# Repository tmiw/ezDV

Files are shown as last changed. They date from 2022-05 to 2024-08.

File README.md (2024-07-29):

# ezDV

This repository contains both the hardware and firmware for a portable battery-powered device that can
(de)modulate [FreeDV](https://freedv.org/) from an attached radio. The board is centered around the 
following components:

* [Espressif ESP32-S3](https://www.espressif.com/sites/default/files/documentation/esp32-s3_datasheet_en.pdf)
* [TLV320 digital audio codec chip](https://www.ti.com/cn/lit/ds/symlink/tlv320aic3254.pdf?ts=1651153824042) produced by Texas Instruments ([application notes](https://www.ti.com/lit/an/slaa408a/slaa408a.pdf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)).

## User's guide

See [here](https://tmiw.github.io/ezDV/) for the latest copy of the user manual for ezDV, which describes its
general use and operation.

## Building the firmware

Install [ESP-IDF v5.3](https://docs.espressif.com/projects/esp-idf/en/v5.3/esp32s3/get-started/index.html) and then run the following:

```
. /path/to/esp-idf/export.sh
git submodule update --init --checkout --recursive
cd firmware
idf.py build
```
## Flashing the firmware

### Using ESP-IDF

Turn on ezDV (see below) and plug it into your computer's USB port, then run the following:

```
idf.py -p /dev/ttyxxx0 flash monitor
```

Where `/dev/ttyxxx0` (or `COMx:` on Windows) is the serial port created by your operating system after plugging ezDV in.

### Using ESP Flash Tool

On Windows, you can use the ESP Flash Tool to flash ezDV. This does not require installation of ESP-IDF.

1. Download the ESP Flash Tool from https://www.espressif.com/en/support/download/other-tools.
2. Decompress all of the files in the ZIP file and execute flash\_download\_tool\_3.9.3.exe.
3. Select "ESP32-S3" for "ChipType", "Develop" for "WorkMode" and "USB" for "LoadMode" as shown below:

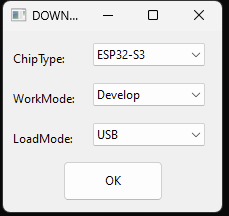
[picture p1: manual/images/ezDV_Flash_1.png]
ESP Flash Tool step 3


4. Add rows for each of the .bin files in the resulting screen:

| File Name | Offset |
|---|---|
| bootloader.bin | 0x0 |
| partition-table.bin | 0x8000 |
| ota\_data\_initial.bin | 0xF000 |
| ezdv.bin | 0x20000 |
| http_0.bin | 0x7F8000 |

Additionally, check each of the checkboxes to the left of the file name. It should look something like this, with each of the rows having a green background:

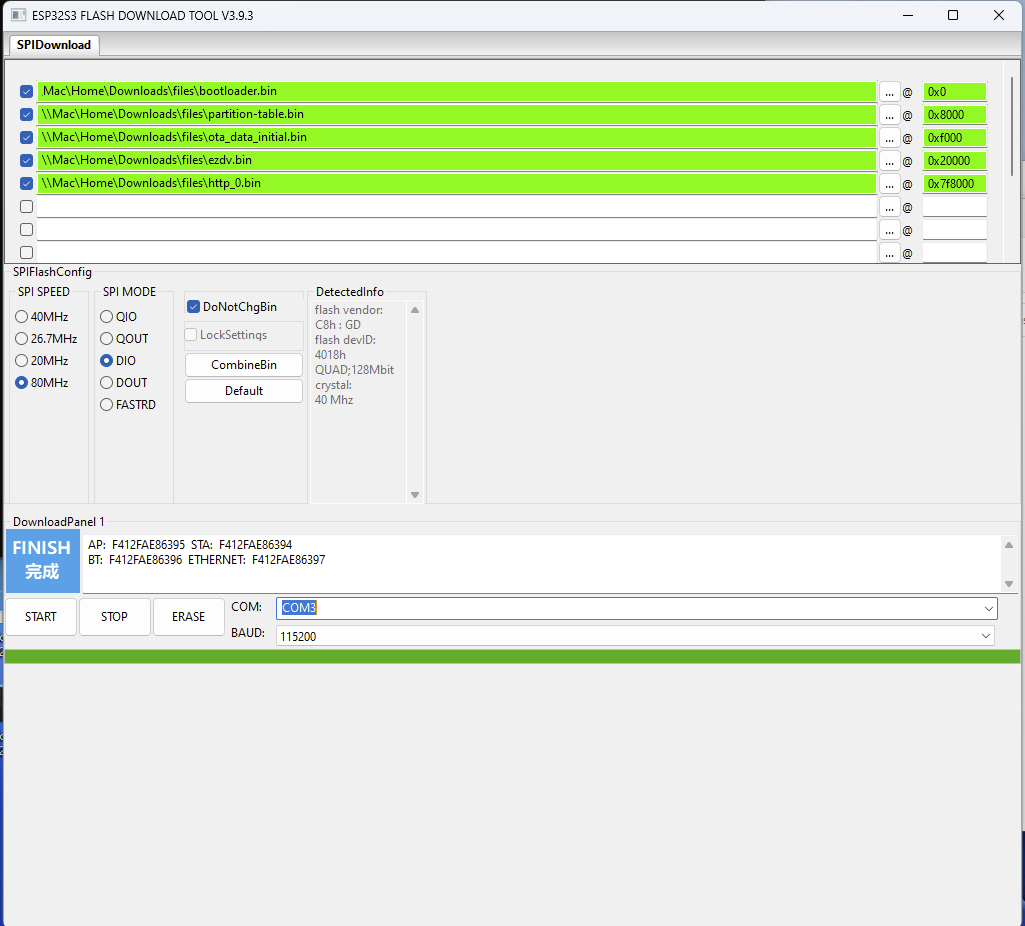
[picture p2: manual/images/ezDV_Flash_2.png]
ESP Flash Tool step 4


5. Set "SPI SPEED" to "80 MHz" and "SPI MODE" to "DIO".

6. Plug ezDV into your computer using a USB-C cable and turn it on by holding down the Mode button for a few seconds. Device Manager should show a new COM port named "USB/JTAG serial debug unit" or similar. Enter this COM port into the "COM" field in the application.

7. (Optional) Push the ERASE button. This will show a green "SYNC" indicator for a bit followed by "Download" and then "FINISH" as per the above screenshot. *Note: There will be no firmware installed on the board once this step finishes. You will need to reconfigure ezDV after new firmware has been flashed.*

8. Push the START button. This will go through the same indicators as step 1 but this time will also have a progress bar indicating how far it's gotten in flashing the new software. 

9. Push the STOP button and then close the application. Open the ezDV enclosure and briefly push/release the "Reset" button on the right hand side of the board. If everything went well, you'll see the four LEDs light up for a few seconds indicating that ezDV is booting normally.

### Using esptool

You can also use [esptool](https://github.com/espressif/esptool). For example:

```
esptool esp32s3 -p /dev/cu.usbmodem14101 -b 460800 --before=default_reset --after=hard_reset write_flash --flash_mode dio --flash_freq 80m --flash_size detect 0x0 bootloader.bin 0x20000 ezdv.bin 0x8000 partition_table/partition-table.bin 0xf000 ota_data_initial.bin 0x7f8000 http_0.bin
```

### Recovering from a bad flash

If the flash process fails (or you are flashing for the first time), you can manually place ezDV into flash mode by holding down the "GPIO0/Flash" button while pushing the "Reset" button on the board. Hold "GPIO0/Flash" for a second or so after releasing Reset, then release. You can then use ESP-IDF, the ESP Flash Tool or esptool to flash ezDV with working firmware.

## Contributing to ezDV

Pleae read the [Theory of Operation](https://github.com/tmiw/ezDV/blob/main/THEORY_OF_OPERATIONS.md) document for more information about the general hardware and software architecture, along with information about how to contribute changes to ezDV.

## License

This project is subject to the terms of the [TAPR Open Hardware License v1.0](https://tapr.org/the-tapr-open-hardware-license/) (schematics, 
other hardware documentation) and [GNU General Public License v3.0](https://www.gnu.org/licenses/gpl-3.0.en.html) (firmware).

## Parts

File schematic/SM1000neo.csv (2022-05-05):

Comment | Designator | Footprint | LCSC
10uF | C1,C2,C3,C4 | Capacitor_SMD:C_0402_1005Metric | C315248
1uF | C5 | Capacitor_SMD:C_0402_1005Metric | C14445
0.1uF | C6,C7,C10,C11,C12 | Capacitor_SMD:C_0402_1005Metric | C1525
47uF | C8,C9 | Capacitor_SMD:C_0603_1608Metric | C140782
PTT_LED | D1 | Diode_SMD:D_0603_1608Metric | C2286
SYNC_LED | D2 | Diode_SMD:D_0603_1608Metric | C165982
OVL_LED | D3 | Diode_SMD:D_0603_1608Metric | C2286
NET_LED | D4 | Diode_SMD:D_0603_1608Metric | C193191
Radio_Jack | J1 | Connector_Audio:Jack_3.5mm_PJ320D_Horizontal | C95562
User_Jack | J2 | Connector_Audio:Jack_3.5mm_PJ320D_Horizontal | C95562
nanoESP32-S3-Left | J3 | Connector_PinHeader_2.54mm:PinHeader_1x21_P2.54mm_Vertical
nanoESP32-S3-Right | J4 | Connector_PinHeader_2.54mm:PinHeader_1x21_P2.54mm_Vertical
MBT3904DW1T1 | Q1,Q2,Q3 | Package_TO_SOT_SMD:SOT-363_SC-70-6 | C110150
2.7K | R1,R11,R16,R18,R19,R21 | Resistor_SMD:R_0603_1608Metric | C269437
100 | R10,R17 | Resistor_SMD:R_0603_1608Metric | C105588
50 | R14,R20 | Resistor_SMD:R_0603_1608Metric | C2759402
4.7K | R2,R8,R22,R24 | Resistor_SMD:R_0603_1608Metric | C99782
1M | R23,R25 | Resistor_SMD:R_0603_1608Metric | C22935
10 | R3 | Resistor_SMD:R_0603_1608Metric | C25202
27 | R4,R5,R6,R7 | Resistor_SMD:R_0603_1608Metric | C25190
3.3K | R9,R12,R13,R15 | Resistor_SMD:R_0603_1608Metric | C22978
PTT_Button | SW1 | Button_Switch_SMD:SW_SPST_TL3342 | C2886898
Mode_Button | SW2 | Button_Switch_SMD:SW_SPST_TL3342 | C2886898
Vol_Up_Button | SW3 | Button_Switch_SMD:SW_SPST_TL3342 | C2886898
Vol_Down_Button | SW4 | Button_Switch_SMD:SW_SPST_TL3342 | C2886898
TLV320AIC3254IRHBR | U1 | SM1000neo:IC_ADS125H01IRHBT | C9925

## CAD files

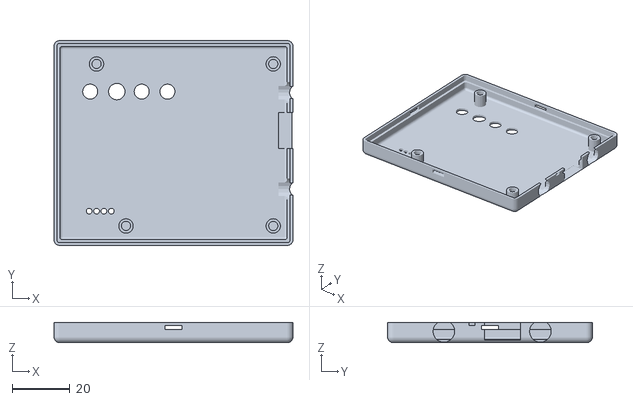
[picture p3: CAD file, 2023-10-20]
enclosure/user/enclosure-top.stl
82.5 x 70.7 x 6.98

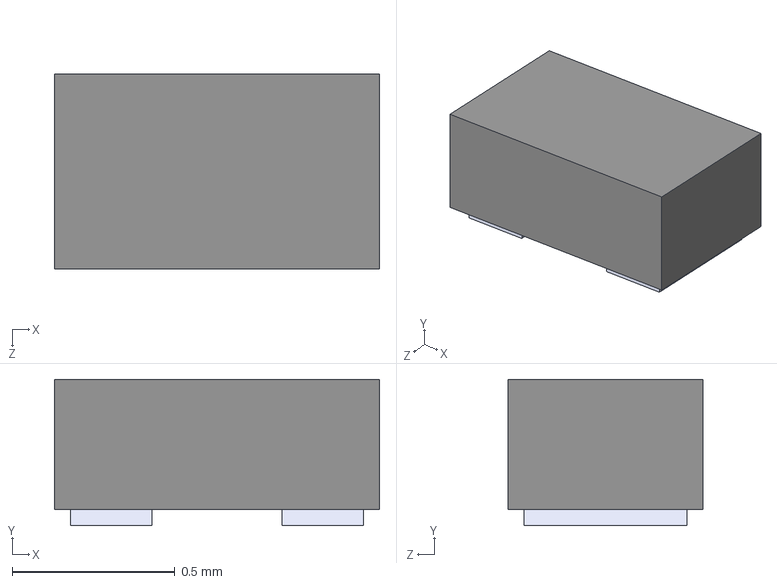
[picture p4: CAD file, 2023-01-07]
schematic/v0.7/TPD1E10B06DPYR.step
1.00 x 0.45 x 0.6 mm

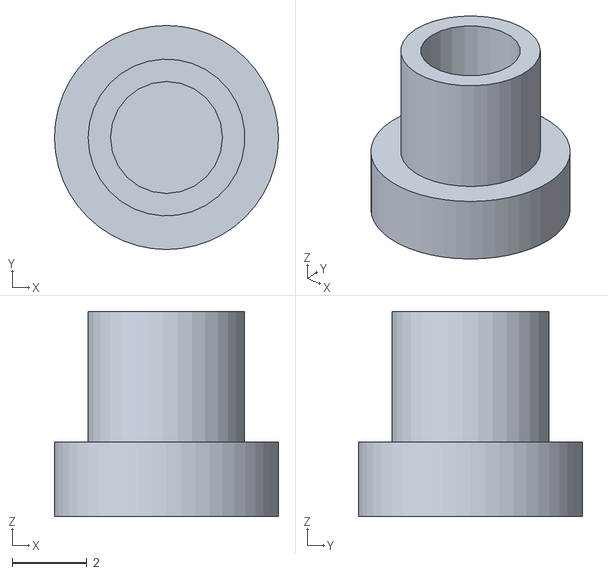
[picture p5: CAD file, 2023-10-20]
enclosure/user/enclosure-button.stl
6.00 x 6.00 x 5.50

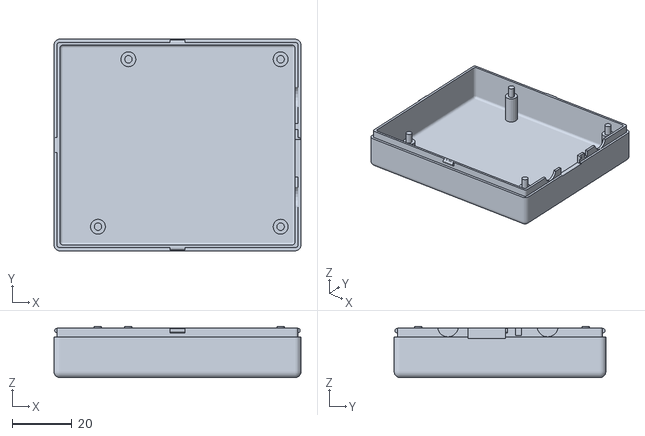
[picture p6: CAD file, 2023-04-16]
enclosure/user/enclosure-bottom.stl
82.5 x 70.7 x 17.1

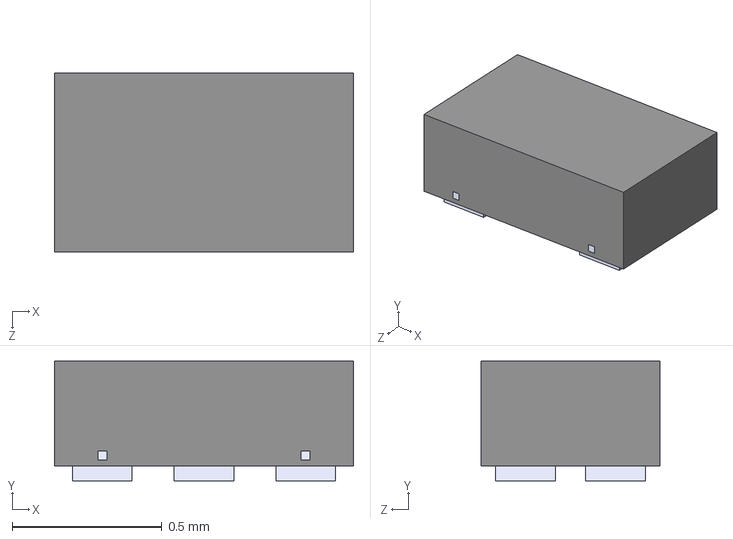
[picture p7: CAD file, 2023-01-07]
schematic/v0.7/ESD122DMXR.step
1.00 x 0.4 x 0.6 mm

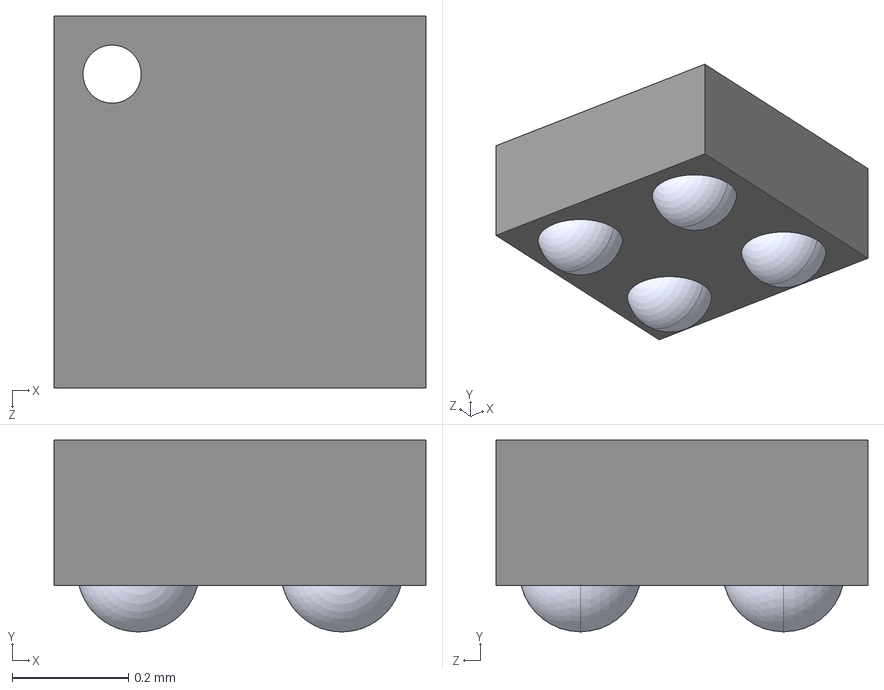
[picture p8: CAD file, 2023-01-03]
schematic/v0.7/BGA4N35P2X2_64X64X33N.step
0.64 x 0.33 x 0.64 mm

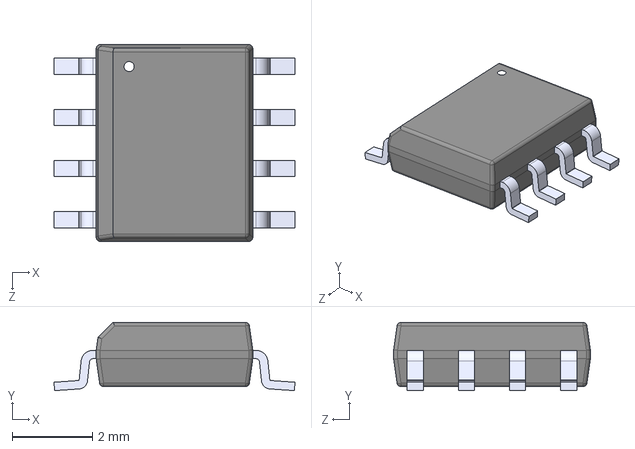
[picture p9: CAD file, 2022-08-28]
schematic/v0.7/TP4056.step
6.00 x 1.70 x 4.90 mm

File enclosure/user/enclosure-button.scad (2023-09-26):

// Makes the preview renders look better.
$fa = 1;
$fs = 0.4;

// Whether to print a taller buttons (typically used when printing the taller enclosure).
printTallerButtons = false;

rotate([0, 180, 0]) {
    translate([0, 0, -3]) {
        if (printTallerButtons) {
            difference() {
                cylinder(h = 15, r = 2.1, center = true);
                translate([0, 0, -12]) cylinder(h = 10, r = 1.5, center = true);
            }
        } else {
            difference() {
                cylinder(h = 5, r = 2.1, center = true);
                translate([0, 0, -4]) cylinder(h = 10, r = 1.5, center = true);
            }
        }
    }

    translate([0, 0, printTallerButtons ? 3.5 : -1]) {
        cylinder(h = 2, r = 3, center = true);
    }
}

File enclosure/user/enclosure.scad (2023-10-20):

// Makes the preview renders look better.
$fa = 1;
$fs = 0.4;

// BEGIN configuration

// Whether to print a taller enclosure to fit e.g. pin headers.
// Note: this weirdly has to be above the include line for some reason.
printTallerEnclosure = false;

include <../library/YAPP_Box/library/YAPPgenerator_v14.scad>

// Which sides to print. Base = bottom, lid = top.
// One or the other can be disabled to print on smaller print beds.
printBaseShell      = false;
printLidShell       = true;

// END configuration

wallThickness       = 2.0;
basePlaneThickness  = 2.0;
lidPlaneThickness   = 1.0;

// Total height of box = basePlaneThickness + lidPlaneThickness 
//                     + baseWallHeight + lidWallHeight

baseWallHeight      = 14.5;
lidWallHeight = (printTallerEnclosure) ? 14.5 : 3.5;
echo(lidWallHeight);
echo(printTallerEnclosure);

pcbLength           = 69.85;
pcbWidth            = 64.70;
pcbThickness        = 1.6;
                            
// padding between pcb and inside wall
paddingFront        = 1;
paddingBack         = 7.62;
paddingRight        = 1;
paddingLeft         = 1;

// ridge where Base- and Lid- off the box can overlap
// Make sure this isn't less than lidWallHeight
ridgeHeight         = 3;
ridgeSlack          = 0.2;
roundRadius         = 2.0;  // don't make this to big..

//-- How much the PCB needs to be raised from the base
//-- to leave room for solderings and whatnot
standoffHeight      = 11.0;
pinDiameter         = 2.5;
pinHoleSlack        = 0.5;
standoffDiameter    = 5;

pcbStands = [
    [ 5.08, 5.08, yappBoth, yappPin ],
    [ 15.24, 60.96, yappBoth, yappPin ],
    [ 66.04, 5.08, yappBoth, yappPin ],
    [ 66.04, 60.96, yappBoth, yappPin ]
];

cutoutsFront = [
    [14.97, 2.5, 7.5, 7, 0, yappCircle, yappCenter ],
    [48.26, 2.5, 7.5, 7, 0, yappCircle, yappCenter ],
    [21.75, -1.5, 12.5, 7, 0, yappRectangle ],
    [37.56, -0.5, 2, 1, 0, yappRectangle ]
];

snapJoins = [
    [(shellLength/2)-2.5, 5, yappLeft, yappRight],
    [(shellWidth/2)-2.5, 5, yappFront, yappBack]
];

cutoutsLid = [
    // Buttons
    /*[3, 14.63, 4, 4, 0, yappRectangle, yappCenter],
    [11.89, 14.63, 4, 4, 0, yappRectangle, yappCenter],
    [20.78, 14.63, 4, 4, 0, yappRectangle, yappCenter],
    [29.67, 14.63, 4, 4, 0, yappRectangle, yappCenter],*/
    
    [2.87, 14.62, 5.2, 5.2, 0, yappCircle, yappCenter],
    [12.06, 14.62, 5.7, 5.2, 0, yappCircle, yappCenter],
    [20.65, 14.62, 5.2, 5.2, 0, yappCircle, yappCenter],
    [29.54, 14.62, 5.2, 5.2, 0, yappCircle, yappCenter],
    
    // Status LEDs
    [2.54, 55.88, 2, 2, 0, yappCircle],
    [5.08, 55.88, 2, 2, 0, yappCircle],
    [7.62, 55.88, 2, 2, 0, yappCircle],
    [10.16, 55.88, 2, 2, 0, yappCircle],
];

YAPPgenerate();

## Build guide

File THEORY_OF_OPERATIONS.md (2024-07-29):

# Theory of Operation

## Introduction

This document describes the general architecture of ezDV and provides details that may be useful for those developers
that want to contribute to the project.

## Hardware Architecture

ezDV uses a ESP32-S3 microcontroller to execute the firmware in this repository. This firmware interfaces with several 
peripherals to perform its basic functionality:

* Texas Instruments TLV320AIC3254 audio codec chip over I2C (to provide configuration information) and I2S (for audio
I/O) to send and receive audio data to a wired headset and/or a radio.
* MAX17048 over I2C to handle battery status measurement (i.e. remaining battery capacity).
* Buttons and LEDs using the ESP32-S3's built-in GPIOs.

## Software Architecture

### System Components

The ezDV firmware is split into several tasks to perform various actions. These tasks are divided into several categories:

* Audio (`firmware/audio`) -- handles higher level audio-related tasks
    * AudioMixer - Mixes two audio streams together
    * BeeperTask - Generates CW beeps based on provided input
    * FreeDVTask - Passes audio to/from the [Codec2](https://github.com/drowe67/codec2) library for encoding and decoding
    * VoiceKeyerTask - Handles voice keyer functionality
* Drivers (`firmware/drivers`) -- handles communication with peripherals
    * ButtonArray - handles processing of interrupts due to button presses
    * LedArray - handles display of built-in LEDs
    * MAX17048 - handles communication with the MAX17048 fuel gauge chip over I2C
    * TLV320 - handles communication with the TLV320 audio codec chip
* Network (`firmware/network`) -- handles logic involving Wi-Fi communication
    * FlexRadio support (`firmware/network/flex`)
        * FlexTcpTask - handles CAT control of a configured Flex radio
        * FlexVitaTask - handles audio I/O (analog and digital) to/from a configured Flex radio
    * Icom support (`firmware/network/icom`)
        * IcomSocketTask - handles UDP connection to one of the Icom remote ports (control, audio, CAT control)
    * Network interfaces (`firmware/network/interfaces`)
        * WirelessInterface - handles bringup/teardown of the built-in Wi-Fi on the ESP32.
        * EthernetInterface - handles bringup/teardown of the W5500 Ethernet module (if attached).
    * FreeDVReporterTask - handles reporting to [FreeDV Reporter](https://qso.freedv.org/)
    * HttpServerTask - handles serving of ezDV's built-in web interface
    * NetworkTask - handles bringup and teardown of the configured network interfaces (Wi-Fi, Ethernet)
* Storage (`firmware/storage`) -- handles configuration and firmware storage
    * SettingsTask - handles storage of configuration settings
    * SoftwareUpdateTask - handles updating of the ezDV firmware from the web interface
* User Interface (`firmware/ui`) -- handles the physical interface with the user
    * FuelGaugeTask - executes when ezDV is turned off (but plugged into USB power) and provides live charging updates via the built-in LEDs
    * RFComplianceTesTask - executes when ezDV is in Hardware Test Mode and provides ways to perform basic validation of the physical hardware
    * UserInterfaceTask - executes when ezDV is turned on normally and directs the rest of the system to perform tasks based on input from buttons

These tasks inherit a thin wrapper around FreeRTOS/ESP-IDF called `DVTask` (located in `firmware/task`) and optionally contain one or more `DVTimer` 
instances if periodic execution of code is required. 

### Inter-Component Messaging

`DVTask` enables the usage of a publish/subscribe model for each task's public interface. This prevents interaction with a task's private data,
reducing the likelihood of certain classes of bugs (such as race conditions). Subscribing to messages is typically done by calling the 
`registerMessageHandler()` method of `DVTask` with the name of the method to call upon receiving a certain type of message. Message handler
methods have a signature similar to the following:

```c++
void ClassName::onHandleMessage_(DVTask* originTask, MessageType* message)
{
    // actions here
}
```

`MessageType` is a class that typically inherits from `DVTaskMessageBase`. `DVTaskMessageBase` is a template class
that takes an integer message ID and a string corresponding to the name of the message category (defined by the `DV_EVENT_DECLARE_BASE`
macro inside the message's .h file and `DV_EVENT_DEFINE_BASE` inside the corresponding .cpp file. For example, in an .h file, you may
have something similar to the following:

```c++
extern "C"
{
    DV_EVENT_DECLARE_BASE(FREEDV_MESSAGE);
}

enum FreeDVMessageTypes
{
    SYNC_STATE = 1,
    // additional message types here
};

class FreeDVSyncStateMessage : public DVTaskMessageBase<SYNC_STATE, FreeDVSyncStateMessage>
{
    // definition here
};
```

and in the .cpp file, you'd have only the following:

```c++
extern "C"
{
    DV_EVENT_DEFINE_BASE(FREEDV_MESSAGE);
}
```

In each message type, the contents of the message are typically defined as public properties as `DVTask` internally
treats them similarly to C structs. Additionally, the size of the message should be known in advance and constant
(for example, the size shouldn't vary based on the length of a string inside the message).

To send a message to a component, tasks typically call the `publish()` method, i.e.

```c++
MessageType message(1, 2, 3);
publish(&message);
```

`publish()` sends the provided message to all tasks that are subscribed to it. Depending on the message type,
this can cause multiple tasks to process the message at the same time. Alternatively, if a task has a pointer
to another, it can use `post()` on the task instead to send only to that task. For example:

```c++
DVTask* destinationTask = getDestinationTask();
MessageType message(1, 2, 3);
destinationTask->post(&message);
```

### Audio Routing

#### Receive

Receive audio is routed through ezDV as follows:

```mermaid
flowchart TD
    A[Radio] -->|RX signal| B(TLV320 input)
    B --> |codec2 FIFO| C(FreeDVTask)
    C --> |Decoded signal| E(AudioMixer)
    D[UserInterface] -->|CW beeps| E
    E --> F(TLV320 output)
    F --> G(Headset)
```

#### Transmit

Transmit audio is routed similarly to receive audio. The main difference is that `AudioMixer` is not used:

```mermaid
flowchart TD
    A[Headset] --> B(TLV320 input)
    B --> |codec2 FIFO| C(FreeDVTask)
    C --> |Encoded signal| D(TLV320 output)
    D -->|TX signal| E(Radio)
```

## Contributing to ezDV

To contribute to ezDV, simply fork this repo and make the required changes, then open a pull request. Note that
for a PR to be merged, the following must currently occur:

* All GitHub actions must pass successfully (i.e. no compiler errors).
* For new/modified functionality, the user manual (in the `manual` folder) must be updated accordingly.

If you have any questions, feel free to reach out in the pull request or by emailing the digitalvoice mailing list.
Thank you for your help in making ezDV even better!

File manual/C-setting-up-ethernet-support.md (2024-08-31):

# Appendix: Setting Up Ethernet Support

Experimental support exists for Ethernet on ezDV. In order to enable Ethernet support, some hardware modifications are required 
to be able to attach it to a [W5500 Ethernet module](https://www.amazon.com/dp/B08KXM8TKJ?psc=1&ref=ppx_yo2ov_dt_b_product_details):

1. Remove the main ezDV board from its enclosure and disconnect the battery from the bottom.
2. Solder wires from the positions indicated below on the ESP32 module (near top of board) to their corresponding locations on the W5500 module:

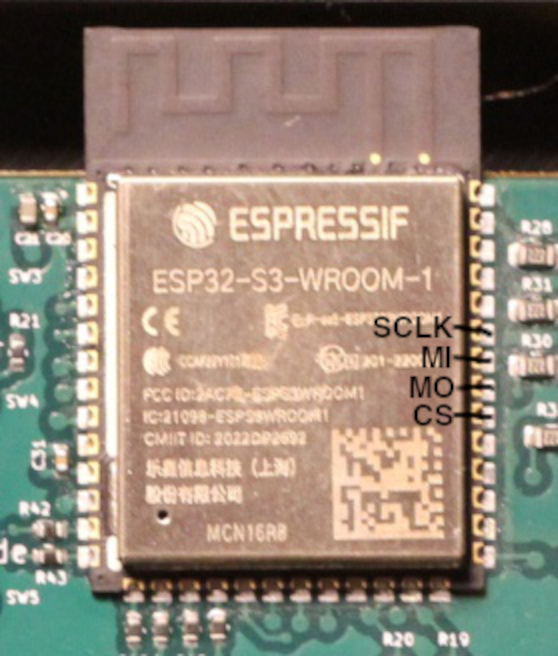
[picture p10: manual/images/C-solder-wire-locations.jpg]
Soldering locations for wires going to W5500 module


3. Solder power and ground wires from ezDV to the W5500. These can be taken from J7 (square pin is 3.3V, bottom pin is GND). Note that J7 is always powered.

4. Reattach the battery and place ezDV back in its enclosure. You may need to cut out a hole in the enclosure using side cutters or similar to allow the previously-soldered wires to be routed out of the enclosure.

5. Attach an Ethernet cable to the W5500 module and to your router or switch. 

6. Turn on ezDV. If Wi-Fi is already configured, it is recommended to disbale it to prevent network connections from inadvertently going over the wrong interface. Once this is done, restart ezDV.

7. After a few minutes, look for it on the router's list of attached devices after a few minutes. Note its IP for future use. It should now be communicating over Ethernet instead of Wi-Fi.

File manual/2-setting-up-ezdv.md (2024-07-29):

# Setting up ezDV

There are several steps required to get ezDV up and running with your radio.

## Initial assembly

If ezDV did not already come with a battery, you will need to obtain a 3.7V lithium polymer (LiPo) battery.
One recommended battery can be purchased [from Amazon](https://www.amazon.com/gp/product/B08214DJLJ/ref=ppx_yo_dt_b_search_asin_title?ie=UTF8&psc=1).

*WARNING: Do not puncture or otherwise damage lithium batteries as injury and/or property damage could result!
Neither the project nor its creator take responsibility for any damage or injury due to misuse of batteries. A 
battery with a protection module (such as the one linked above) is highly recommended.*

The battery should be plugged into the BT1 connector on the bottom of the ezDV circuit board, which is
the circled connector below:

The back of the ezDV circuit board with BT1 circled

Once a battery is attached, you should flip the switch to the right of the BT1 connector upwards (towards the back of the ezDV board)
to connect the battery to the rest of the board. This switch is designed to allow for long-term storage or shipping of ezDV without 
discharging the battery. Note that ezDV may power on immediately after flipping this switch; you can power it down by pushing
and holding the Mode button (second button from the top when looking downward) until red lights turn on on the right-hand side.

*Note: it is not recommended to use this switch for normal operation of ezDV. Some features require an orderly shutdown of ezDV
(which is accomplished by using the Mode button) and may not function properly if power is suddenly lost.*

Next, plug ezDV into a USB-C charger (similar to what would be done to charge a cell phone or portable power bank). A red LED
may light on the bottom of ezDV indicating that the battery is charging as well as some or all of the LEDs on the right hand side
(indicating its current state of charge in 25% increments). When ezDV is done charging, a green LED will turn on
and the red LED will turn off. This may take several hours or more depending on the state of the battery.

Finally, plug in a wired headset on the TRRS jack located on the right side of the ezDV board (when looking
from above). This headset should be wired for compatibility with Android phones, which is as follows:

* Tip: RX audio from ezDV
* Ring 1: RX audio from ezDV
* Ring 2: GND
* Shield: TX microphone audio to ezDV

Once attached, ezDV will appear as follows:

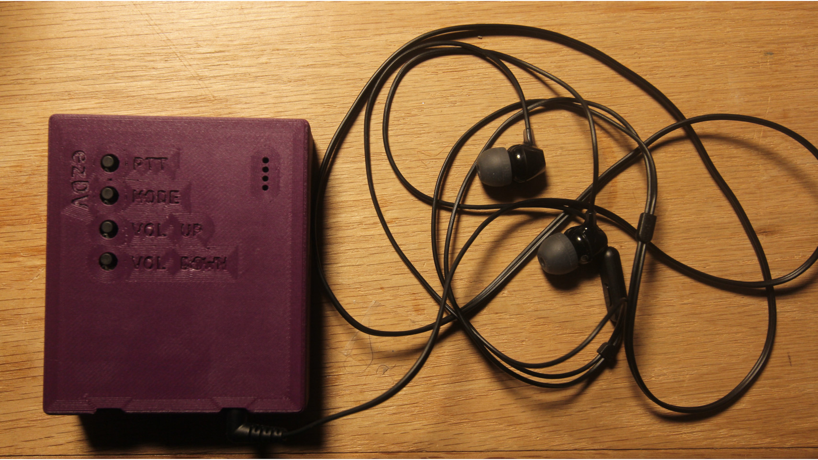
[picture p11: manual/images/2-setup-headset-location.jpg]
ezDV with headset attached


## Radio wiring

### Radios without network support

Radios without network support will need an interface cable. One end of this cable should 
be a male 3.5mm four conductor (TRRS) with the following pinout:

* Tip: TX audio from ezDV to your radio
* Ring 1: PTT to radio (this is connected to GND when you push the PTT button)
* Ring 2: GND
* Shield: RX audio from your radio to ezDV

There is also silkscreen labeling on the back of the board corresponding to the location of 
the radio jack that indicates the pinout. This jack is on the left hand side of ezDV when looking
downward at the front of the device.

More information on example wiring configurations for various radios can be found in the [Example Wiring Configurations](#appendix-example-wiring-configurations)
section.

### Radios with network support

If you have a radio that is capable of remote network access, you can configure ezDV to connect to the radio
over Wi-Fi or Ethernet. Currently this is supported only for the [FlexRadio](https://www.flexradio.com/) 
000/8000 series radios and the Icom IC-705.

#### Flex 6000/8000 series radios

Ensure that you can access your radio using the SmartSDR software from a PC on the same network (i.e. *not* using SmartLink).
Once this is confirmed, skip to [Initial Configuration](#initial-configuration).

#### Icom IC-705

Several settings will need to be adjusted in the IC-705 before it can be used with ezDV. See "Configuring Wi-Fi on the Icom IC-705"
or your radio's user manual for more information on configuring Wi-Fi.

## Initial configuration

To perform initial configuration of ezDV, push and hold both the Mode and Volume Down buttons at the same
time until all four of the LEDs on the right hand side of ezDV turn on.

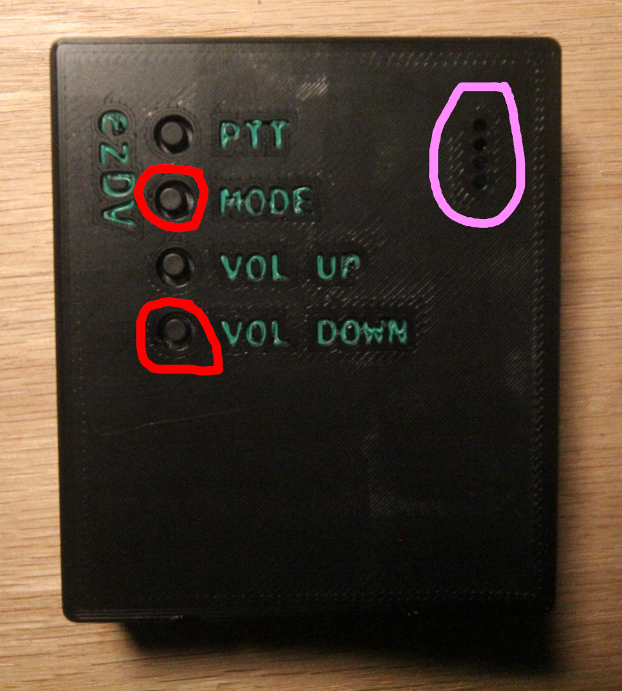
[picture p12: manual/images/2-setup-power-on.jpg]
ezDV showing the buttons to push and hold (red circles) and the location of the LEDs (pink circle)


Once the LEDs turn off, go to your PC or cell phone's Wi-Fi configuration and join a network named "ezDV xxxx",
where "xxxx" is the last few alphanumeric digits of its MAC address (a unique identifier for each network device). 
Once joined, open your Web browser and navigate to http://192.168.4.1/. You should see a page similar to the following:

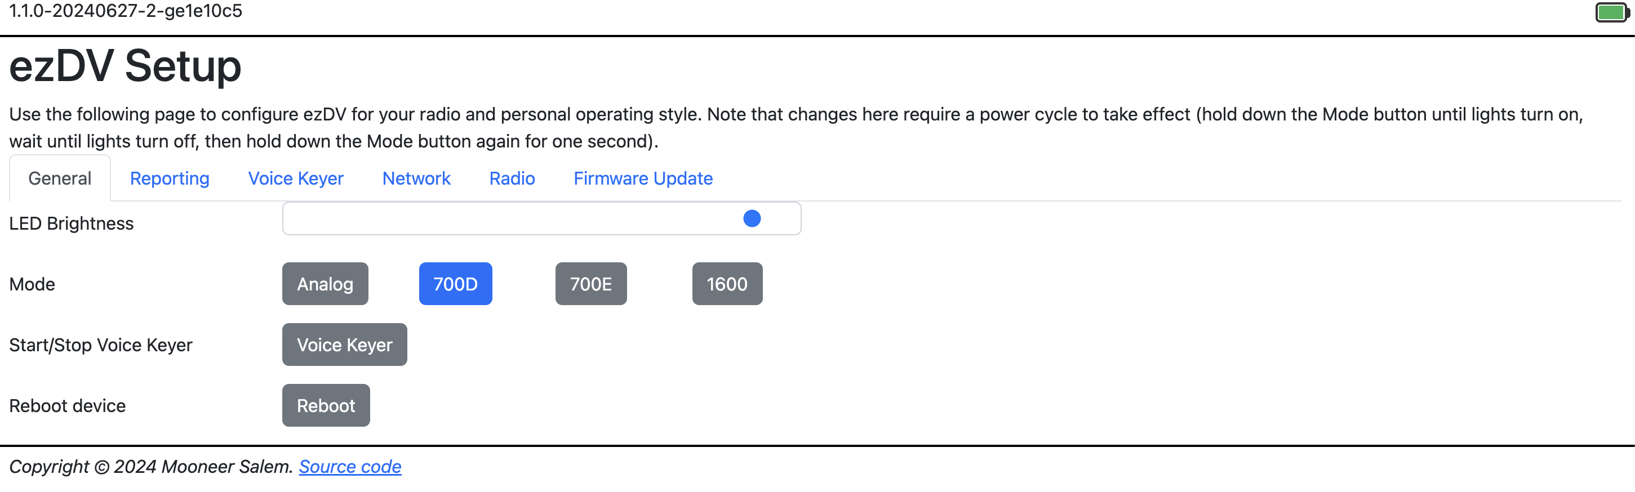
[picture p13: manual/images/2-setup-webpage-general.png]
Screenshot showing ezDV's main Web page


### Transmit audio levels

#### Flex 6000/8000 series

ezDV uses a hardcoded transmit level when connected to the Flex 6000/8000 series of radios, so adjusting the transmit level on 
ezDV has no effect.

#### Other radios

*Note: for the Icom IC-705, this can only be done after configuring Wi-Fi and the radio connection.*

ezDV's transmit audio levels will need to be adjusted to ensure that your radio does not indicate too much ALC, similar
to other HF digital modes. You can adjust the transmit audio by pushing the Volume Up or Volume Down buttons
while holding the PTT button as indicated below:

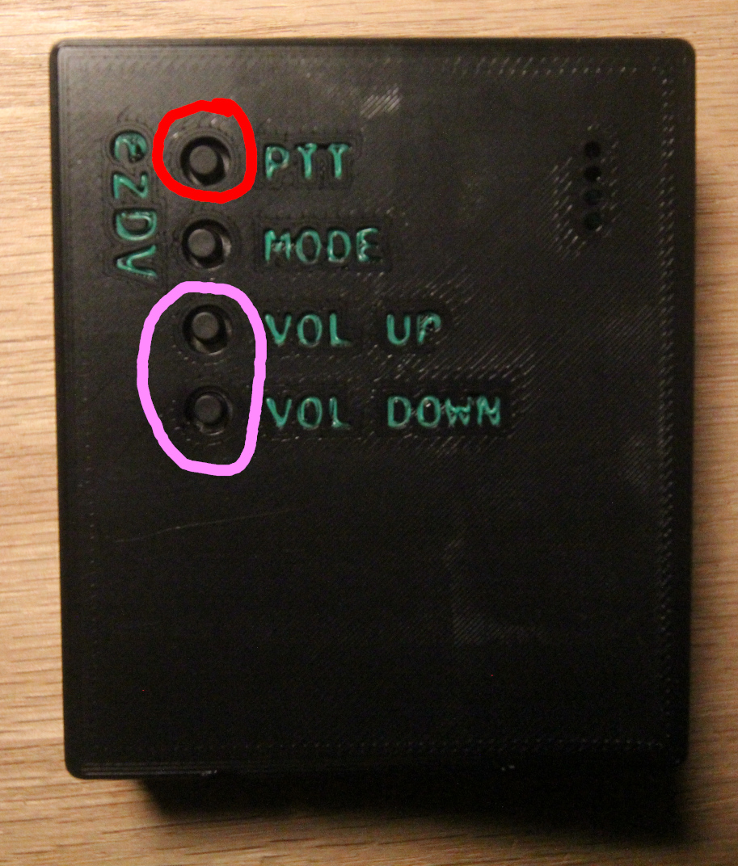
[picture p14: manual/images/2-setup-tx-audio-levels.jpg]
ezDV showing the PTT button (red circle) and the Volume Up/Down buttons (pink circle)


For most radios, ezDV's transmit level should be such that little to no ALC is indicated on the radio display. The specific 
ALC level required depends on the radio, so your radio's user manual is the best source for determining this. Alternatively,
you can increase the TX audio level until your power output stops increasing, then decrease it again until your power output
begins to decrease.

*Note: it's recommended to have your radio attached to a dummy load while adjusting your transmit audio levels to prevent
interference to other operators.*

### Network configuration

*Note: this is optional unless you are using a radio with network support or wish to use other Internet connected features
(such as reporting to [FreeDV Reporter](https://qso.freedv.org/) and [PSK Reporter](https://pskreporter.info)).*

Click or tap on the "Network" tab and check the "Enable Wi-Fi" checkbox. You'll see something similar to the following:

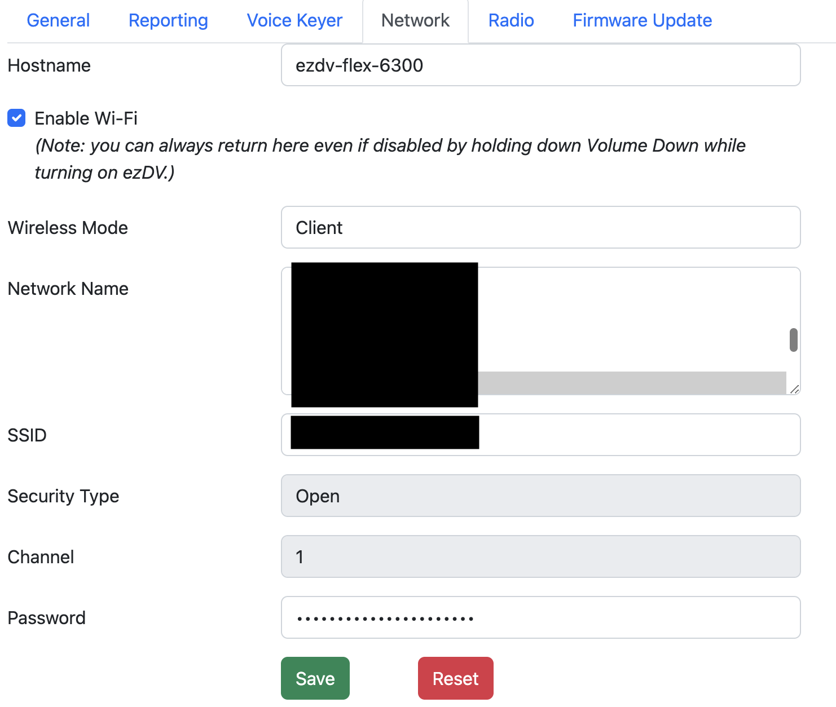
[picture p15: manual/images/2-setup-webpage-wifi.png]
ezDV showing the Network tab


*Note: experimental support exists for Ethernet on ezDV. See "Setting Up Ethernet Support" for more information.*

To connect ezDV to the network that your radio is on, select "Client" for "Wireless Mode". Select your Wi-Fi network from
the list that appears (which may take a few seconds while ezDV scans for your network) and enter its password (if required).
If desired, you can also change ezDV's name by modifying the "Hostname" field; this may allow you to access ezDV later by entering
this name instead of trying to find its IP address. Click or tap Save to save your Wi-Fi settings.

### Radio connection

*Note: this is optional unless you are using a radio with Wi-Fi support.*

Click on the "Radio" tab and check the "Use Network for Radio RX/TX" checkbox. Select your radio model in the "Radio Type"
drop-down list, which will bring up different fields depending on the radio being configured.

#### Flex 6000/8000 series

Select the name of your radio from the "Radio" drop-down list as shown below. Your radio's IP address should automatically
be filled in the "IP Address" field:

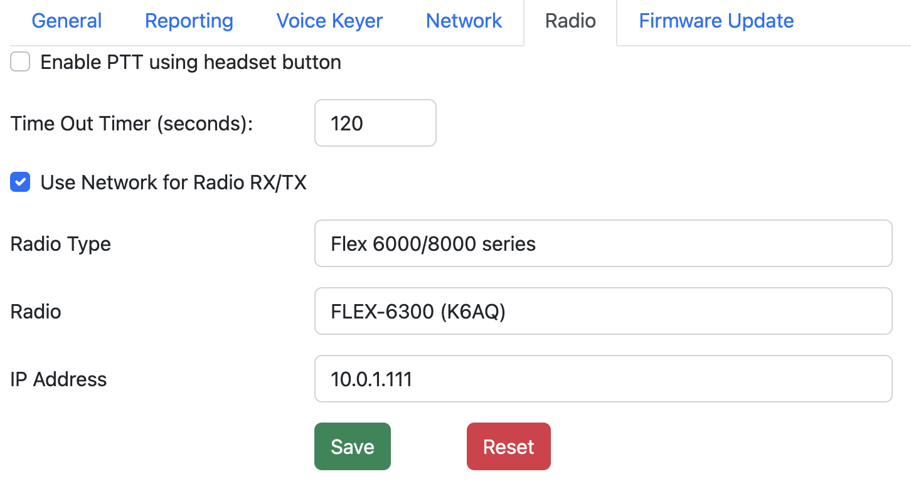
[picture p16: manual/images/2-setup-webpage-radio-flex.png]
ezDV showing a FlexRadio configuration


Click or tap Save to save the radio configuration.

#### Icom IC-705

Enter your radio's IP address, username and password that you saved when you configured Wi-Fi on the IC-705:

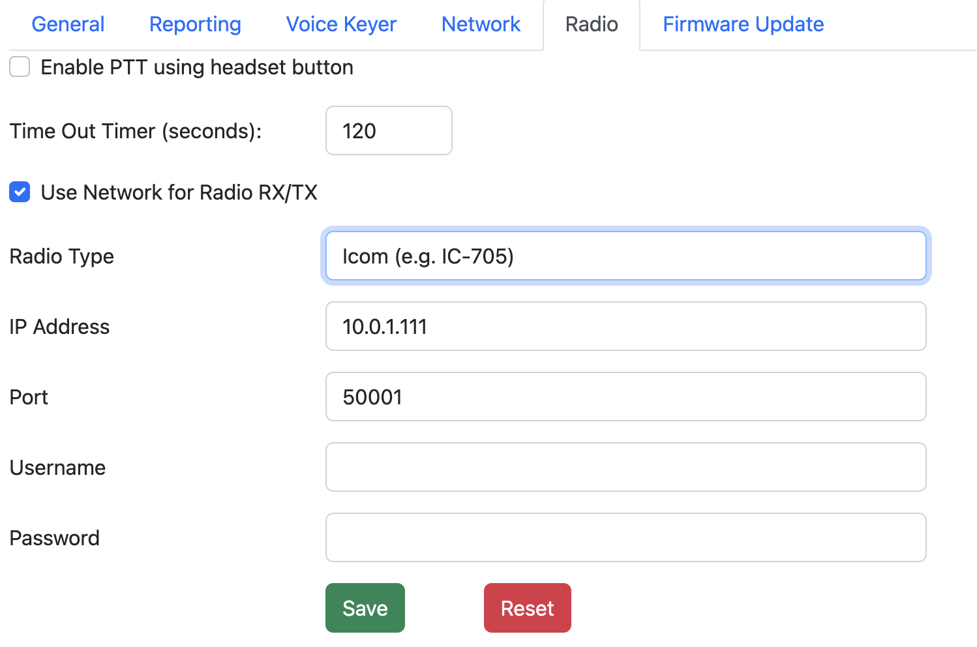
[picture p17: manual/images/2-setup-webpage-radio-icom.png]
ezDV showing a Icom IC-705 configuration


Click or tap Save to save the radio configuration.

### Reporting configuration

It is highly recommended to configure your callsign and grid square. This has several benefits:

1. If ezDV is lost or stolen, someone can access its Web page and use callsign databases like [QRZ](https://www.qrz.com) to find a way to get it back to you.
2. Other users will be able to decode your callsign and report spots on [FreeDV Reporter](https://qso.freedv.org) and [PSK Reporter](https://pskreporter.info).
3. If ezDV has Internet access, it will also be able to decode callsigns from received signals and report them itself to FreeDV Reporter and PSK Reporter.

To do this, click or tap on the "Reporting" tab and enter your callsign and grid square where prompted:

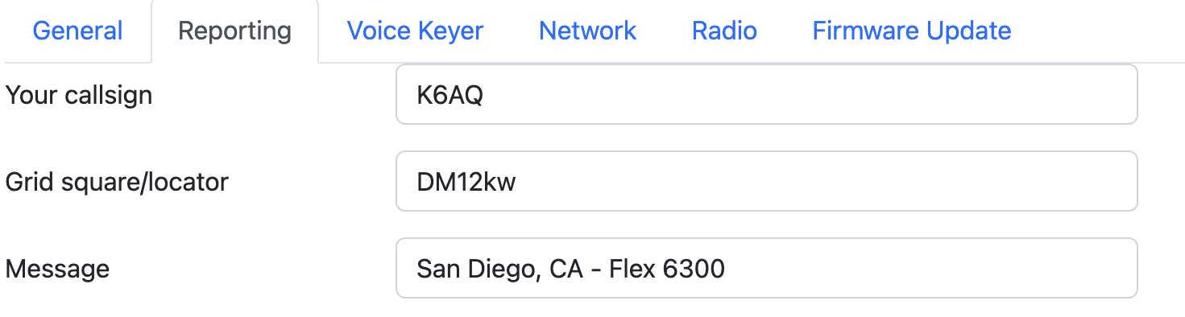
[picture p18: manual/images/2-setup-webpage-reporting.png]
ezDV showing a sample reporting configuration


If desired, you can also enter a short message that will appear on FreeDV Reporter. This message is transmitted solely over the Internet, not over RF.

Once done, click or tap Save to save the reporting configuration.

### Final setup

After your radio, Wi-Fi and reporting configuration are complete, simply click or tap on the General tab and then click or tap on the Reboot button.
ezDV will first show two red LEDs on the right hand side for a few seconds, then show all four LEDs for a few seconds, then turn them all off. If you're
using a wired connection to ezDV, it is now ready for use.

If you configured a Wi-Fi network and radio for ezDV to connect to, ezDV should then begin blinking a blue LED (indicating that it is connected to the Wi-Fi
network) followed by showing a solid blue LED if it's able to connect to the radio. On the IC-705, a WLAN indicator will appear if ezDV is connected to the radio
as shown below:

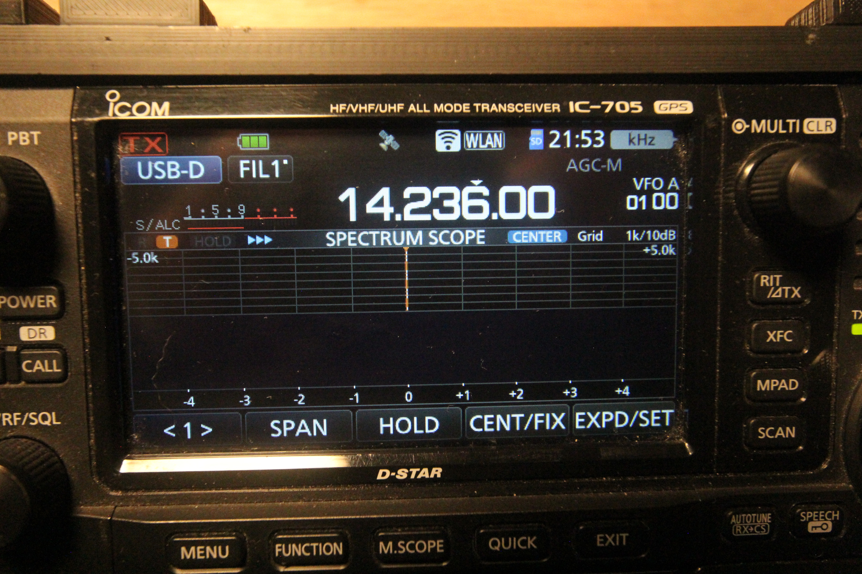
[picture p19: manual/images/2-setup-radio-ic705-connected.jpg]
Icom IC-705 properly connected to ezDV (WLAN indicator at the top of the screen)


For Flex 6000/8000 series radios, opening the SmartSDR software will show a "FDVU" (for upper sideband) and "FDVL" (for lower sideband) mode if ezDV is properly connected
to the radio:

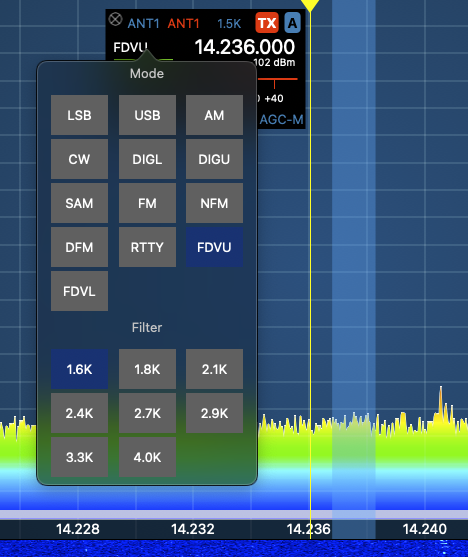
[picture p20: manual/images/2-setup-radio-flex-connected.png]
Flex 6300 properly connected to ezDV (existence of FDVU/FDVL modes)


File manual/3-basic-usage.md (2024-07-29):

# Basic usage

## External controls

ezDV has four buttons on the left, in order from top to bottom:

* Push To Talk (PTT)
* Mode
* Volume Up
* Volume Down

as well as four status LEDs on the right hand side (again from top to bottom):

* PTT (red; on if transmitting)
* Sync (green; on if ezDV can decode an incoming FreeDV signal)
* Overload (red; on if the incoming RX/TX audio is clipping)
* Network (blue; will blink if it has a network connection and will be solid if connected to the radio)

These controls and LEDs are shown below:

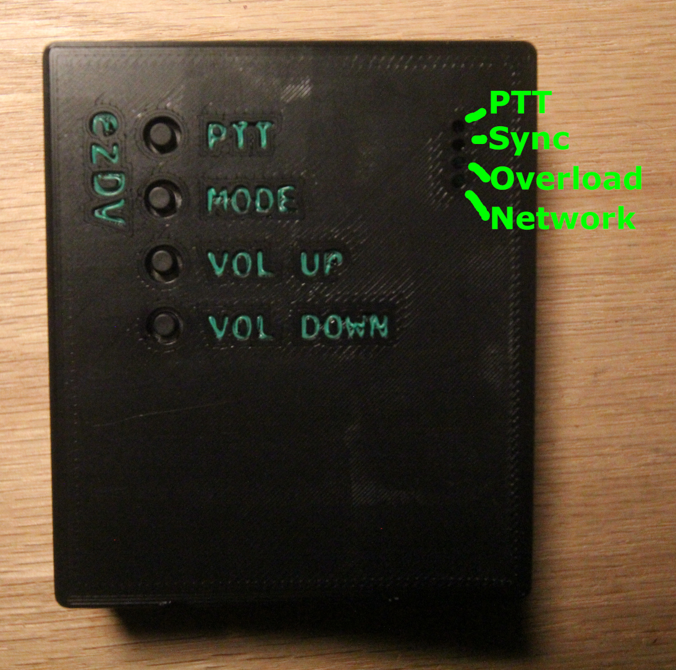
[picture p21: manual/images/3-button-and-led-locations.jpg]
ezDV button and LED locations


## Powering ezDV on and off

To turn on ezDV, press and hold the Mode button for more than 1 second. All four LEDs on the right hand side
of the board should light briefly and then extinguish. You will also hear the last used
mode in Morse Code on your wired headset or through SmartSDR if using a Flex radio. (On first start, this
will be "700D", which corresponds to FreeDV 700D mode.) Holding this button again for more than 1 second will result
in ezDV turning off (with "73" also being piped through the headset in Morse Code, corresponding to the 
well-known ham radio term for "goodbye").

If networking is enabled on ezDV, you will additionally hear the letter "N" emitted in Morse Code
once the network interface comes up. If ezDV is configured to connect to an existing wireless
network or via Ethernet, you will hear the last octet of the IP address immediately afterward. For example,
if your router assigns the IP address "192.168.1.100" to ezDV, you will hear "N100" in the headset.

*Note: if your network is configured with a "netmask" other than "255.255.255.0", you may need to
load your router's configuration to obtain the rest of ezDV's IP address. Otherwise, you can typically replace
the last octet of your computer's IP address with the number after the "N" when accessing ezDV with
a web browser.*

## FreeDV operation

Pushing the Mode button briefly while in receive will cycle through the following modes:

* FreeDV 700D ("700D" will beep in Morse code)
* FreeDV 700E ("700E" will beep in Morse code)
* FreeDV 1600 ("1600" will beep in Morse code)
* Analog passthrough ("ANA" will beep in Morse code)

The current FreeDV mode can also be adjusted using ezDV's web interface if preferred. See 
"Using the web interface" for more information.

Pressing and holding the PTT button will place the radio into transmit mode and transmit
a FreeDV signal out over the air (or your voice verbatim if you are in analog passthrough mode). 
If configured, you can also use the call button on your wired headset to place the radio into transmit;
pushing and releasing the call button will toggle between transmit and receive.

## Radio setup and usage

### Flex 6000/8000 series

To use ezDV, simply start the SmartSDR software on your PC or iPad and select either FDVU mode (for upper sideband) 
or FDVL (for lower sideband). Decoded audio as well as Morse code beeps will be output to your speaker. Use the MOX
button in SmartSDR (or the PTT button on a microphone attached to the radio) to transmit, similar to when operarting 
the other voice modes.

### Others

If your radio has a "data" mode, it's recommended to enable this while using ezDV (or any FreeDV application
or device). This typically disables any processing the radio would normally do for SSB voice, preventing the 
signal from being garbled. Please see your radio's user manual for information about how to enable this mode.

## Volume controls

The Volume Up and Down buttons adjust the receive audio by default. If the PTT button is also held while
pushing Volume Up or Volume Down, the transmit audio level is adjusted instead. For best results, transmit 
audio should be adjusted while in 700D/700E/1600 mode such that the ALC indicator on your radio is just barely
showing (similar to how to configure data modes).

## Voice keyer

If configured, you can activate ezDV's voice keyer functionality by holding down PTT and then pressing the Mode
button. ezDV will then load the voice keyer file in its internal storage and play it back up to the number of
times configured (with it pausing a configured number of seconds). By default, ezDV is configured to transmit
the voice keyer file up to ten times, pausing for five seconds in between each transmission.

While the voice keyer is active, pressing any button on ezDV will stop the voice keyer and place it back into
regular operation. If using a Flex 6000/8000 series radio, you can also stop the voice keyer by pushing the MOX button
in SmartSDR

Configuration of the voice keyer functionality (as well as stopping and starting of the voice keyer) can also be 
done via ezDV's web interface. See [Using the web interface](#using-the-web-interface) for more information.

## Summary of controls

| Button | Action | Also pressed | ezDV behavior |
|---|---|---|---|
| PTT | Hold | (none) | Places radio into transmit and outputs FreeDV signal/analog audio. |
| | Hold | Mode | If voice keyer is configured, activates voice keyer. Otherwise, cycles betweens FreeDV modes. |
| | Hold | Volume Up | Increases transmit audio level. |
| | Hold | Volume Down  | Decreases transmit audio level. |
| Mode | Press | (none) | Cycles between available FreeDV modes and analog passthrough. |
| | Hold* | (none) | Powers up or shuts down ezDV. |
| | Hold* | PTT | When off, powers up ezDV in Hardware Test Mode (see [Troubleshooting](#troubleshooting)). |
| | Hold* | Volume Down  | When off, powers up ezDV with default Wi-Fi settings (see [Using the web interface](#using-the-web-interface)). |
| Volume Up | Press/Hold | (none) | Increases ezDV volume through headset. |
| Volume Down | Press/Hold | (none) | Decreases ezDV volume through headset. |

\* Must be held for at least one second.

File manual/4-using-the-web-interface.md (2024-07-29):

# Using the web interface

ezDV provides a web interface to allow users to adjust its configuration and operate some of its features.
When networking is enabled on ezDV, this interface is accessible through a regular web browser (such as Google Chrome
or Microsoft Edge).

## Accessing the web interface

By default, Wi-Fi on ezDV is disabled for security reasons. To enable it (or recover from a bad configuration), 
hold down the Mode and Volume Down buttons until ezDV turns on. This will cause ezDV to create an access point
named "ezDV" followed by the last two octets of its MAC address. From there, you can connect your PC or mobile
device to that network and open http://192.168.4.1/ in your web browser.

If ezDV is configured to connect to an existing Wi-Fi network (or Ethernet), you can open a web browser on a PC
or mobile device connected to the same network as ezDV and enter ezDV's IP address into the browser's location box. 
This IP address can typically be found in your router's listing of connected devices; ezDV will also beep the letter 
"N" followed by the last octet of the IP address when it connects to the network (for example, "N100" for "192.168.1.100").  

Alternatively, depending on your router, you can also use the configured hostname in your browser instead.
By default, ezDV's hostname is "ezdv", which means that you can enter http://ezdv/ instead of its IP address.

Regardless of how you access ezDV's web interface, you should see a page similar to the below:

Screenshot showing ezDV's main Web page

From here, you can choose one of several tabs:

* General: Contains miscallenous ezDV configuration options.
* Reporting: Configures and operates the reporting feature, which controls reporting to [FreeDV Reporter](https://qso.freedv.org/) and [PSK Reporter](https://pskreporter.info).
* Voice Keyer: Configures ezDV's voice keyer feature.
* Network: Configures how ezDV connects to Wi-Fi.
* Radio: Configures how ezDV connects to your network-enabled radio.
* Firmware Update: Allows the user to perform a firmware update on ezDV.

## Changing FreeDV mode

The web interface provides the ability to change the current FreeDV mode, similar to when pushing the Mode
button on the top of ezDV. To change the current FreeDV mode, simply push one of the mode buttons in the General 
tab:

ezDV mode buttons on web interface

Once pushed, ezDV will behave identically as if the mode was switched using the Mode button, including beeping
the current mode in Morse Code through the wired headset.

## Changing LED brightness

ezDV allows you to change the brightness of the LEDs on the front of the device. This can make ezDV more comfortable
to use at night (for example). This can be done by going to the General tab and moving the LED Brightness slider:

ezDV LED Brightness slider

Changes to the LED Brightness slider take effect immediately and are preserved, so it's not necessary to readjust
every time ezDV is powered off and then on again.

## Using and configuring the voice keyer

To activate and deactivate the voice keyer, you can push the Voice Keyer button in the General tab. When active,
the Voice Keyer button will turn red as shown below:

Voice Keyer button when active

Pushing the button again will turn off the voice keyer:

Voice Keyer button when not active

If the voice keyer feature is disabled, the Voice Keyer button will be grayed out. In order to configure the voice
keyer, you will need to go into the Voice Keyer tab:

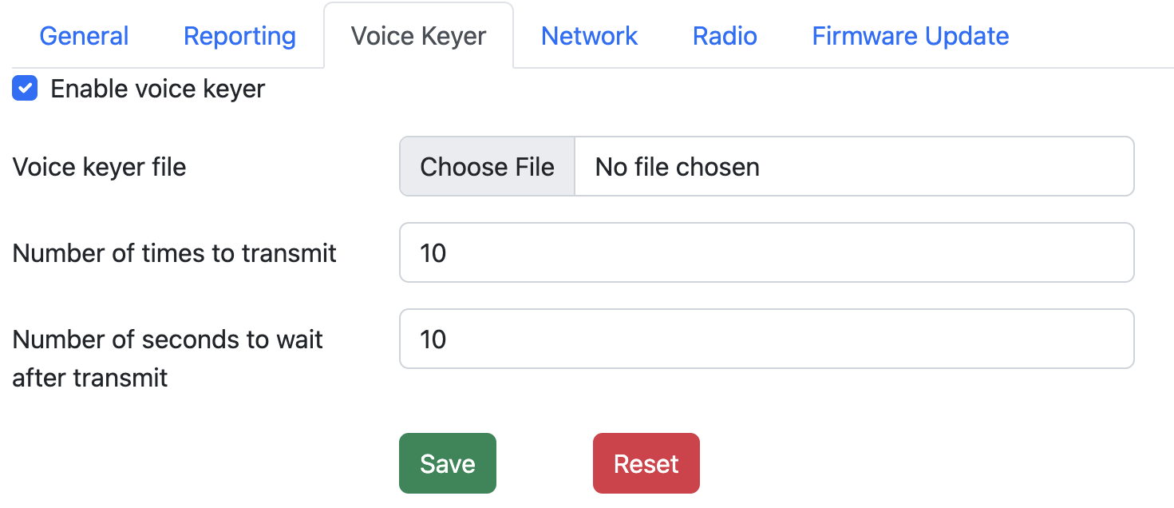
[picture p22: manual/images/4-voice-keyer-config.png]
Voice Keyer tab for configuration


The following can be set here to enable the voice keyer feature:

| Setting | Description |
|---|---|
| Enable voice keyer | When checked, this enables use of the voice keyer. The Voice Keyer button in the General tab will be allowed to be pushed, as well as be able to be activated by pushing on the Mode button on the front of ezDV while holding down PTT. |
| Voice keyer file | Allows uploading of a new voice keyer file. Optional if one has already been uploaded to ezDV.<br/> *Note: ezDV requires a WAV file encoded with a sample rate of 8000 Hz and containing only one audio channel. If a file is uploaded that does not meet these requirements, ezDV will reject the upload.* |
| Number of times to transmit | The number of times that ezDV will transmit the voice keyer file before it disables the voice keyer. You can also disable the voice keyer early by pushing on the Voice Keyer button or pushing on any of the physical buttons on the front of ezDV. |
| Number of seconds to wait after transmit | The number of seconds to wait after transmitting the voice keyer file before starting another transmit cycle. |

Pushing Save will immediately update the voice keyer configuration and enable its use if desired.

## Reporting to FreeDV Reporter/PSK Reporter

ezDV has the ability to report its current state to the [FreeDV Reporter](https://qso.freedv.org/) 
and [PSK Reporter](https://pskreporter.info) spotting services. Operation of this feature can be 
done through the Reporting tab:

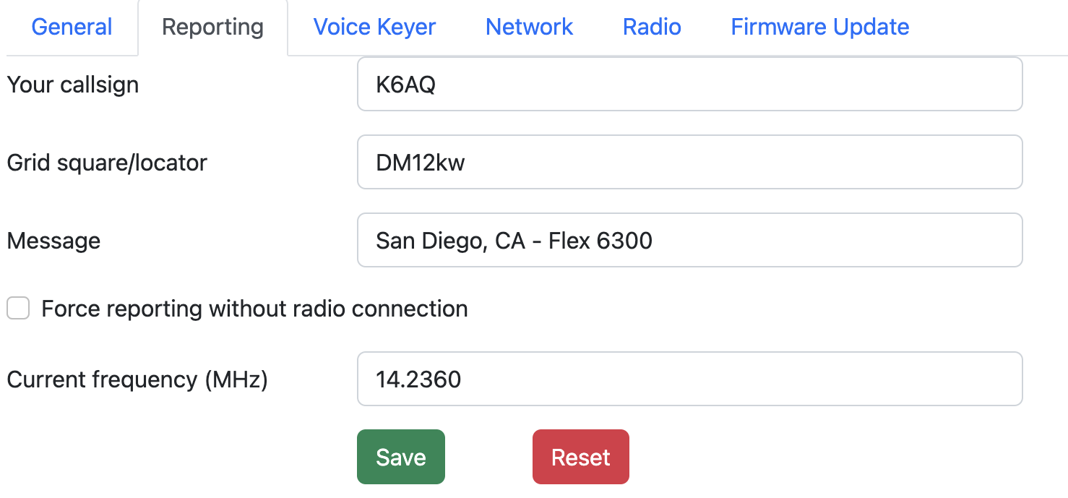
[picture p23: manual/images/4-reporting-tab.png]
Example of a reporting configuration on ezDV


When configured with a callsign and grid square, ezDV will automatically connect to FreeDV Reporter and PSK Reporter
if it has access to an internet connection and is able to connect to a supported radio. You can also force a connection 
to both servies for radios without network support by checking the "Force reporting without radio connection" 
checkbox and manually entering the current frequency.

Once connected to FreeDV Reporter, a new row will appear corresponding to your connection:

Example of an entry on FreeDV Reporter

If ezDV is able to decode a callsign from a received signal, it will transmit the received callsign and SNR to FreeDV
Reporter and PSK Reporter. Your row will then update to indicate the received callsign, SNR and mode as well as highlight 
your row in a blue background for several seconds to alert others that you've receiving a signal. When ezDV is transmitting, 
FreeDV Reporter will also highlight your row with a red background to indicate to others that you're transmitting.

With radios that support connections over the network, ezDV will also follow frequency changes on the radio and report them
to FreeDV Reporter. FreeDV Reporter will then indicate your current frequency, allowing others to change to your frequency
and potentially make a contact with you. Manual frequency updates (for those radios attached to ezDV with a wired connection)
will also be sent to FreeDV Reporter as they're made.

The following can be updated in the Reporting tab to operate reporting:

| Setting | Description |
|---|---|
| Your callsign | The callsign to report to FreeDV Reporter and PSK Reporter. This callsign is also transmitted as part of your FreeDV signal so that others can report receipt of your signal. |
| Grid square/locator | The 4-6 digit grid square to report to FreeDV Reporter/PSK Reporter. You can use a service such as [this](https://www.levinecentral.com/ham/grid_square.php) to calculate your grid square if not known. *Note: Clearing this field disables reporting.* |
| Message | A short message to display on the FreeDV Reporter website next to your callsign. This is transmitted solely on the internet, not over RF. |
| Force reporting without radio connection | When checked, ezDV will connect to FreeDV Reporter/PSK Reporter even without a valid radio configuration. |
| Current frequency (MHz) | When "Force reporting without radio connection" is checked, ezDV will transmit this frequency to FreeDV Reporter/PSK Reporter as your current frequency.|

Pushing Save will immediately connect or disconnect to FreeDV Reporter/PSK Reporter (as desired/required) as well as transmit updates to the current frequency or short message.

## Configuring Wi-Fi

The Network tab allows configuration of ezDV's Wi-Fi connection:

ezDV showing the Network tab

The following can be configured in this screen:

| Setting | Description |
|---|---|
| Enable Wi-Fi | Enables or disables the Wi-Fi radio on ezDV. |
| Hostname | The name to call ezDV on the network (default "ezdv"). Only letters, numbers and '-' can be used for the name. |
| Wireless Mode | Can be either "Client" (to connect to an existing Wi-Fi network) or "Access Point" (to have ezDV generate its own Wi-Fi network). |
| Network Name | The Wi-Fi network to connect to in "Client" mode. ezDV populates this list with the networks that it's able to see, or you can choose "(other)" and manually enter the name of the network in the "SSID" field. |
| SSID | Typically automatically filled in if you select a network in the "Network Name" list. If "(other)" is selected, you can manually enter the name of the Wi-Fi network here (for example, if the network doesn't broadcast its presence). |
| Security Type | In "Access Point" mode, controls the security of the Wi-Fi network ezDV provides. Can be either "Open" (no encryption/security) or one of "WEP", "WPA", "WPA2" or "WPA/WPA2". *Note: WPA2 is recommended for the best security.* |
| Channel | In "Access Point" mode, this controls the 2.4 GHz Wi-Fi channel (1-11) ezDV uses. |
| Password | In "Access Point" mode (and when something other than "Open" is selected for "Security Type"), the password ezDV will require to allow other devices to connect to it. In "Client" mode, this is the password for the network selected or entered in "Network Name"/"SSID". |

Pushing Save here will save these settings to ezDV's internal flash but require rebooting or power cycling ezDV for the settings to take effect.

## Configuring radio connection and headset

The Radio tab allows configuration of ezDV's connection to a network-enabled radio as well as headset-related functions. 
Currently ezDV supports connections to the Icom IC-705 and Flex 6000/8000 series radios, as shown below:

ezDV showing a FlexRadio configuration

ezDV showing a Icom IC-705 configuration

The following can be configured in this screen:

| Setting | Description |
|---|---|
| Enable PTT using headset button | Enables the usage of the "call" button on your wired headset for toggling PTT. (See [Basic usage](#basic-usage)" for more information.) |
| Time Out Timer (seconds) | Configures ezDV's "time out timer", which automatically puts the radio back into receive if the radio is stuck in transmit mode for too long. |
| Use Wi-Fi Network for Radio RX/TX | When checked, allows ezDV to connect to a supported radio over the network instead of using a wired headset. |
| Radio Type | The type of radio that ezDV should connect to. This can be either "Flex 6000/8000 series" or "Icom (e.g. IC-705)". Relevant settings for each radio type will appear in this tab as appropriate. |
| Radio | Displays the list of Flex radios that ezDV is able to see on the network. You can also choose "(other)" and manually enter its IP address. |
| IP Address | For Flex radios, this is typically auto-filled when selecting a radio from the Radio list. Otherwise, this is the IP address of the radio which to connect to. |
| Port | For the IC-705, this is the control port number of the built-in server running on the radio. Defaults to "50001" and should not normally need to be changed. |
| Username | For the IC-705, this is the "Network User1" or "Network User2" user ID. (See [Configuring Wi-Fi on the IC-705](#appendix-configuring-wi-fi-on-the-icom-ic-705) or your radio's user manual for information on configuring these users.) |
| Password | For the IC-705, this is the "Network User1" or "Network User2" password. |

Pushing Save here will save these settings to ezDV's internal flash but require rebooting or power cycling ezDV for the settings to take effect.

## Updating firmware

From time to time, new ezDV firmware may be released that contains feature enhancements and/or bug fixes. These updates are typically posted
on the [project's releases page](https://github.com/tmiw/ezDV/releases) and are announced in various other locations (such as the FreeDV 
mailing lists). ezDV can be upgraded or downgraded by using the "Firmware Update" tab:

ezDV showing the "Firmware Update" tab

To update the firmware, perform the following steps:

1. Download the firmware file ending in "-ota.tar.gz" to your PC and save it to a known location (such as your Downloads folder).
2. Go to ezDV's "Firmware Update" tab and select the file you just downloaded. 
3. Press the "Update" button. *Note: this may take several minutes to complete. Do not close your browser or navigate away from the ezDV web interface while the update is taking place.*

Once complete, the new firmware is stored on ezDV's internal memory but will not take effect until ezDV is turned off and on again or rebooted.

## Rebooting ezDV

You can reboot ezDV from the web interface instead of powering it on and off using the physical controls. This is typically done after saving 
radio or Wi-Fi settings or after uploading new firmware. To do this, go to the General tab and press the Reboot button:

ezDV showing the Reboot button

ezDV may take up to a minute to turn itself off and then turn itself on again. Once the web browser is able to communicate with ezDV again, it 
will automatically refresh the Web interface so that any changes to it due to any firmware updates can be made visible immediately.

*Note: changes to Wi-Fi settings may cause ezDV to no longer be accessible on the IP address that was originally used. See [Accessing the web interface](#accessing-the-web-interface) for 
information on finding its new address if required.*

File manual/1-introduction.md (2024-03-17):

# Introduction

[ezDV](https://github.com/tmiw/ezDV) is a handheld hardware device that allows easy use of [FreeDV](https://freedv.org), whether on the go or at home. 
Powered by an ESP32-S3 microcontroller, its built-in Wi-Fi support allows completely wireless setup (with supported radios) 
along with enabling more modern functionality such as FreeDV Reporter reporting and wireless firmware updates.

For those radios without network capability, interfacing them with ezDV is straightforward through the use of the industry 
standard 3.5mm TRRS audio jack. This jack is configured similarly to what is used with wired headsets for mobile phones. 
Analog audio is also passed in and out from/to your wired headset using a second 3.5mm audio jack.

This document describes the configuration and recommended usage of the ezDV device for maximum enjoyment and minimal
frustration. Hope to hear you on the air!

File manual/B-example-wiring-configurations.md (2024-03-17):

# Appendix: Example wiring configurations

Some example configurations are below.

## Elecraft KX3

If you have an Elecraft KX3, you can use off the shelf parts for your interface cable
(no soldering required). These parts consist of a [3.5mm splitter](https://www.amazon.com/Headphone-Splitter-KOOPAO-Microphone-Earphones/dp/B084V3TRTV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)
and a [3.5mm TRRS cable](https://www.amazon.com/gp/product/B07PJW6RQ7/ref=ppx_yo_dt_b_search_asin_title?ie=UTF8&psc=1). The microphone
connector on the splitter should be plugged into PHONES on the KX3 while the speaker connector should be plugged into MIC.

This setup will look like the following when plugged in:

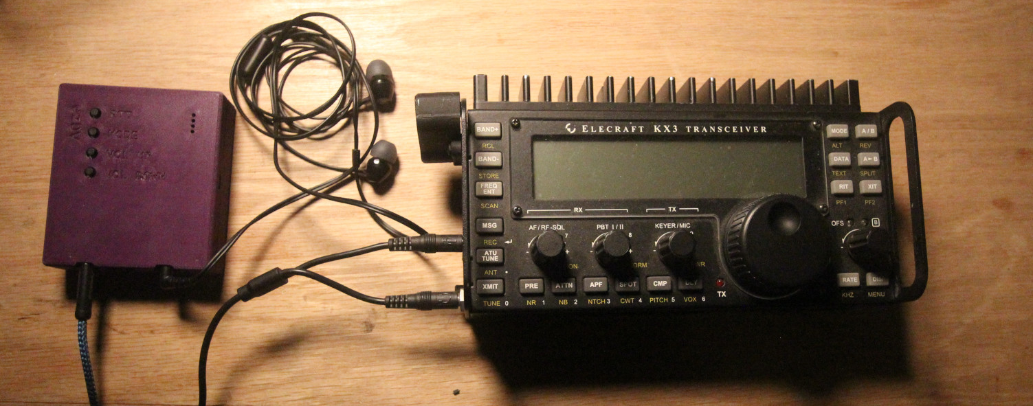
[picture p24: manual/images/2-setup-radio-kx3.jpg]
ezDV plugged into an Elecraft KX3


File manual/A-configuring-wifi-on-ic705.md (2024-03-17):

# Appendix: Configuring Wi-Fi on the Icom IC-705

First, you will need to decide whether you want to join your IC-705 to an existing Wi-Fi network or whether you want to configure 
ezDV to use the IC-705's built-in access point.

*Note: it is recommended to join your IC-705 to an existing Wi-Fi network in order to be able to access ezDV's Web interface
(and to take advantage of certain features if an Internet connection is available).*

Next, you'll need to turn on your radio and push the Menu button. This will bring up the following screen:

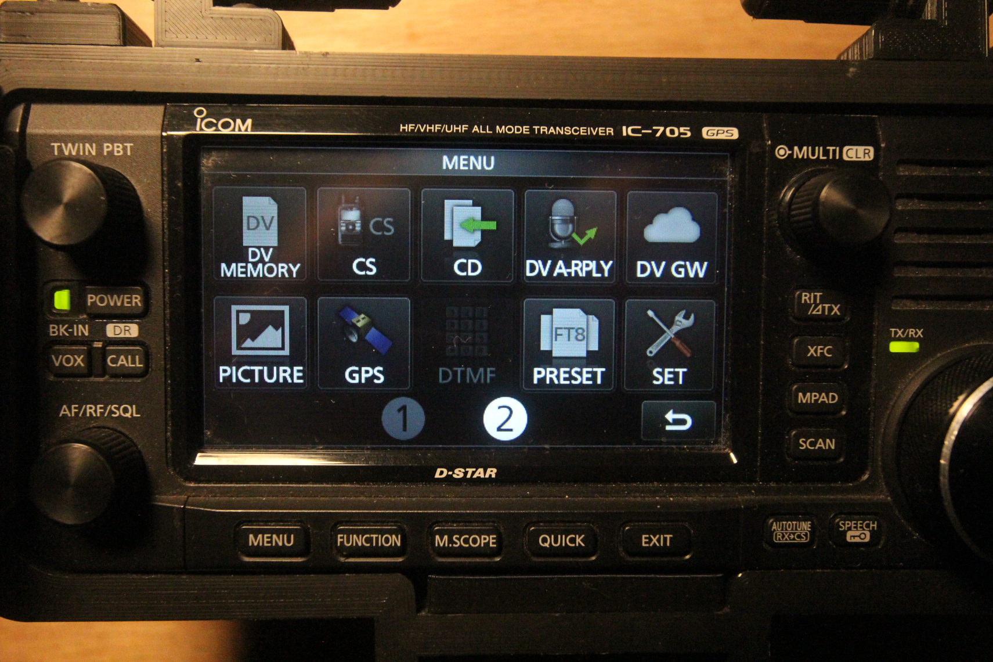
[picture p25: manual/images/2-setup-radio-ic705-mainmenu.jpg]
Icom IC-705 on menu screen


Tap the Set button on the lower-right corner of the display and then select "WLAN Set" as shown below:

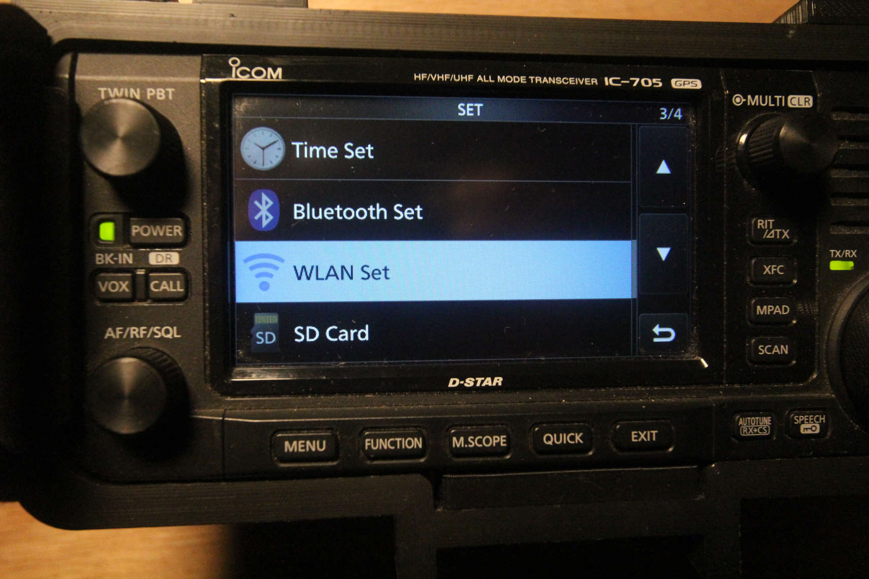
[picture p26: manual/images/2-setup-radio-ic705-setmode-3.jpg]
Icom IC-705 with WLAN Set selected


Next, tap the WLAN option on the first page and turn it OFF. Once switched OFF, tap the Connection Type setting and tap either
Station (for connecting to an existing Wi-Fi network) or Access Point (for connecting ezDV to the IC-705's access point):

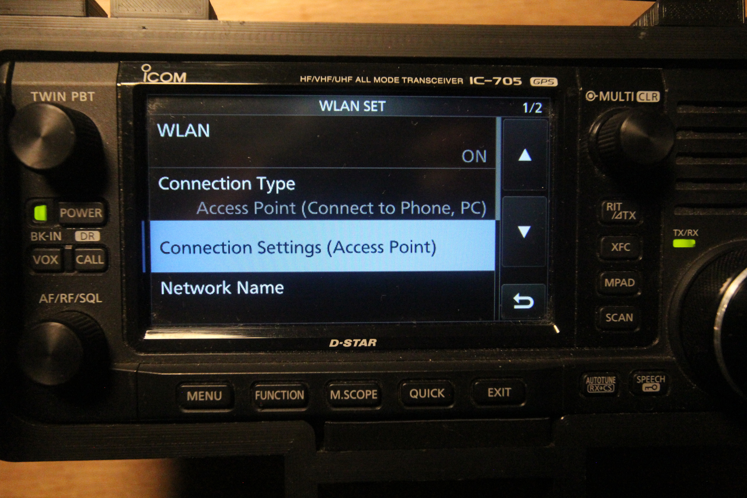
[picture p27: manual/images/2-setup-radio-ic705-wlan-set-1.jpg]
Icom IC-705 displaying WLAN Set options


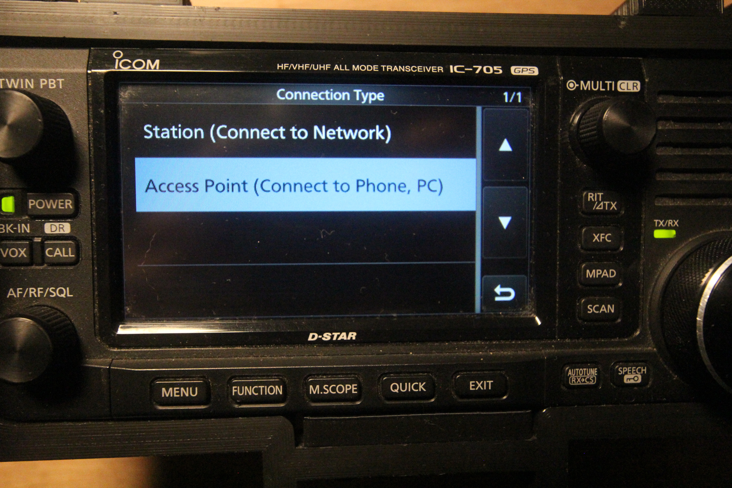
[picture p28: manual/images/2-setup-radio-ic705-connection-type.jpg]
Icom IC-705 displaying Connection Type menu


## Using the IC-705's built-in access point

If you're using the IC-705's Access Point mode, it is a good idea to double-check your radio's SSID (aka Wi-Fi network name) and 
Wi-Fi password by tapping "Connection Settings (Access Point)" and then tapping each option as shown below, updating them as needed:

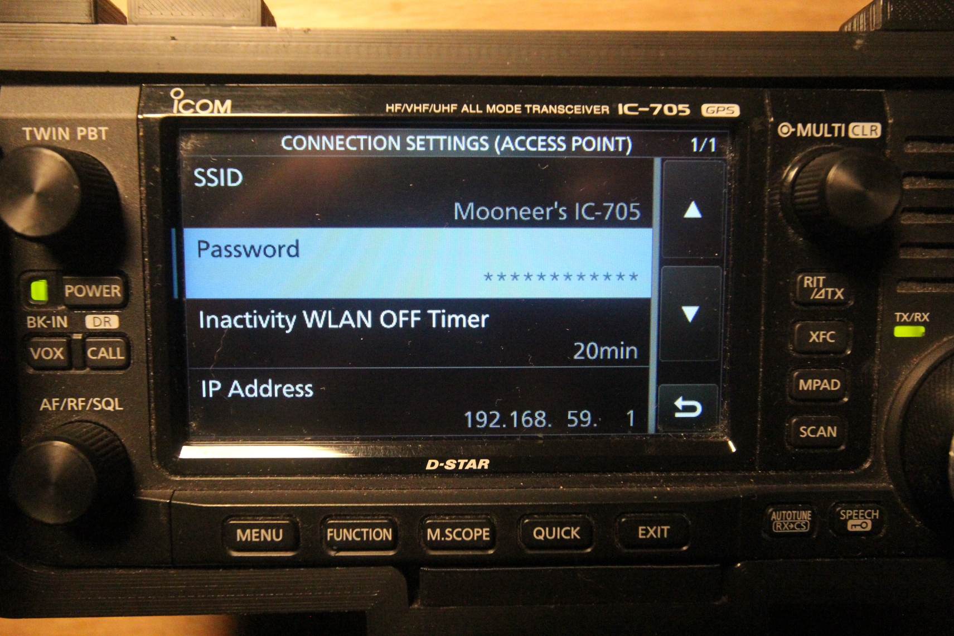
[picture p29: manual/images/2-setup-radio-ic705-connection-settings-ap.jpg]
Icom IC-705 displaying Access Point settings


Also, note the IP address that your IC-705 is using on this page as you will need it for later configuration of ezDV. Once the settings
here are satisfactory, tap the Back button on the lower right hand corner of the screen, tap the WLAN option and then change it to ON.

## Connecting the IC-705 to an existing network

First, tap the WLAN option on the WLAN Set page and change it to ON. This is needed in order to turn on the Wi-Fi radio in the IC-705
and allow it to scan for networks.

Next, tap "Connection Settings (Station)". You will see the following page on the IC-705:

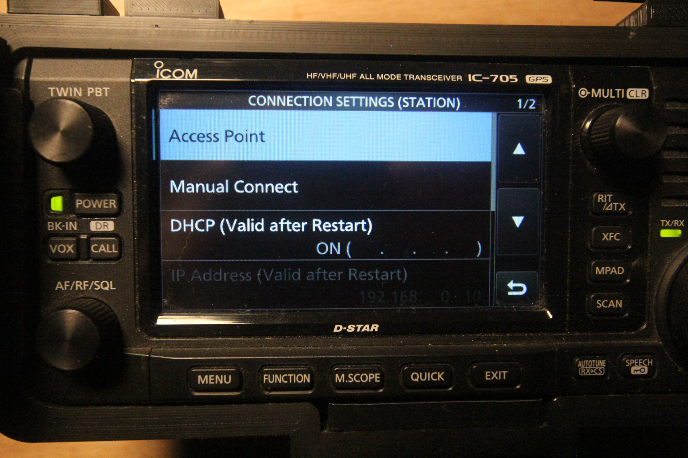
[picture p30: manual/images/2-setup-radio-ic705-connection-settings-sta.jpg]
Icom IC-705 displaying the Connection Settings (Station) page


From here, you can either tap "Access Point" to select your network from a list or "Manual Connect" if it's not broadcasting
its name. Tapping "Access Point" will bring up a page similar to the following:

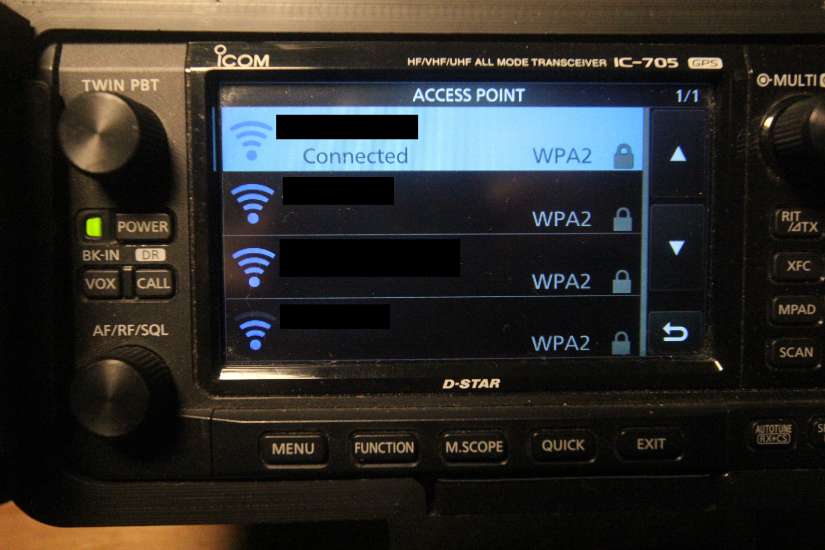
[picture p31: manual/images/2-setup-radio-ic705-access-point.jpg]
Icom IC-705 displaying a list of Wi-Fi networks


Tap your preferred network from the list that appears. If it's not already saved in the IC-705, you may see a page similar
to the following:

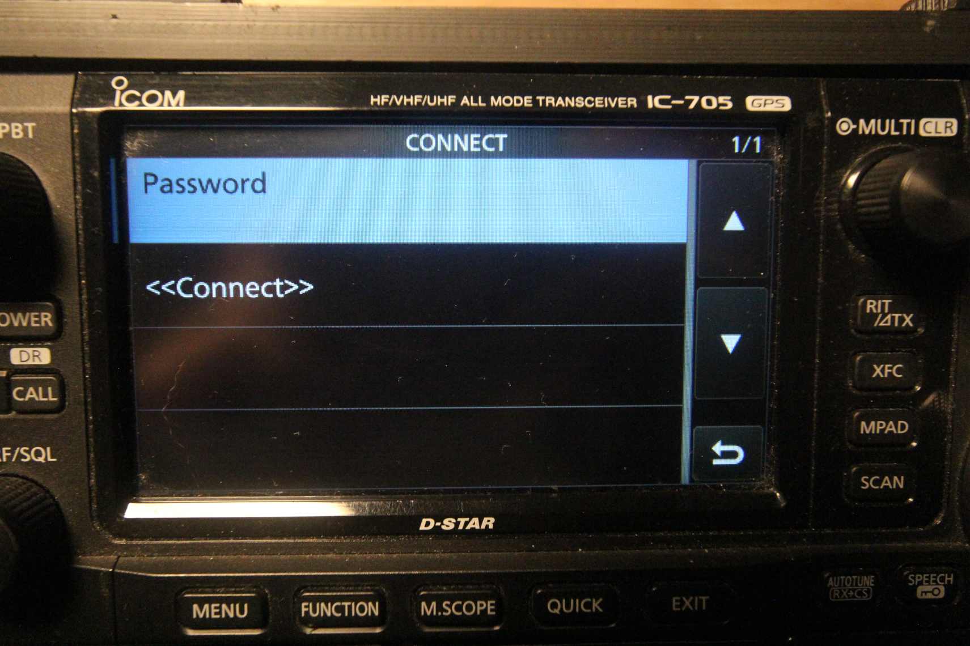
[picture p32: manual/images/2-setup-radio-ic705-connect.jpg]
Icom IC-705 displaying the Connect page


Tapping Password will display the following page that will allow you to enter your Wi-Fi network's password:

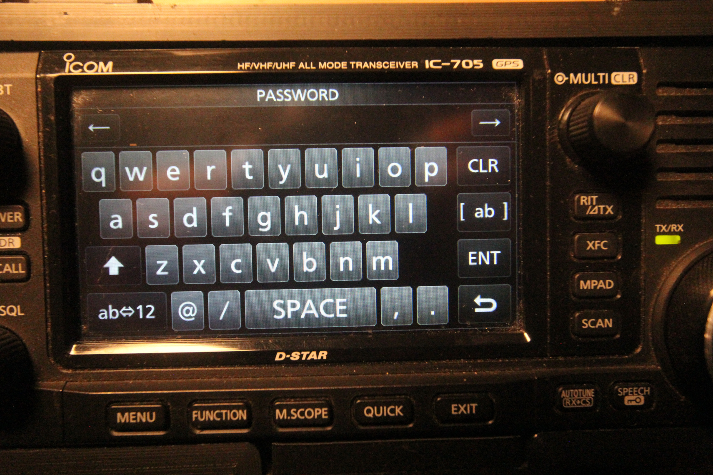
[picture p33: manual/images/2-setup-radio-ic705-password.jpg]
Icom IC-705 displaying the Password page


Once entered, tap the ENT button to save it, then tap the Connect option to connect to the network. If successful,
the Access Point page will show "Connected" below your network's name. Tap the Back button until you return to the
"Connection Settings (Station)" page and make sure you see an IP address under "DHCP (Valid After Restart)":

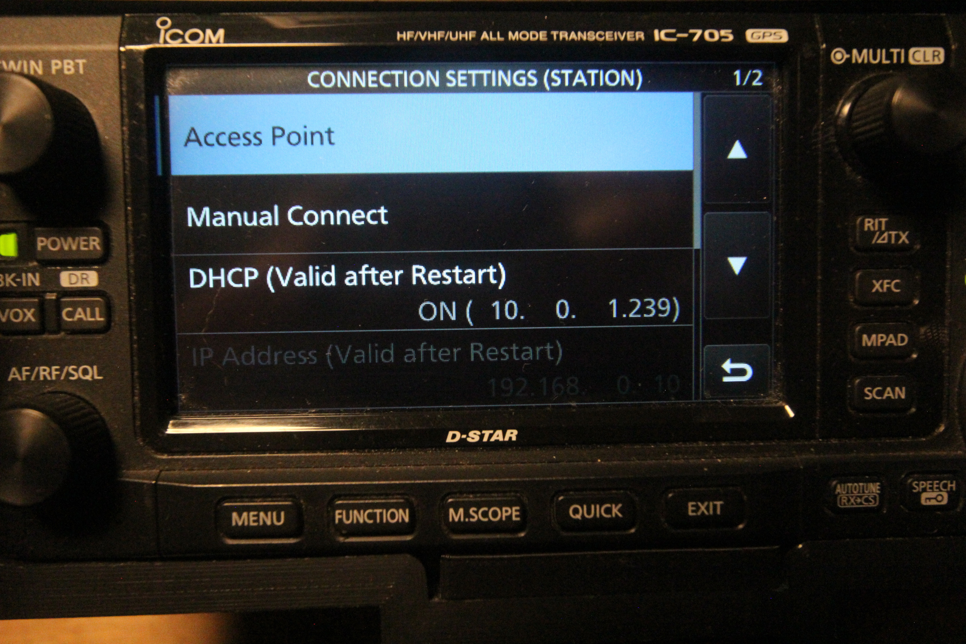
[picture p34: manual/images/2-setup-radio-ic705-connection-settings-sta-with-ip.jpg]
Icom IC-705 displaying an IP address


Note this address as it will be needed for later configuration of ezDV.

## Configuring the Radio User

The IC-705 requires a username and password to connect to the radio. If this is not already set up, you will need
to do so now before continuing with ezDV setup. First, ensure that you're on the "WLAN Set" page and then go to the
second page of options. You will see a "Remote Settings" option:

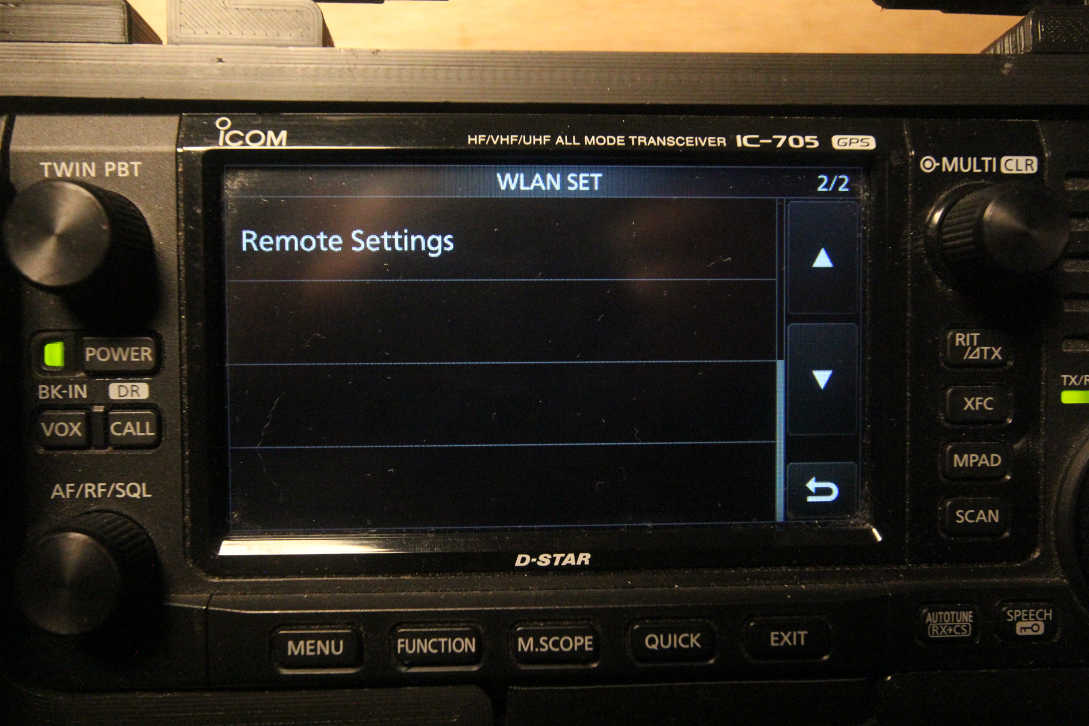
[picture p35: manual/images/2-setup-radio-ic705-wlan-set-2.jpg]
Icom IC-705 displaying the Remote Settings option


Tap on "Remote Settings" and then tap on "Network User1":

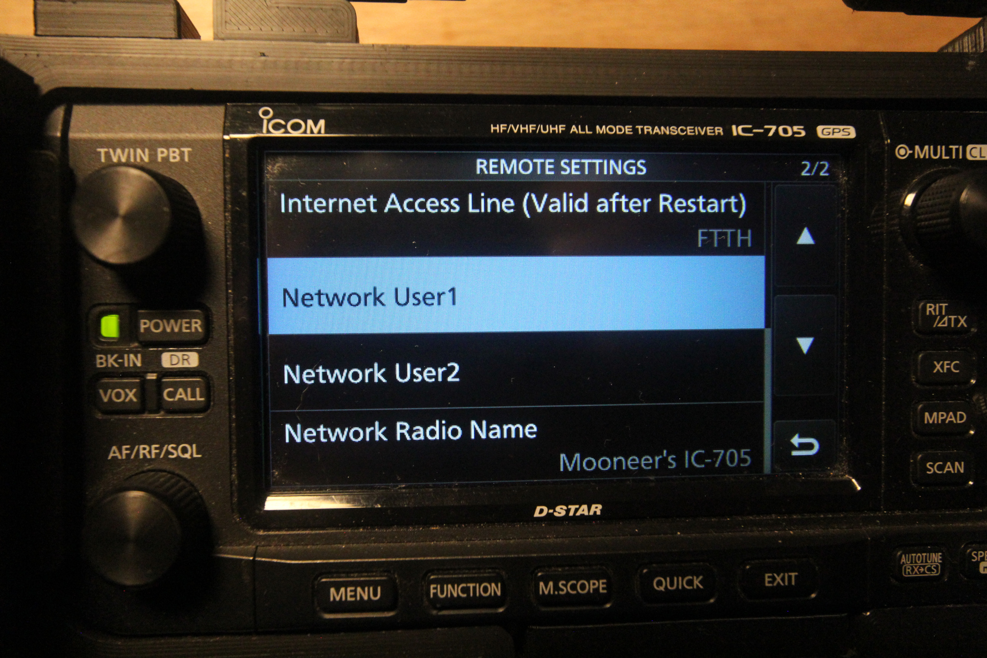
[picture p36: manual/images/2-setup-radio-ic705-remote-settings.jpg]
Icom IC-705 displaying the "Network User1" option.


The following page should appear. Tap on "Network User1 ID" and "Network User1 Password" and enter a username and password
(if not already saved). Make a note of these as you'll need them later. Additionally, make sure "Network User1 Administrator"
is set to "YES".

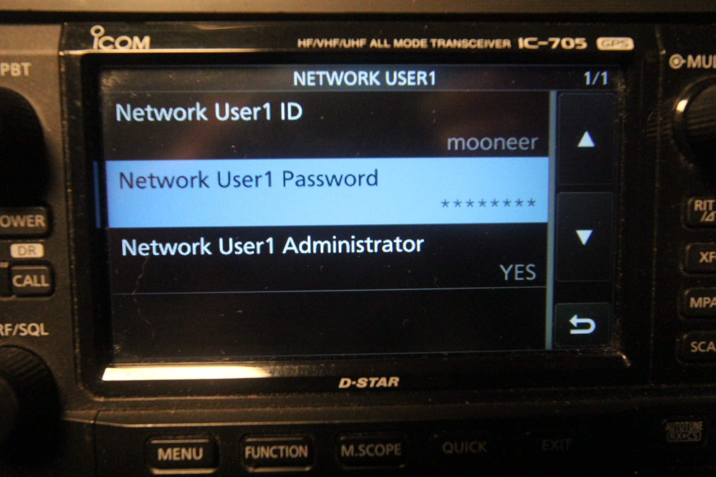
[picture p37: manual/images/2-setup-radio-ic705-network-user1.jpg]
Icom IC-705 displaying the "Network User1" settings.


Tap the Back button until you reach the Set menu.

## Configuring Audio

The IC-705 must be configured to accept transmit audio from the Wi-Fi interface in order for transmit with
ezDV to work properly. From the Set menu, select "Connectors" as shown below:

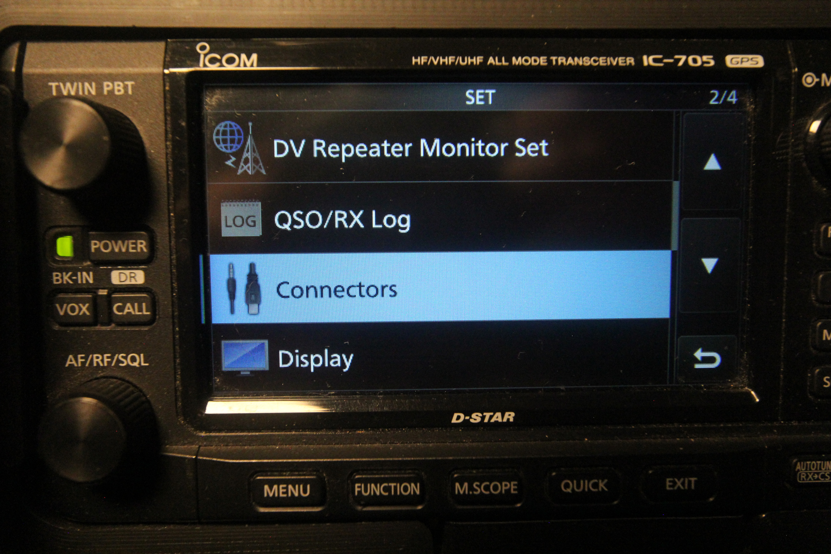
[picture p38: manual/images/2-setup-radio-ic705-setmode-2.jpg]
Icom IC-705 displaying the "Connectors" option.


Next, scroll until you find the "MOD Input" option and then tap it to continue:

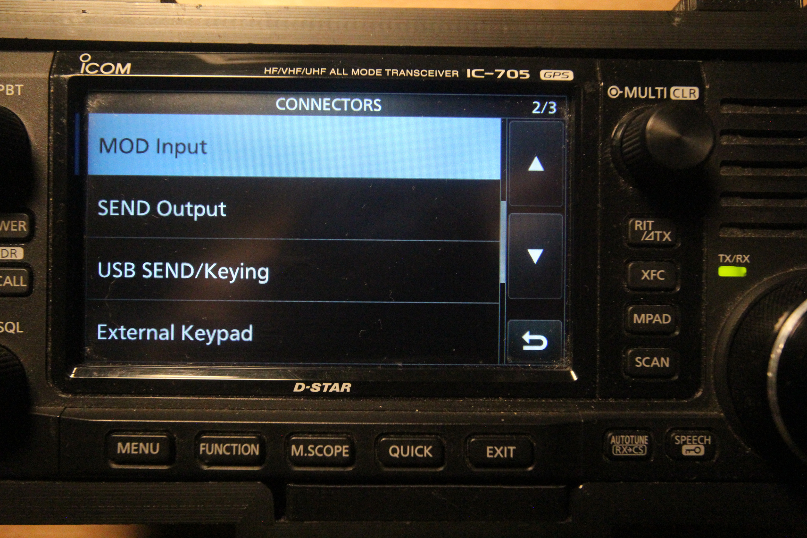
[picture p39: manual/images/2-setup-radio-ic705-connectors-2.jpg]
Icom IC-705 displaying the "MOD Input" option.


Finally, tap the "DATA MOD" option and ensure that it is set to "WLAN":

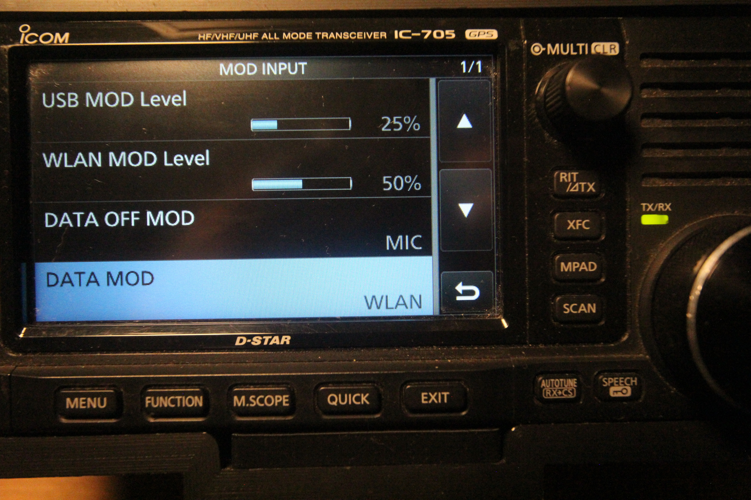
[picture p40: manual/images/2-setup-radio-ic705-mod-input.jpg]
Icom IC-705 displaying the "MOD Input" menu.


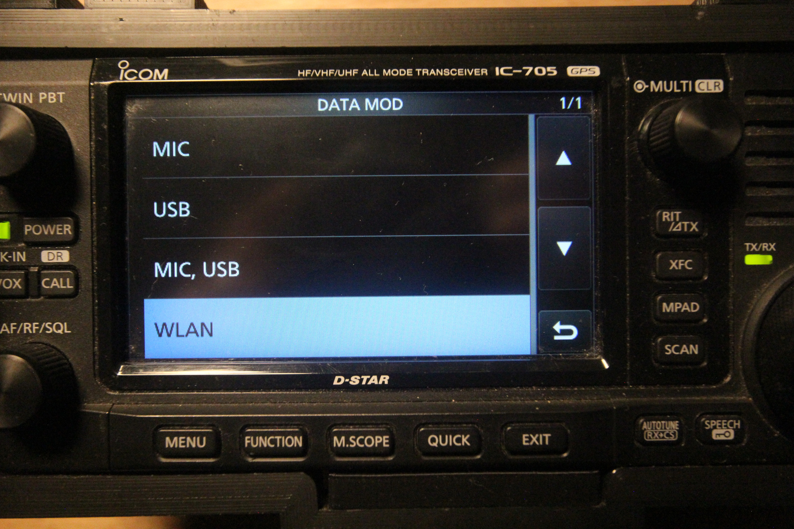
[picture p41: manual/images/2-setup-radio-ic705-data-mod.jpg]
List of valid "DATA MOD" options.


*Note: if you share the IC-705 with other data mode applications over USB (for example, WSJT-X for FT8), make sure
that "DATA MOD" is set to one of the "USB" options above when done using ezDV.*

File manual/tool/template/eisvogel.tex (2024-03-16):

%%
% Copyright (c) 2017 - 2019, Pascal Wagler;
% Copyright (c) 2014 - 2019, John MacFarlane
%
% All rights reserved.
%
% Redistribution and use in source and binary forms, with or without
% modification, are permitted provided that the following conditions
% are met:
%
% - Redistributions of source code must retain the above copyright
% notice, this list of conditions and the following disclaimer.
%
% - Redistributions in binary form must reproduce the above copyright
% notice, this list of conditions and the following disclaimer in the
% documentation and/or other materials provided with the distribution.
%
% - Neither the name of John MacFarlane nor the names of other
% contributors may be used to endorse or promote products derived
% from this software without specific prior written permission.
%
% THIS SOFTWARE IS PROVIDED BY THE COPYRIGHT HOLDERS AND CONTRIBUTORS
% "AS IS" AND ANY EXPRESS OR IMPLIED WARRANTIES, INCLUDING, BUT NOT
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
\definecolor{listing-numbers}{HTML}{B3B2B3}
\definecolor{listing-text-color}{HTML}{000000}
\definecolor{listing-keyword}{HTML}{435489}
\definecolor{listing-identifier}{HTML}{435489}
\definecolor{listing-string}{HTML}{00999A}
\definecolor{listing-comment}{HTML}{8E8E8E}
\definecolor{listing-javadoc-comment}{HTML}{006CA9}

\lstdefinestyle{eisvogel_listing_style}{
  language         = java,
$if(listings-disable-line-numbers)$
  xleftmargin      = 0.6em,
  framexleftmargin = 0.4em,
$else$
  numbers          = left,
  xleftmargin      = 2.7em,
  framexleftmargin = 2.5em,
$endif$
  backgroundcolor  = \color{listing-background},
  basicstyle       = \color{listing-text-color}\small\ttfamily{}\linespread{1.15}, % print whole listing small
  breaklines       = true,
  frame            = single,
  framesep         = 0.19em,
  rulecolor        = \color{listing-rule},
  frameround       = ffff,
  tabsize          = 4,
  numberstyle      = \color{listing-numbers},
  aboveskip        = 1.0em,
  belowskip        = 0.1em,
  abovecaptionskip = 0em,
  belowcaptionskip = 1.0em,
  keywordstyle     = \color{listing-keyword}\bfseries,
  classoffset      = 0,
  sensitive        = true,
  identifierstyle  = \color{listing-identifier},
  commentstyle     = \color{listing-comment},
  morecomment      = [s][\color{listing-javadoc-comment}]{/**}{*/},
  stringstyle      = \color{listing-string},
  showstringspaces = false,
  escapeinside     = {/*@}{@*/}, % Allow LaTeX inside these special comments
  literate         =
  {á}{{\'a}}1 {é}{{\'e}}1 {í}{{\'i}}1 {ó}{{\'o}}1 {ú}{{\'u}}1
  {Á}{{\'A}}1 {É}{{\'E}}1 {Í}{{\'I}}1 {Ó}{{\'O}}1 {Ú}{{\'U}}1
  {à}{{\`a}}1 {è}{{\'e}}1 {ì}{{\`i}}1 {ò}{{\`o}}1 {ù}{{\`u}}1
  {À}{{\`A}}1 {È}{{\'E}}1 {Ì}{{\`I}}1 {Ò}{{\`O}}1 {Ù}{{\`U}}1
  {ä}{{\"a}}1 {ë}{{\"e}}1 {ï}{{\"i}}1 {ö}{{\"o}}1 {ü}{{\"u}}1
  {Ä}{{\"A}}1 {Ë}{{\"E}}1 {Ï}{{\"I}}1 {Ö}{{\"O}}1 {Ü}{{\"U}}1
  {â}{{\^a}}1 {ê}{{\^e}}1 {î}{{\^i}}1 {ô}{{\^o}}1 {û}{{\^u}}1
  {Â}{{\^A}}1 {Ê}{{\^E}}1 {Î}{{\^I}}1 {Ô}{{\^O}}1 {Û}{{\^U}}1
  {œ}{{\oe}}1 {Œ}{{\OE}}1 {æ}{{\ae}}1 {Æ}{{\AE}}1 {ß}{{\ss}}1
  {ç}{{\c c}}1 {Ç}{{\c C}}1 {ø}{{\o}}1 {å}{{\r a}}1 {Å}{{\r A}}1
  {€}{{\EUR}}1 {£}{{\pounds}}1 {«}{{\guillemotleft}}1
  {»}{{\guillemotright}}1 {ñ}{{\~n}}1 {Ñ}{{\~N}}1 {¿}{{?`}}1
  {…}{{\ldots}}1 {≥}{{>=}}1 {≤}{{<=}}1 {„}{{\glqq}}1 {“}{{\grqq}}1
  {”}{{''}}1
}
\lstset{style=eisvogel_listing_style}

\lstdefinelanguage{XML}{
  morestring      = [b]",
  moredelim       = [s][\bfseries\color{listing-keyword}]{<}{\ },
  moredelim       = [s][\bfseries\color{listing-keyword}]{</}{>},
  moredelim       = [l][\bfseries\color{listing-keyword}]{/>},
  moredelim       = [l][\bfseries\color{listing-keyword}]{>},
  morecomment     = [s]{<?}{?>},
  morecomment     = [s]{<!--}{-->},
  commentstyle    = \color{listing-comment},
  stringstyle     = \color{listing-string},
  identifierstyle = \color{listing-identifier}
}
$endif$

%
% header and footer
%
$if(beamer)$
$else$
$if(disable-header-and-footer)$
$else$
\usepackage{fancyhdr}

\fancypagestyle{eisvogel-header-footer}{
  \fancyhead{}
  \fancyfoot{}
  \lhead[$if(header-right)$$header-right$$else$$date$$endif$]{$if(header-left)$$header-left$$else$$title$$endif$}
  \chead[$if(header-center)$$header-center$$else$$endif$]{$if(header-center)$$header-center$$else$$endif$}
  \rhead[$if(header-left)$$header-left$$else$$title$$endif$]{$if(header-right)$$header-right$$else$$date$$endif$}
  \lfoot[$if(footer-right)$$footer-right$$else$\thepage$endif$]{$if(footer-left)$$footer-left$$else$$for(author)$$author$$sep$, $endfor$$endif$}
  \cfoot[$if(footer-center)$$footer-center$$else$$endif$]{$if(footer-center)$$footer-center$$else$$endif$}
  \rfoot[$if(footer-left)$$footer-left$$else$$for(author)$$author$$sep$, $endfor$$endif$]{$if(footer-right)$$footer-right$$else$\thepage$endif$}
  \renewcommand{\headrulewidth}{0.4pt}
  \renewcommand{\footrulewidth}{0.4pt}
}
\pagestyle{eisvogel-header-footer}
$endif$
$endif$

%%
%% end added
%%

\begin{document}

%%
%% begin titlepage
%%
$if(beamer)$
$else$
$if(titlepage)$
\begin{titlepage}
\newgeometry{left=6cm}
$if(titlepage-color)$
\definecolor{titlepage-color}{HTML}{$titlepage-color$}
\newpagecolor{titlepage-color}\afterpage{\restorepagecolor}
$endif$
\newcommand{\colorRule}[3][black]{\textcolor[HTML]{#1}{\rule{#2}{#3}}}
\begin{flushleft}
\noindent
\\[-1em]
\color[HTML]{$if(titlepage-text-color)$$titlepage-text-color$$else$5F5F5F$endif$}
\makebox[0pt][l]{\colorRule[$if(titlepage-rule-color)$$titlepage-rule-color$$else$435488$endif$]{1.3\textwidth}{$if(titlepage-rule-height)$$titlepage-rule-height$$else$4$endif$pt}}
\par
\noindent

{ \setstretch{1.4}
\vfill
\noindent {\huge \textbf{\textsf{$title$}}}
$if(subtitle)$
\vskip 1em
{\Large \textsf{$subtitle$}}
$endif$
\vskip 8em
\noindent
{\Large \textsf{$for(author)$$author$$sep$, $endfor$}}
\vskip 1em
\textsf{$date$}}
\vfill

$if(logo)$
\noindent

$endif$

\end{flushleft}
\end{titlepage}
\restoregeometry
$endif$
$endif$

%%
%% end titlepage
%%

$if(has-frontmatter)$
\frontmatter
$endif$
$if(title)$
$if(beamer)$
\frame{\titlepage}
$endif$
$if(abstract)$
\begin{abstract}
$abstract$
\end{abstract}
$endif$
$endif$

$if(first-chapter)$
\setcounter{chapter}{$first-chapter$}
\addtocounter{chapter}{-1}
$endif$

$for(include-before)$
$include-before$

$endfor$
$if(toc)$
$if(toc-title)$
\renewcommand*\contentsname{$toc-title$}
$endif$
$if(beamer)$
\begin{frame}
$if(toc-title)$
  \frametitle{$toc-title$}
$endif$
  \tableofcontents[hideallsubsections]
\end{frame}
$if(toc-own-page)$
\newpage
$endif$
$else$
{
$if(colorlinks)$
\hypersetup{linkcolor=$if(toccolor)$$toccolor$$else$$endif$}
$endif$
\setcounter{tocdepth}{$if(toc-depth)$$toc-depth$$else$3$endif$}
\tableofcontents
$if(toc-own-page)$
\newpage
$endif$
}
$endif$
$endif$
$if(lot)$
\listoftables
$endif$
$if(lof)$
\listoffigures
$endif$
$if(linestretch)$
\setstretch{$linestretch$}
$endif$
$if(has-frontmatter)$
\mainmatter
$endif$
$body$

$if(has-frontmatter)$
\backmatter
$endif$
$if(natbib)$
$if(bibliography)$
$if(biblio-title)$
$if(has-chapters)$
\renewcommand\bibname{$biblio-title$}
$else$
\renewcommand\refname{$biblio-title$}
$endif$
$endif$
$if(beamer)$
\begin{frame}[allowframebreaks]{$biblio-title$}
  \bibliographytrue
$endif$
  \bibliography{$for(bibliography)$$bibliography$$sep$,$endfor$}
$if(beamer)$
\end{frame}
$endif$

$endif$
$endif$
$if(biblatex)$
$if(beamer)$
\begin{frame}[allowframebreaks]{$biblio-title$}
  \bibliographytrue
  \printbibliography[heading=none]
\end{frame}
$else$
\printbibliography$if(biblio-title)$[title=$biblio-title$]$endif$
$endif$

$endif$
$for(include-after)$
$include-after$

$endfor$
\end{document}

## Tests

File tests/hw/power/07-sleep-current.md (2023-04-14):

# ezDV sleep current lower than limit

## Prerequisites

* DC benchtop power supply set to 3.7V
* [tinyCurrent low-current measuring device](https://www.n-fuse.co/devices/tinyCurrent-precision-low-Current-Measurement-Shunt-and-Amplifier-Device.html) with BNC jack.
* JST plug to wire leads
* Multimeter

## Test Steps

1. Attach positive lead from benchtop power supply to positive banana jack on tinyCurrent.
2. Attach negative lead from negative banana jack on tinyCurrent to the positive (red) cable on the JST plug.
3. Attach negative lead from the benchtop power supply to the negative (black) cable on the JST plug.
4. Set the tinyCurrent to milliamps (1 mV/mA) and turn it on.
5. Turn on the DC output on the benchtop power supply. Wait for the LEDs on ezDV to light up and then extinguish.
6. Push and hold the Mode button on ezDV and wait for the LEDs to turn on and then extinguish.
7. Set the tinyCurrent to microamps (1 mV/uA).
8. Probe the positive and negative test points on tinyCurrent with the multimeter.

## Expected Results

ezDV should use no more than 60 uA when sleeping. This will work out to being able to be off for almost four years before draining a 2000 mAh battery.

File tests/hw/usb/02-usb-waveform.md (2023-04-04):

# USB waveform has acceptable eye

## Prerequisites

* Oscilloscope with a minimum of two channels
* 2x 10x oscilloscope probes (or switching 1x/10x set to 10x)
* [USB breakout board](https://www.winford.com/products/btsubfaf.php)
* USB-A to C cable
* USB-B to A cable
* USB-C to A adapter
* PC with USB ports

## Test Steps

1. Attach ezDV and a PC to the breakout board using the cables and adapters.
2. Attach two 10x oscilloscope probes to two of the channels on the oscilloscope (and attach their ground leads to each other).
3. Probe the D+ and D- test points on the breakout board.
4. Set each channel to 1 V/div and the timebase to 10ns/div.
5. Set a trigger for ~2 V and have it fire on rising edge for the channel probing D+.
6. Set the positions of both channels to 0 volts and center the two waveforms horizontally.
7. Turn on persistence and set the persistence time to 5 seconds.

## Expected Results

The waveform should look similar to the below. The lighter colored noise around the two waveforms should be as
narrow as possible and show a visible eye. 

USB waveform

*Note: this test is unlikely to fail if the [PC can properly enumerate ezDV](01-usb-enumeration.md) but is included for completeness.*

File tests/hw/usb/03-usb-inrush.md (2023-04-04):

# USB inrush current below maximum limit

## Prerequisites

* Oscilloscope that can save .csv files on USB drives (example: Rigol DS1054Z)
* [tinyCurrent low-current measuring device](https://www.n-fuse.co/devices/tinyCurrent-precision-low-Current-Measurement-Shunt-and-Amplifier-Device.html) with BNC jack.
* [USB breakout board](https://www.winford.com/products/btsubfaf.php)
* USB-A to C cable
* USB-B to A cable
* USB-C to A adapter
* RG-58 coax with BNC connectors
* PC with USB ports that has the [USBET20 tool](https://www.usb.org/document-library/usbet20) installed
* Battery attached to ezDV that is at least 50% discharged

## Test Steps

1. Attach ezDV to the breakout board using the cables and adapters. Do not attach to the PC yet.
2. Remove the jumper bridging the 5V rail on both sides of the breakout board and attach two wires (red banana jack to the PC side of the breakout and black banana jack to the ezDV side).
3. Attach coax cable from tinyCurrent to the oscilloscope.
4. Set the oscilloscope timebase to 100ms/div and the channel to 100 mV/div. Ensure that the sample rate is >= 1 MS/sec.
5. Set the tinyCurrent device to use the 1mA/mV scale and turn it on.
6. Turn on a single shot capture using a trigger of 100 mV.
7. Plug in the breakout board to the PC. The oscilloscope should stop and display the waveform.
8. Using the oscilloscope's buttons, save a CSV file of the oscilloscope's memory (not display) to a USB drive.
9. Copy the saved file from the USB stick to the PC.
10. Ensure that the CSV file is formatted with two columns: time (in seconds) and the current. You can use [this script](03-usb-inrush.py) as an example for the Rigol DS1054Z if you need to massage the data.
11. Run the USBET20 tool and select the Inrush Current tab. Select the CSV file you generated or saved and enter 5 volts for the voltage.
12. Click the Test button. After a few minutes, a web browser should display with the results.

## Expected Results

The USBET20 tool should display an inrush figure below 55 uC, which is the upper limit for USB 2.0.

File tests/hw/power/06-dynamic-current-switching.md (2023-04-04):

# ezDV dynamically limits current through USB-C while powered on

## Prerequisites

* [FUSB302 EVB](https://www.mouser.com/ProductDetail/863-FUSB302TGEVB) and [associated software](https://www.onsemi.com/pub/collateral/fusb302%20evb%20gui.zip).
* USB-C measurement cable (e.g. [these from Amazon](https://www.amazon.com/gp/product/B09V81BTMK/ref=ppx_yo_dt_b_asin_title_o04_s00?ie=UTF8&psc=1))
* 2000 mAh LiPo battery discharged to 3.6V or less

## Test Steps

1. Attach battery to ezDV.
2. Attach USB measurement cable to ezDV and the FUSB302 EVB. Attach micro-USB cable between PC and EVB.
3. Unzip the software mentioned above and execute the .exe file within the resulting folder. You should see something like the following:

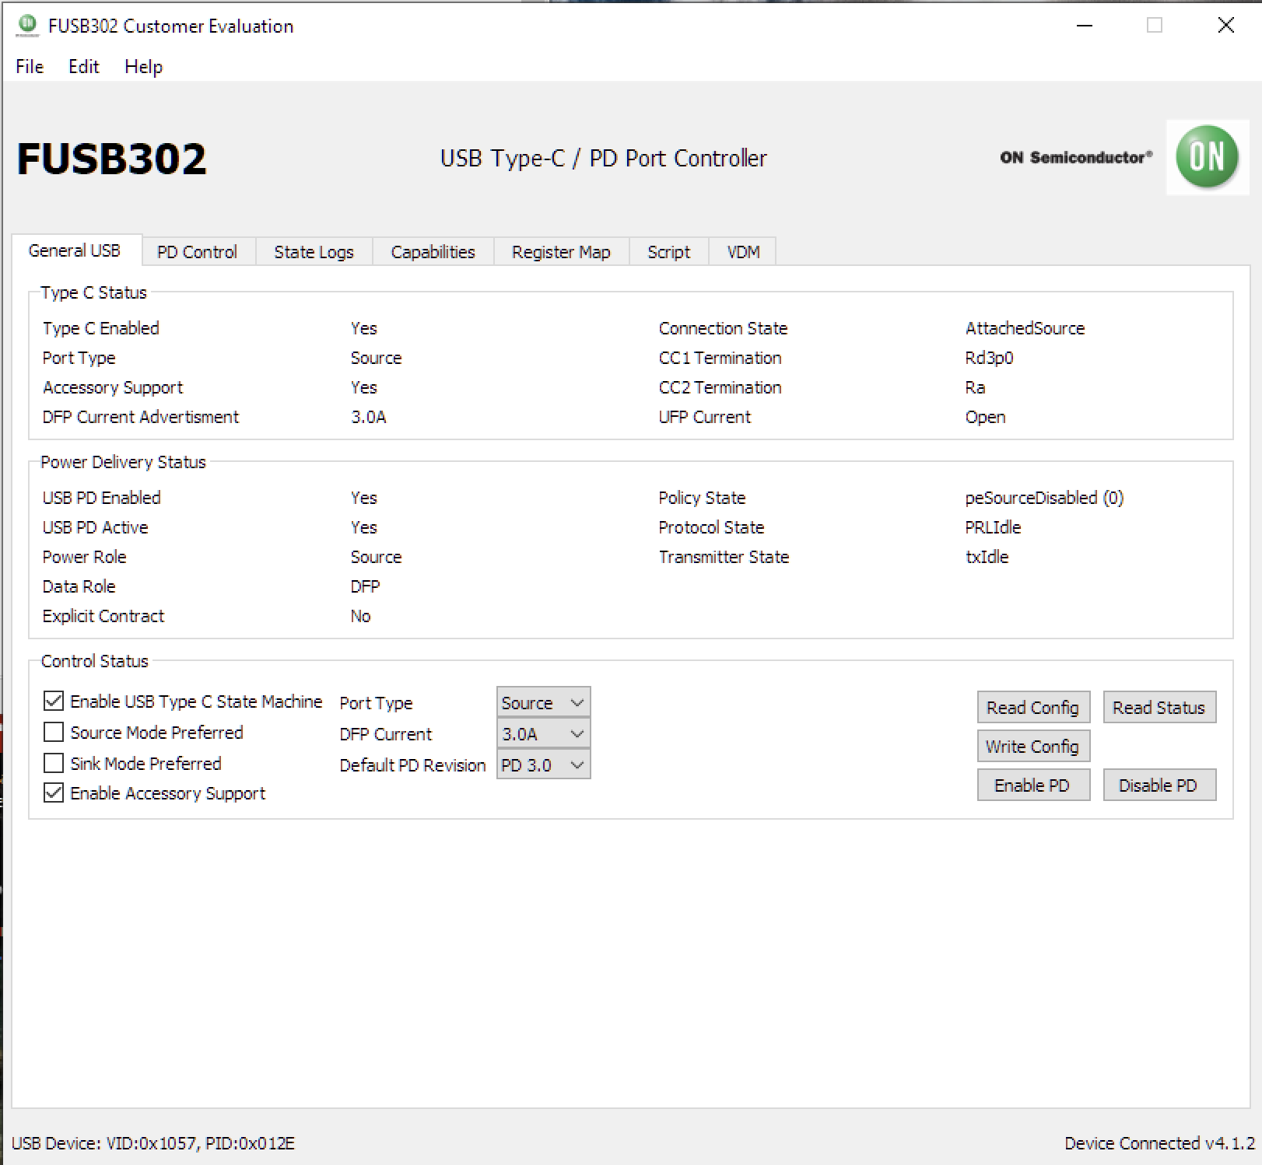
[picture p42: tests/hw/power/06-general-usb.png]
EVB GUI application on startup


4. On the "General USB" tab, select the following and click "Write Config":

    * *Port Type*: Source
    * *DFP Current*: 3.0A
    
5. Read measurement on cable. It should read as consuming a wattage that corresponds to a current over 500mA (for example, 3.6 W / 5 V = 0.72A).
6. Go to the "Register Map" tab, which looks like the following:

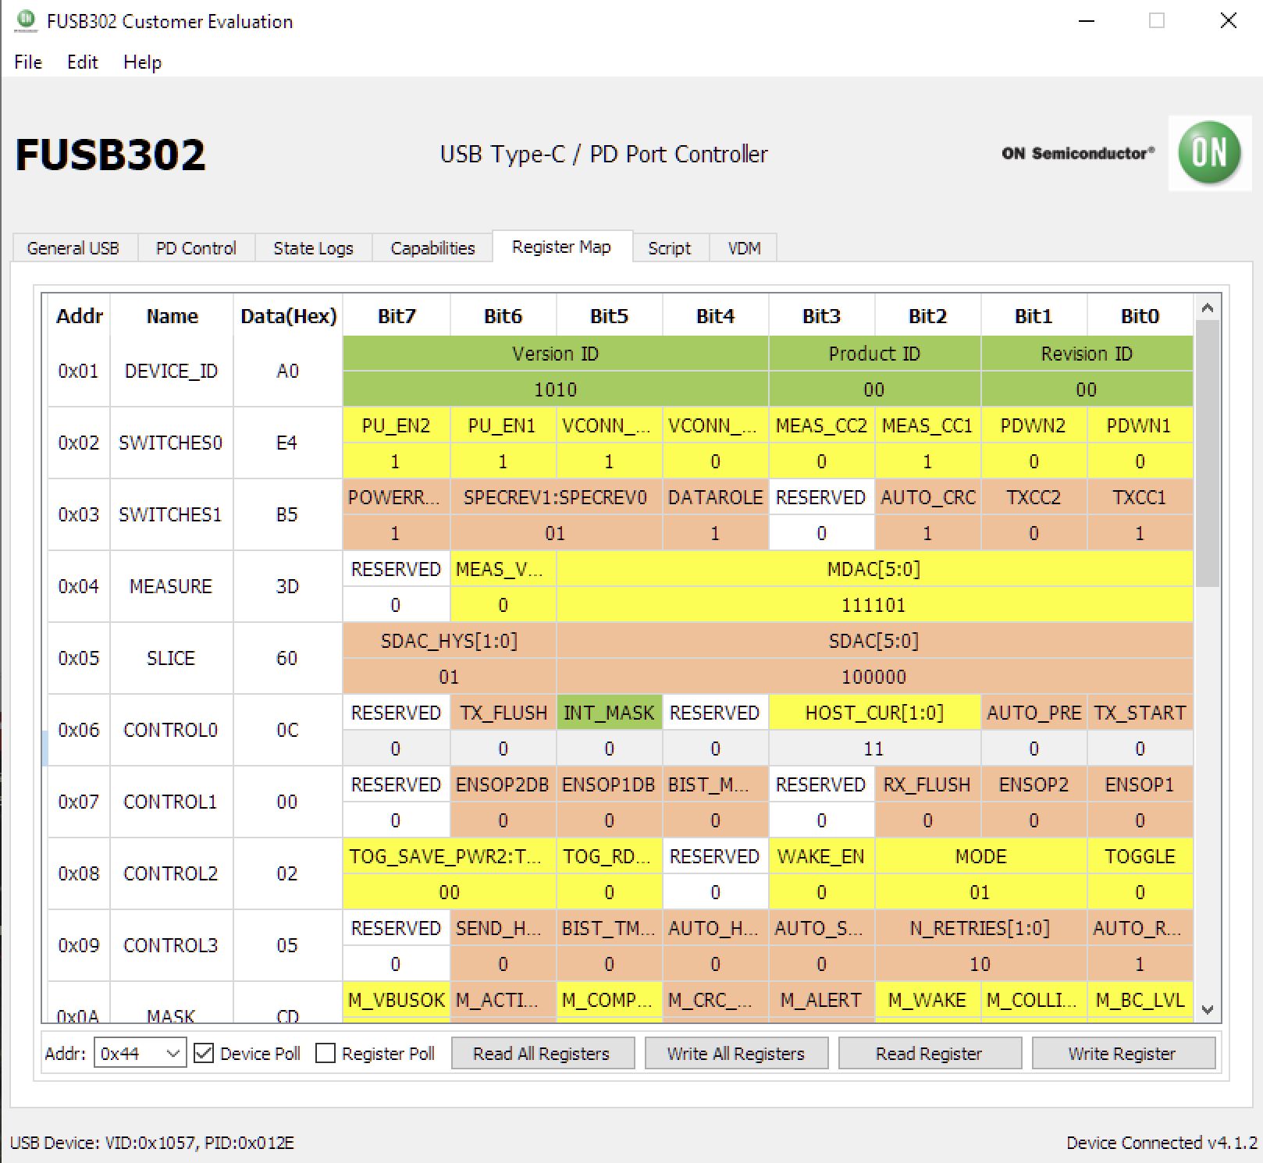
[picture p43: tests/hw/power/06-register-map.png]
EVB GUI application displaying the Register Map


7. Click on the "HOST_CUR" value in row 0x06 and click on the "Read Register" button. This should result in this value becoming 11, corresponding to 3A current.
8. Modify "HOST_CUR" to read "01" instead of "11" and click on the "Write Register" button.

## Expected Results

Within 1-2 seconds after clicking on "Write Register", the measurement cable should read a wattage less than 2.5 watts (i.e. less than the 500 mA limit in the USB 2.0 specification).

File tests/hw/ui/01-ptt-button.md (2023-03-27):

# PTT button properly functioning

## Prerequisites

* ezDV flashed to latest firmware

## Test Steps

1. Hold down PTT and Mode to turn on ezDV in Hardware Test mode. Release both buttons when LEDs light up.
2. Press the PTT button and note the status of the PTT LED.
3. Release the PTT button and note the status of the PTT LED.

## Expected Results

The PTT LED should extinguish while the PTT button is held and re-light after the PTT button has been released.

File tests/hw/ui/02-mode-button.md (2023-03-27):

# Mode button properly functioning

## Prerequisites

* ezDV flashed to latest firmware

## Test Steps

1. Hold down PTT and Mode to turn on ezDV in Hardware Test mode. Release both buttons when LEDs light up.
2. Press the Mode button and note the status of the Sync LED. *Note: holding this button for more than 1 second will power off ezDV.*
3. Release the Mode button and note the status of the Sync LED.

## Expected Results

The Sync LED should extinguish while the Mode button is held and re-light after the Mode button has been released.

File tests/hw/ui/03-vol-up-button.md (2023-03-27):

# Volume Up button properly functioning

## Prerequisites

* ezDV flashed to latest firmware

## Test Steps

1. Hold down PTT and Mode to turn on ezDV in Hardware Test mode. Release both buttons when LEDs light up.
2. Press the Volume Up button and note the status of the Overload LED.
3. Release the Volume Up button and note the status of the Overload LED.

## Expected Results

The Overload LED should extinguish while the Volume Up button is held and re-light after the Volume Up button has been released.

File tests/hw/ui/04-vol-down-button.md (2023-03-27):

# Volume Down button properly functioning

## Prerequisites

* ezDV flashed to latest firmware

## Test Steps

1. Hold down PTT and Mode to turn on ezDV in Hardware Test mode. Release both buttons when LEDs light up.
2. Press the Volume Down button and note the status of the Net LED.
3. Release the Volume Down button and note the status of the Net LED.

## Expected Results

The Net LED should extinguish while the Volume Down button is held and re-light after the Volume Down button has been released.

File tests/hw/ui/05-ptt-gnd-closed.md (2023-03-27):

# PTT button properly closing PTT line on Radio jack

## Prerequisites

* ezDV flashed to latest firmware
* TRRS breakout adapter ([example](https://www.amazon.com/gp/product/B07QQPG6BT/ref=ppx_yo_dt_b_search_asin_title?ie=UTF8&psc=1))
* Multimeter set to Resistance mode

## Test Steps

1. Hold down Mode for one second to turn on ezDV in normal operation mode.
2. Attach TRRS breakout adapter to the Radio jack (left hand side) on ezDV.
3. Press and hold the PTT button while measuring the resistance between the middle two terminal screws on the adapter.

## Expected Results

The measured resistance should be below 20 ohms when PTT is held and out of range of the multimeter (typically "OL" on Fluke meters, for example) when PTT is released.

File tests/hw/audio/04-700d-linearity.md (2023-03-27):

# Linearity of 700D signal

## Prerequisites

* USB audio adapter with 3.5mm jacks for microphone/speaker
* 3.5mm TRRS audio cable ([example](https://www.amazon.com/gp/product/B07PJW6RQ7/ref=ppx_yo_dt_b_search_asin_title?ie=UTF8&psc=1))
* TRSS to separate 3.5mm microphone and speaker splitter ([example](https://www.amazon.com/UGREEN-Headphone-Splitter-Computer-Smartphone/dp/B073ZDDTH2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))
* ezDV flashed to latest firmware
* Laptop or other PC with [Audacity](https://www.audacityteam.org/) installed
* ezDV *NOT* attached to the above PC via USB during test

## Test Steps

### Initial Configuration

1. Attach one end of the TRRS cable to the Radio 3.5mm jack on ezDV and the other to the splitter.
2. Attach headphone connector on splitter to the USB audio adapter's microphone input.
3. Attach microphone connector on splitter to the USB audio adapter's headphone/speaker output.
4. Hold down PTT and Mode to turn on ezDV in Hardware Test mode. Release both buttons when LEDs light up.
5. Start Audcaity on test PC and configure it to use the USB audio adapter for input and output and record in mono mode.
6. Create a new Audacity project with a sample rate of 8000 Hz.
7. Begin recording and adjust input volume using your operating system's volume controls until Audacity just hits 0 dB.
8. Stop recording and delete the track that Audacity created.
9. Power off ezDV (press and hold Mode until LEDs extinguish), then press and hold Mode to boot ezDV in normal operation mode.
10. Push Mode once to switch to 700D mode, then press and hold PTT to begin transmitting.
11. Begin recording and adjust volume on ezDV until the peaks are just below 0 dB on Audacity's input meter.
12. Stop recording and delete the track that Audacity created.

### Test Execution

1. Record approximately 5 seconds of audio from ezDV.
2. Release PTT to stop recording.
3. Select all the audio on the track (Ctrl/Command-A) and go to Analyze->Plot Spectrum.
4. Use the following settings in the Frequency Analysis window:
    * *Algorithm*: Spectrum
    * *Size*: 1024
    * *Function*: Hann window
    * *Axis*: Linear frequency

## Expected Results

For the frequencies between 1 KHz and 2 KHz, all audio peaks should be at approximately the same level (+/- a few dB). Additionally, frequencies outside of this passband should be significantly lower due to the use of the Codec2 software bandpass filter.

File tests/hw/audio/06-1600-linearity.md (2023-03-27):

# Linearity of 1600 signal

## Prerequisites

* USB audio adapter with 3.5mm jacks for microphone/speaker
* 3.5mm TRRS audio cable ([example](https://www.amazon.com/gp/product/B07PJW6RQ7/ref=ppx_yo_dt_b_search_asin_title?ie=UTF8&psc=1))
* TRSS to separate 3.5mm microphone and speaker splitter ([example](https://www.amazon.com/UGREEN-Headphone-Splitter-Computer-Smartphone/dp/B073ZDDTH2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))
* ezDV flashed to latest firmware
* Laptop or other PC with [Audacity](https://www.audacityteam.org/) installed
* ezDV *NOT* attached to the above PC via USB during test

## Test Steps

### Initial Configuration

1. Attach one end of the TRRS cable to the Radio 3.5mm jack on ezDV and the other to the splitter.
2. Attach headphone connector on splitter to the USB audio adapter's microphone input.
3. Attach microphone connector on splitter to the USB audio adapter's headphone/speaker output.
4. Hold down PTT and Mode to turn on ezDV in Hardware Test mode. Release both buttons when LEDs light up.
5. Start Audcaity on test PC and configure it to use the USB audio adapter for input and output and record in mono mode.
6. Create a new Audacity project with a sample rate of 8000 Hz.
7. Begin recording and adjust input volume using your operating system's volume controls until Audacity just hits 0 dB.
8. Stop recording and delete the track that Audacity created.
9. Power off ezDV (press and hold Mode until LEDs extinguish), then press and hold Mode to boot ezDV in normal operation mode.
10. Push Mode three times to switch to 1600 mode, then press and hold PTT to begin transmitting.
11. Begin recording and adjust volume on ezDV until the peaks are just below 0 dB on Audacity's input meter.
12. Stop recording and delete the track that Audacity created.

### Test Execution

1. Record approximately 5 seconds of audio from ezDV.
2. Release PTT to stop recording.
3. Select all the audio on the track (Ctrl/Command-A) and go to Analyze->Plot Spectrum.
4. Use the following settings in the Frequency Analysis window:
    * *Algorithm*: Spectrum
    * *Size*: 1024
    * *Function*: Hann window
    * *Axis*: Linear frequency

## Expected Results

For the frequencies between approximately 850 Hz and 2200 Hz, most audio peaks should be at approximately the same level (+/- a few dB). The exception is the peak at approximately 1500 Hz, which should be at least 5 dB higher.

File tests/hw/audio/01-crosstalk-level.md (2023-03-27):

# Audio crosstalk below maximum acceptable level

## Prerequisites

* USB audio adapter with 3.5mm jacks for microphone/speaker
* 3.5mm TRRS audio cable ([example](https://www.amazon.com/gp/product/B07PJW6RQ7/ref=ppx_yo_dt_b_search_asin_title?ie=UTF8&psc=1))
* TRSS to separate 3.5mm microphone and speaker splitter ([example](https://www.amazon.com/UGREEN-Headphone-Splitter-Computer-Smartphone/dp/B073ZDDTH2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))
* ezDV flashed to latest firmware
* Laptop or other PC with [Audacity](https://www.audacityteam.org/) installed

## Test Steps

### Initial Configuration

1. Attach one end of the TRRS cable to the User jack (right hand side) on ezDV and the other to the splitter.
2. Attach headphone connector on splitter to the USB audio adapter's microphone input.
3. Attach microphone connector on splitter to the USB audio adapter's headphone/speaker output.
4. Hold down PTT and Mode to turn on ezDV in Hardware Test mode. Release both buttons when LEDs light up.
5. Start Audcaity on test PC and configure it to use the USB audio adapter for input and output and record in mono mode.
6. Create a new Audacity project with a sample rate of 8000 Hz.
7. Begin recording and adjust input volume using your operating system's volume controls until Audacity just hits 0 dB.
8. Stop recording and delete the track that Audacity created.

### Test Execution

1. Record approximately 5 seconds of audio from ezDV.
2. Select all the audio on the track (Ctrl/Command-A) and go to Analyze->Plot Spectrum.
3. Use the following settings in the Frequency Analysis window:
    * *Algorithm*: Spectrum
    * *Size*: 1024
    * *Function*: Hann window
    * *Axis*: Linear frequency

## Expected Results

ezDV emits two test sine tones: one at approximately 1275 Hz on the user jack and another at approximately 1725 Hz on the radio jack. The level of the 1275 Hz tone should be near 0 dB while the 1725 Hz tone (if any) should be approximately 70 dB or more below the 1275 Hz tone.

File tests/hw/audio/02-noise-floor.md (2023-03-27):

# Audio noise floor below maximum acceptable level

## Prerequisites

* USB audio adapter with 3.5mm jacks for microphone/speaker
* 3.5mm TRRS audio cable ([example](https://www.amazon.com/gp/product/B07PJW6RQ7/ref=ppx_yo_dt_b_search_asin_title?ie=UTF8&psc=1))
* TRSS to separate 3.5mm microphone and speaker splitter ([example](https://www.amazon.com/UGREEN-Headphone-Splitter-Computer-Smartphone/dp/B073ZDDTH2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))
* ezDV flashed to latest firmware
* Laptop or other PC with [Audacity](https://www.audacityteam.org/) installed
* ezDV *NOT* attached to the above PC via USB during test

## Test Steps

### Initial Configuration

1. Attach one end of the TRRS cable to one of the 3.5mm jacks on ezDV and the other to the splitter.
2. Attach headphone connector on splitter to the USB audio adapter's microphone input.
3. Attach microphone connector on splitter to the USB audio adapter's headphone/speaker output.
4. Hold down PTT and Mode to turn on ezDV in Hardware Test mode. Release both buttons when LEDs light up.
5. Start Audcaity on test PC and configure it to use the USB audio adapter for input and output and record in mono mode.
6. Create a new Audacity project with a sample rate of 8000 Hz.
7. Begin recording and adjust input volume using your operating system's volume controls until Audacity just hits 0 dB.
8. Stop recording and delete the track that Audacity created.

### Test Execution

1. Press the Mode button on ezDV seven times to mute all audio and PTT triggering.
2. Record approximately 5 seconds of audio from ezDV.
2. Select all the audio on the track (Ctrl/Command-A) and go to Analyze->Plot Spectrum.
3. Use the following settings in the Frequency Analysis window:
    * *Algorithm*: Spectrum
    * *Size*: 1024
    * *Function*: Hann window
    * *Axis*: Linear frequency

## Expected Results

For frequencies above 10 Hz, the audio level should be no more than -95 dB.

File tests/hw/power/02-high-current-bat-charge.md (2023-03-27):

# ezDV properly charges at high current with supporting USB-C ports

## Prerequisites

* USB-C PD power supply
* USB measurement cable (e.g. [these from Amazon](https://www.amazon.com/gp/product/B09V81BTMK/ref=ppx_yo_dt_b_asin_title_o04_s00?ie=UTF8&psc=1))
* 2000 mAh LiPo battery discharged to 3.6V or less

## Test Steps

1. Attach battery to ezDV. Power off ezDV if necessary (i.e. if firmware has already been flashed).
2. Attach USB measurement cable to ezDV and the USB power supply.
3. Read measurement on cable.

## Expected Results

The measurement cable should read greate than 3 watts, which corresponds to (3W / 5V = 0.6A) per Ohm's Law. A red LED should also light on the bottom of the board indicating that charging is in progress.

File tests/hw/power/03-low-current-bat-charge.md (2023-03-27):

# ezDV properly charges at low current with legacy USB ports.

## Prerequisites

* DC bench power supply set to 5 volts (and maximum 2A of current) with meters.
* USB to alligator clips ([example](https://www.amazon.com/HCFeng-Alligator-Adapter-Testing-Circuit/dp/B0BG5T6CPF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))
* USB-A male to USB-C male cable
* 2000 mAh LiPo battery discharged to 3.6V or less

## Test Steps

1. Attach battery to ezDV. Power off ezDV if necessary (i.e. if firmware has already been flashed).
2. Attach USB cable to ezDV and to the bench power supply.
3. Enable output on the DC bench supply.
4. Read current and voltage from bench supply's meters.

## Expected Results

ezDV should consume no more than 500 mA of current while charging as exceeding this violates the USB 2.0 specification. (Typically 250-300 mA per [TP4056 datasheet](https://dlnmh9ip6v2uc.cloudfront.net/datasheets/Prototyping/TP4056.pdf).) A red LED should also light on the bottom of the board indicating that charging is in progress.

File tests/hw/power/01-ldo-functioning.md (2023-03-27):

# LDO properly able to provide 3.3V

## Prerequisites

* Multimeter
* USB power supply
* USB cable (with one end being USB-C male)

## Test Steps

1. Attach USB cable to ezDV and the USB power supply.
2. Plug USB power supply into a working AC wall outlet.
3. Set multimeter to DC voltage mode (and if necessary, to a scale that includes 3.3V).
4. Probe pin 1 (positive lead) and pin 4 (negative lead) on J7 with the multimeter. *Note: pin 1 is towards the top of the board.*

## Expected Results

The multimeter should read 3.3V +/- 2% (3.23-3.37V). (See [NCP167 datasheet](https://www.onsemi.com/download/data-sheet/pdf/ncp167-d.pdf) for origin of expected output voltage range.)

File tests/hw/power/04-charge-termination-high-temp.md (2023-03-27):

# ezDV properly stops charging at high temperature

## Prerequisites

* USB power supply (either legacy USB 2.0 or USB-C PD capable)
* Cables as appropriate to attach ezDV to power supply
* LiPo battery that is partially discharged
* Heat gun

## Test Steps

1. Attach battery to ezDV. Power off ezDV if necessary (i.e. if firmware has already been flashed).
2. Attach USB cable to ezDV and to the power supply.
3. Turn on heat gun and apply heat to TH1 (lower right of U1). *WARNING: heat should only be applied briefly to prevent inadvertent desoldering!*

## Expected Results

The red charging LED at the bottom of the ezDV board should extinguish while heat is being applied and turn back on once the thermistor's temperature drops.

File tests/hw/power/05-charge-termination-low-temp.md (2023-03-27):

# ezDV properly stops charging at low temperature

## Prerequisites

* USB power supply (either legacy USB 2.0 or USB-C PD capable)
* Cables as appropriate to attach ezDV to power supply
* LiPo battery that is partially discharged
* Can of compressed air

## Test Steps

1. Attach battery to ezDV. Power off ezDV if necessary (i.e. if firmware has already been flashed).
2. Attach USB cable to ezDV and to the power supply.
3. Hold compressed air upside down and spray onto TH1 (lower right of U1).

## Expected Results

The red charging LED at the bottom of the ezDV board should extinguish while cold air is sprayed onto the thermistor and turn back on once the thermistor's temperature returns to room temperature.

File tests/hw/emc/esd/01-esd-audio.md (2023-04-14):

# ESD on audio jacks doesn't damage ezDV

## Prerequisites

* ESD gun ([low cost example](https://bartek.com/page/ESD.html))
* Aluminum sheet which to attach ground lead of ESD gun
* Non-conductive material to prevent ezDV from touching the sheet (e.g. styrofoam)
* Wired headset for testing

## Test Steps

1. Attach ground lead of the ESD gun to the aluminum sheet.
2. Place ezDV on top of the piece of non-conductive material, then place both onto the aluminum sheet.
3. Press and hold PTT and Mode on ezDV to enter hardware test mode. Ensure nothing is plugged into ezDV.
4. Place ESD gun 1cm or less from each audio jack, then press trigger 10 or more times to apply ESD current.
5. Plug in a wired headset to each audio jack and listen to the audio coming from ezDV.

## Expected Results

ezDV should continue to play audio on both audio jacks without rebooting or otherwise showing unusual behavior.

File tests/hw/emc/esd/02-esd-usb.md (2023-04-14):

# ESD on USB jack doesn't damage ezDV

## Prerequisites

* ESD gun ([low cost example](https://bartek.com/page/ESD.html))
* Aluminum sheet which to attach ground lead of ESD gun
* Non-conductive material to prevent ezDV from touching the sheet (e.g. styrofoam)
* PC for testing

## Test Steps

1. Attach ground lead of the ESD gun to the aluminum sheet.
2. Place ezDV on top of the piece of non-conductive material, then place both onto the aluminum sheet.
3. Press and hold PTT and Mode on ezDV to enter hardware test mode. Ensure nothing is plugged into ezDV.
4. Place ESD gun 1cm or less from the USB jack, then press trigger 10 or more times to apply ESD current.
5. Repeat [the USB enumeration test]()../../usb/01-usb-enumeration.md).

## Expected Results

ezDV can still be enumerated over USB by a PC without rebooting or showing other unusual behavior.

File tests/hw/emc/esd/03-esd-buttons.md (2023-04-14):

# ESD on buttons doesn't damage ezDV

## Prerequisites

* ESD gun ([low cost example](https://bartek.com/page/ESD.html))
* Aluminum sheet which to attach ground lead of ESD gun
* Non-conductive material to prevent ezDV from touching the sheet (e.g. styrofoam)

## Test Steps

1. Attach ground lead of the ESD gun to the aluminum sheet.
2. Place ezDV on top of the piece of non-conductive material, then place both onto the aluminum sheet.
3. Press and hold PTT and Mode on ezDV to enter hardware test mode. Ensure nothing is plugged into ezDV.
4. Place ESD gun 1cm or less from each button on the left hand side of the board, then press trigger 10 or more times to apply ESD current.
5. Repeat each of the button tests: [PTT](../../ui/01-ptt-button.md), [Mode](../../ui/02-mode-button.md), [Volume Up](../../ui/03-vol-up-button.md), [Volume Down](../../ui/04-vol-down-button.md).

## Expected Results

The buttons on ezDV can still be pressed. ezDV also doesn't show any unusual behavior while being zapped with the ESD gun.

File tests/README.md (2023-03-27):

# ezDV Test Suite

This folder contains test cases that need to pass in order to ensure that ezDV's hardware and firmware have acceptable quality. Each test is organized into a hierarchy of folders corresponding to the type of test (HW or FW) as well the subsystem being tested.

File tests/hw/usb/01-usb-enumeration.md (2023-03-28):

# ezDV can be properly enumerated by a USB host

## Prerequisites

* USB cable
* PC with USB ports

## Test Steps

1. Attach ezDV to a PC using a USB cable.
2. Use your operating system's USB tools to view information about ezDV. *Note: you may need to push and release the Reset button if ezDV is turned off.*

## Expected Results

The PC should detect ezDV as an "Espressif USB JTAG/serial debug unit". For example, `lsusb -v` on Linux will show something like the following:

```
Bus 003 Device 005: ID 303a:1001 Espressif USB JTAG/serial debug unit
Device Descriptor:
  bLength                18
  bDescriptorType         1
  bcdUSB               2.00
  bDeviceClass          239 Miscellaneous Device
  bDeviceSubClass         2 
  bDeviceProtocol         1 Interface Association
  bMaxPacketSize0        64
  idVendor           0x303a 
  idProduct          0x1001 
  bcdDevice            1.01
  iManufacturer           1 Espressif
  iProduct                2 USB JTAG/serial debug unit
  iSerial                 3 34:85:18:96:07:44
  bNumConfigurations      1
  Configuration Descriptor:
    bLength                 9
    bDescriptorType         2
    wTotalLength       0x0062
    bNumInterfaces          3
    bConfigurationValue     1
    iConfiguration          0 
    bmAttributes         0xc0
      Self Powered
    MaxPower              500mA
    Interface Association:
      bLength                 8
      bDescriptorType        11
      bFirstInterface         0
      bInterfaceCount         2
      bFunctionClass          2 Communications
      bFunctionSubClass       2 Abstract (modem)
      bFunctionProtocol       0 
      iFunction               0 
    Interface Descriptor:
      bLength                 9
      bDescriptorType         4
      bInterfaceNumber        0
      bAlternateSetting       0
      bNumEndpoints           1
      bInterfaceClass         2 Communications
      bInterfaceSubClass      2 Abstract (modem)
      bInterfaceProtocol      0 
      iInterface              0 
      CDC Header:
        bcdCDC               1.10
      CDC ACM:
        bmCapabilities       0x02
          line coding and serial state
      CDC Union:
        bMasterInterface        0
        bSlaveInterface         1 
      CDC Call Management:
        bmCapabilities       0x03
          call management
          use DataInterface
        bDataInterface          1
      Endpoint Descriptor:
        bLength                 7
        bDescriptorType         5
        bEndpointAddress     0x82  EP 2 IN
        bmAttributes            3
          Transfer Type            Interrupt
          Synch Type               None
          Usage Type               Data
        wMaxPacketSize     0x0040  1x 64 bytes
        bInterval               1
    Interface Descriptor:
      bLength                 9
      bDescriptorType         4
      bInterfaceNumber        1
      bAlternateSetting       0
      bNumEndpoints           2
      bInterfaceClass        10 CDC Data
      bInterfaceSubClass      2 
      bInterfaceProtocol      0 
      iInterface              0 
      Endpoint Descriptor:
        bLength                 7
        bDescriptorType         5
        bEndpointAddress     0x01  EP 1 OUT
        bmAttributes            2
          Transfer Type            Bulk
          Synch Type               None
          Usage Type               Data
        wMaxPacketSize     0x0040  1x 64 bytes
        bInterval               1
      Endpoint Descriptor:
        bLength                 7
        bDescriptorType         5
        bEndpointAddress     0x81  EP 1 IN
        bmAttributes            2
          Transfer Type            Bulk
          Synch Type               None
          Usage Type               Data
        wMaxPacketSize     0x0040  1x 64 bytes
        bInterval               1
    Interface Descriptor:
      bLength                 9
      bDescriptorType         4
      bInterfaceNumber        2
      bAlternateSetting       0
      bNumEndpoints           2
      bInterfaceClass       255 Vendor Specific Class
      bInterfaceSubClass    255 Vendor Specific Subclass
      bInterfaceProtocol      1 
      iInterface              0 
      Endpoint Descriptor:
        bLength                 7
        bDescriptorType         5
        bEndpointAddress     0x02  EP 2 OUT
        bmAttributes            2
          Transfer Type            Bulk
          Synch Type               None
          Usage Type               Data
        wMaxPacketSize     0x0040  1x 64 bytes
        bInterval               1
      Endpoint Descriptor:
        bLength                 7
        bDescriptorType         5
        bEndpointAddress     0x83  EP 3 IN
        bmAttributes            2
          Transfer Type            Bulk
          Synch Type               None
          Usage Type               Data
        wMaxPacketSize     0x0040  1x 64 bytes
        bInterval               1
Device Status:     0x0001
  Self Powered
```

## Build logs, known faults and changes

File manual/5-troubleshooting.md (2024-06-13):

# Troubleshooting

This section contains some helpful tips and information that may help you diagnose and fix any problems you may have with ezDV.

## Using Hardware Test Mode

ezDV has a hardware test mode that can be used to ensure that the board is functioning properly. To access this mode,
hold down the PTT button while turning on ezDV. Once ezDV starts, you will hear audio tones at 1275 Hz (user jack) and 
1725 Hz (radio jack) and all LEDs will be lit at 50% duty cycle. If the board is functioning properly, only the frequency
associated to the given jack (and harmonics, if square wave) will be in the output audio. Pushing the Mode button will cycle 
through the following:

* Sine tones at both jacks.
* Sine tone only on user jack.
* Sine tone only on radio jack.
* Square tones at both jacks.
* Square tone only on user jack.
* Square tone only on radio jack.
* No audio on either jack.

Additionally, pushing any of the buttons will extinguish the following LEDs if the buttons are properly functioning:

* PTT: PTT (red)
* Mode: Sync (green)
* Volume Up: Overload (red)
* Volume Down: Network (blue)

Releasing the button will re-illuminate the associated LED.

To shut down ezDV while in this mode, long-press the Mode button as with regular operation.

## Resetting ezDV

In the event that ezDV is non-responsive and needs to be reset, you can open the ezDV enclosure to gain access to two
buttons that are hidden in normal use. These are the Reset and Flash buttons as shown below:

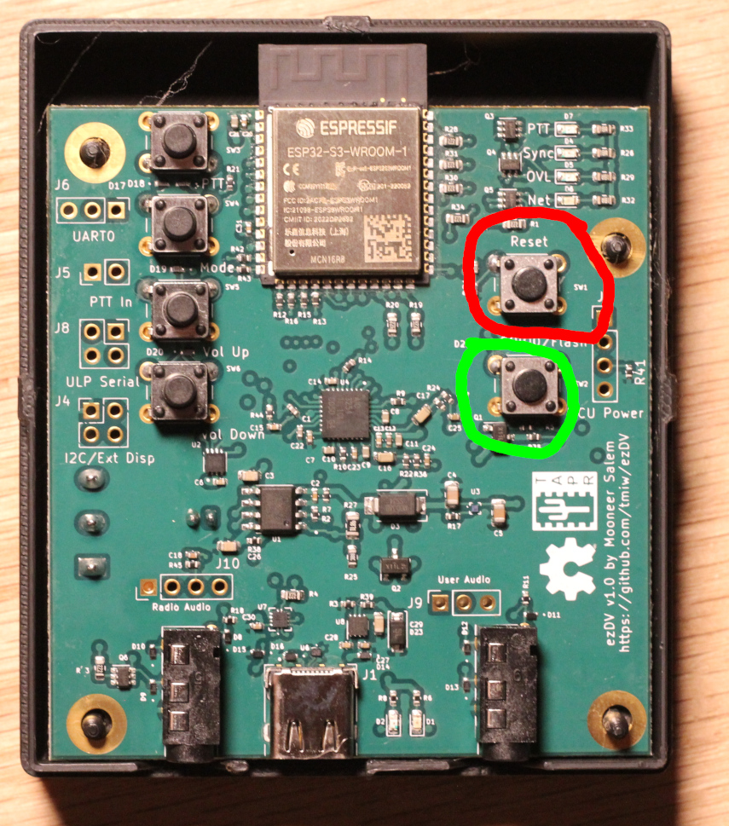
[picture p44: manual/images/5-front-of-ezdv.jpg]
Front of ezDV circuit board with Reset button (red circle) and Flash button (green circle) shown


Pressing and releasing the Reset button will cause ezDV to restart execution of its firmware. If the Flash button is held
while pressing and releasing the Reset button, the ESP32-S3 on ezDV will enter into "firmware download mode", which will allow
you to clear ezDV's internal memory and allow you to load a new copy of its firmware. To do this, you will need to plug ezDV into a USB
port on your PC and either install esptool, ESP-IDF or ESP Flash Tool onto your PC's hard drive.

### Using ESP-IDF to flash firmware

Download a copy of the ezDV firmware source code (typically listed as "Source code (zip)" or "Source code (tar.gz)" on the 
[project's release page](https://github.com/tmiw/ezDV/releases)). Decompress the file, change into the folder that is created,
then run the following commands to build and flash the firmware:

```
. ~/esp/esp-idf/export.sh
cd firmware
idf.py -p /dev/ttyxxx0 build erase-flash flash
```

Where `/dev/ttyxxx0` (or `COMx:` on Windows) is the serial port created by your operating system after plugging ezDV in. Once complete,
ezDV will automatically reboot and execute the firmware that's been flashed.

*Note: The above will erase all of your settings and reset them to defaults. If you don't want to do this, remove `erase-flash` from
the above command.*

### Using ESP Flash Tool

On Windows, you can use the ESP Flash Tool to flash ezDV. This does not require installation of ESP-IDF.

1. Download the ESP Flash Tool from [https://www.espressif.com/en/support/download/other-tools](https://www.espressif.com/en/support/download/other-tools).
2. Decompress all of the files in the ZIP file and execute flash\_download\_tool\_3.9.3.exe.
3. Select "ESP32-S3" for "ChipType", "Develop" for "WorkMode" and "USB" for "LoadMode" as shown below:

ESP Flash Tool step 3

4. Add rows for each of the .bin files in the resulting screen:

| File Name | Offset |
|---|---|
| bootloader.bin | 0x0 |
| partition-table.bin | 0x8000 |
| ota\_data\_initial.bin | 0xF000 |
| ezdv.bin | 0x20000 |
| http_0.bin | 0x7F8000 |

Additionally, check each of the checkboxes to the left of the file name. It should look something like this, with each of the rows having a green background:

ESP Flash Tool step 4

5. Set "SPI SPEED" to "80 MHz" and "SPI MODE" to "DIO".

6. Plug ezDV into your computer using a USB-C cable. Device Manager should show a new COM port named "USB/JTAG serial debug unit" or similar. Enter this COM port into the "COM" field in the application.

7. (Optional) Push the ERASE button. This will show a green "SYNC" indicator for a bit followed by "Download" and then "FINISH" as per the above screenshot. *Note: There will be no firmware installed on the board once this step finishes. You will need to reconfigure ezDV after new firmware has been flashed.*

8. Push the START button. This will go through the same indicators as step 1 but this time will also have a progress bar indicating how far it's gotten in flashing the new software. 

9. Push the STOP button and then close the application. Open the ezDV enclosure and briefly push/release the "Reset" button on the right hand side of the board. If everything went well, you'll see the four LEDs light up for a few seconds indicating that ezDV is booting normally.

### Using esptool

You can also use [esptool](https://github.com/espressif/esptool). For example:

```
esptool esp32s3 -p /dev/cu.usbmodem14101 -b 460800 --before=default_reset --after=hard_reset write_flash --flash_mode dio --flash_freq 80m --flash_size detect 0x0 bootloader.bin 0x20000 ezdv.bin 0x8000 partition_table/partition-table.bin 0xf000 ota_data_initial.bin 0x7f8000 http_0.bin
```

## Common problems

| Problem | Suggested Solutions |
|---|---|
| No audio coming in via headset | * Use the Volume Up button to increase ezDV's volume.<br/>* Plug headset into another device and verify that you can hear audio.<br/>* Change ezDV mode to "ANA" (analog passthrough) and verify audio is coming from radio. |
| ezDV unable to connect to Wi-Fi network | * Place ezDV closer to router/access point.<br/>* Turn on ezDV while holding Volume Down and verify configuration in the web interface. |
| ezDV unable to connect to network-enabled radio (e.g. Flex radio or Icom IC-705) | * Make sure that ezDV is connected to the correct Wi-Fi network (blinking blue LED).<br/>* Verify correct radio configuration in the web interface.<br/>* Place ezDV and/or radio closer to router/access point (if possible).<br/>* Power cycle/reboot ezDV and/or radio. |
| ezDV does not put the radio into transmit | * Verify wiring of radio interface cable<br/>* Verify that ezDV is properly connected to its configured network-enabled radio. |
| ezDV is overdriving radio/amplifier on transmit (i.e. ALC is indicating) | * Use Volume Down button while transmitting to reduce transmit power level.<br/>* Verify power settings on radio. |
| Radio is not transmitting audio from ezDV | * Use Volume Up button while transmitting to increase transmit power level.<br/>* Verify that current radio mode uses audio from ezDV (for example, putting radio into "data" mode).<br/>* Verify that ezDV is connected to the radio (if network-enabled). |
| ezDV is not connecting to FreeDV Reporter | * Verify that ezDV is connected to Wi-Fi network with internet access.<br/>* Verify that callsign and grid square are configured in ezDV.<br/>* Verify that ezDV is connected to network-enabled radio (solid blue LED).<br/>* Verify that "Force reporting without radio connection" in web interface is enabled (if not using a network-enabled radio). |
| ezDV is not reporting to PSK Reporter | * Verify that ezDV is connected to Wi-Fi network with internet access.<br/>* Verify that callsign and grid square are configured in ezDV.<br/>* Verify that ezDV is connected to network-enabled radio (solid blue LED).<br/>* Verify that "Force reporting without radio connection" in web interface is enabled (if not using a network-enabled radio). |
| ezDV web interface only partially loads | * Use web browser's "reload" button to refresh the web interface.<br/>* Move ezDV closer to router/access point or the PC/mobile device being used. |
| Multiple "FDVU" modes display in SmartSDR | ezDV likely briefly lost connection to the radio. This does not normally cause problems* but you can power cycle your Flex radio to clean up the extra modes if needed. |

\* A known issue in the Flex radio firmware causes the radio to crash if ezDV attempts to unregister itself. To avoid the crash, ezDV's unregistration logic has been disabled. This logic will be reenabled at a future date.

## Getting assistance

If you have a problem that is not already covered in this manual, you can obtain help through several sources:

* [digitalvoice mailing list](https://groups.google.com/g/digitalvoice): This is the official FreeDV mailing list covering the FreeDV mode generally as well as FreeDV software and hardware devices such as ezDV.
* GitHub: You can [create a GitHub issue](https://github.com/tmiw/ezDV/issues) to report bugs or request feature enhancements. Note that this requires a GitHub account.

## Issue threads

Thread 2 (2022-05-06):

Evaluate and increase sizes of power traces

tmiw, 2022-05-06:
Some power traces may be insufficiently wide for the current being drawn. Investigate to confirm and update the PCB accordingly.

tmiw, 2022-05-29:
After rerouting of the PCB, the default trace width (0.25mm) was found to be sufficient for up to 1A of current at the top layer. The TLV320 as well as other components are unlikely to consume anywhere close to this current, so the issue can be closed.

Closed 2022-05-29.

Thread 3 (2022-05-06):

Remove button pullup resistors

tmiw, 2022-05-06:
The ESP32-S3 has internal pullups which may make R9, R12, R13 and R15 unnecessary. Evaluate and remove if those internal pullups are usable.

tmiw, 2022-05-28:
Closing for now as the current pullups seem to work okay.

Closed 2022-05-28.

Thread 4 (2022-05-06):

Evaluate size of I2C pullups

tmiw, 2022-05-06:
The I2C pullup resistors (R2 and R8) are currently 4.7K. This may be insufficient depending on how fast we drive the I2C bus. Investigate and increase the resistance if necessary.

tmiw, 2022-05-28:
I2C bus is able to be driven at 100KHz using 4.7K, so keeping as is.

Closed 2022-05-28.

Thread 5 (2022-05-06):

Add mounting holes for the dev board

tmiw, 2022-05-06:
v0.1 does not have any mounting holes. Adding some will eventually be needed for the final version or even future dev boards, so evaluate to determine what size/how many is appropriate.

Closed 2022-05-29.

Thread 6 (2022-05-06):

Evaluate and adjust resistor sizes for LEDs

tmiw, 2022-05-06:
The currents through each of the LEDs on v0.1 (R10, R14, R17 and R20) may produce dramatically different brightness levels. We can use PWM as a workaround but these should be readjusted based on the selected LEDs so that the brightness is approximately equal.

Closed 2022-05-29.

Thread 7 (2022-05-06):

Fix silkscreen readability issues

tmiw, 2022-05-06:
The EMC vias added just prior to sending the board to JLCPCB are interfering with some of the sillkscreen items. Move or delete the vias as appropriate so that the text is readable.

Closed 2022-05-29.

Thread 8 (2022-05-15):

Consider making R1 1k to increase mic bias current

tmiw, 2022-05-15:
Currently R1 is 2.7k (derived from the typical application schematic for the TLV320). However, this only allows 1mA of current to the microphone; the Android specs indicate 1.8-2.9 mA according to [this post](https://webcache.googleusercontent.com/search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). A 1k resistor instead would result in 2.5mA of current @ 2.5V, which would be within spec.

Closed 2022-05-29.

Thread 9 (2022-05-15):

Move I2C SCL to GPIO 45

tmiw, 2022-05-15:
v0.1 of the board has SCL on GPIO 48. However, the nanoESP32-S3 is apparently using that for its RGB LED. Cutting off the pin on the board for GPIO 45 and bodging the pin next to it to 45 allowed I2C to work properly.

Closed 2022-05-29.

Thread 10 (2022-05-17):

60Hz noise getting into headset mic line

tmiw, 2022-05-17:
Testing of the v0.1 boards show that significant 60Hz noise is getting into the mic line on the headset jack. The radio jack is working properly, however. For v0.2, we need to reroute this trace to shorten it and provide more shielding.

tmiw, 2022-06-25:
Looks like this was a firmware issue and not a HW issue. Still, v0.2 was worthwhile to spin. 👍

Closed 2022-06-25.

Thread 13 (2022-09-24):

Transition away from GitHub

tmiw, 2022-09-24:
As other FreeDV projects are transitioning away from GitHub, ezDV probably should too (context [here](https://sfconservancy.org/blog/2022/jun/30/give-up-github-launch/)). This issue is being created to track this task.

TODO:

* Research Git hosting providers (GitLab, SFC's own, etc.)
* Select Git hosting provider (w/vote by the Leadership Team)
* Clone current repo at new provider
* Re-enable/port CI tasks as appropriate
* Add link from GitHub to new location
* Make repository read-only mirror of new location
* Determine future date when to delete GitHub repository entirely

Related issues on other projects: codec2 (https://github.com/drowe67/codec2/issues/354), LPCNet (https://github.com/drowe67/LPCNet/issues/46), freedv-gui (https://github.com/drowe67/freedv-gui/issues/281)

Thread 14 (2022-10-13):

Thermistor is on incorrect GPIO pin

tmiw, 2022-10-13:
Oops. Turns out that the ADC only works on GPIOs 1-20 on the ESP32-S3. Reassign GPIO appropriately for next board spin.

tmiw, 2022-10-15:
Bodging to GPIO 18 for now. Final placement will be on v0.5 board.

tmiw, 2022-12-23:
Change has been integrated as of v0.5.

Closed 2022-12-23.

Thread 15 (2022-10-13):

High power consumption while off

tmiw, 2022-10-13:
Measuring ~890uA on v0.4 when turned off and USB is not plugged in. Per component datasheets, we should be seeing about 1/4-1/3 of that amount of consumption.

tmiw, 2022-12-23:
There were several causes:

1. The ULP coprocessor consumes more power than initially thought. SW changes (putting fuel gauge chip into hibernate manually as well as only activating the ULP 10x/sec to check the Mode button state) cut power consumption from ~770 uA to ~365 uA.
2. The pullup for `TLV320_RESET` was attached to `3.3V` instead of `3.3V_PERIPH`, causing ~300+ uA of leakage current to flow through the TLV320/ESP32 to the rest of the system. Desoldering R17 on v0.5 cut power consumption to ~50 uA after performing the changes in (1).

R17 has been removed in the schematic in `master` and will be integrated in the next board spin. While the board now meets the target (>= 1 year powered off before a 2000 mAh battery dies), there is still room for further improvement through selection of a different LDO. Keeping this issue open until we decide whether the LDO should be replaced.

tmiw, 2023-02-19:
v0.6 brought this down to ~25uA, so we can close this issue now.

Closed 2023-02-19.

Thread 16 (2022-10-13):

Microphone noise with TLV320 headset detection turned on

tmiw, 2022-10-13:
With headset detection turned on, there's some sort of background noise in the audio while in loopback mode. May need to inspect this part of the circuit again and ensure any RFI, etc. is taken care of.

tmiw, 2022-12-23:
Rerouted headset detect trace in v0.5 and resolved this issue.

Closed 2022-12-23.

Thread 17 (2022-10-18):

Move LED/PTT GPIO to RTC GPIO

tmiw, 2022-10-18:
Some LEDs are on dimly in sleep mode, which could be contributing to the high power consumption (see #15). For v0.5, we should switch the GPIOs around to avoid this issue.

tmiw, 2022-12-23:
LEDs are controlled via `3.3V_PERIPH` as of HW revision v0.5.

Closed 2022-12-23.

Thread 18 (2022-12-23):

Network LED much dimmer than the others

tmiw, 2022-12-23:
After desoldering R17 (see #15), I noticed that the network LED was much dimmer than the others. As a workaround, I enabled PWM on the LED GPIOs (https://github.com/tmiw/ezDV/commit/b49d4518e9d7d4edd33408c669c34078d787b349) and set it to ~10% duty cycle to minimize the dimming.  Needs more investigation to determine if there's a hardware problem.

tmiw, 2022-12-26:
Appears to be a firmware bug, fixed as of https://github.com/tmiw/ezDV/commit/c7b59d29f85121c067ee88c8e6f6925c029a9a6f.

Closed 2022-12-26.

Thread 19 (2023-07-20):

Crypto support + PCB manufacturing procedure

danielebruneo, 2023-07-20:
Hi,
I've been following your project and loving all the work you've done.

This overlap perfectly with a project I was researching on: building a crypto transciever based on an ESP (something similar to what aarmono did here: https://github.com/aarmono/crypto_transceiver_instructions but cheaper and smaller).

I would then like to start contributing to your project, maybe trying to port the work aarmono did on top of codec2 to build encryption support. (Is this something you were already thinking about, maybe?)

First thing, though, I'd need to get some hardware to develop with.

Any chance there is a ready-to-go package or instructions to get a set of pcb manufactured by any PCBA provider?

oh2lak, 2023-07-20:
What is the need for encryption, as amateur radio traffic in 99% of the
countries do not allow encryption?

Br,
Erik OH2LAK

On Thu, 20 Jul 2023 at 12:32, danielebruneo ***@***.***>
wrote:

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

tmiw, 2023-07-20:
The BOM is built into the KiCad files, but there are specific settings you have to choose at JLCPCB to have it built properly. I'll write up a document on that when I have time (likely not until at least next week).

As for crypto support, I'll leave it to @danielebruneo's fork as ezDV itself is intended for amateur radio use.

tmiw, 2024-05-18:
Closing as dupe of #21.

Closed 2024-05-18.

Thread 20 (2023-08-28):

More options for the FreeDV (int) Reporter

barjac, 2023-08-28:
Since the QST article about FreeDV has been published it has become clear that the reporter needs to have more fine grained setting options.
It's great to see more stations on the bands, but on 20m especially the reporter is becoming difficult to read in use.
Suggestions:
1 A filter to remove calls that have not been updated in the last N mins.
2 An option to only display (or highlight?) calls who have received me in the last N mins).
3 Show my own call line in a different colour.
4 An option to switch the reporter band filter automatically to the currently reported band (but only when that changes). i.e. The reporter band selector would still over-ride.

Just few ideas for discussion ;)

tmiw, 2023-08-28:
Please create this in the main freedv-gui repo instead as this has to do with functionality in that application. ezDV, while it does support reporting to FreeDV Reporter, has no internal display capability.

Closed 2023-08-28.

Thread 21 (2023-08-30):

ezDV build process document

g0kao, 2023-08-30:
Suggested starter for documenting the build process for the ezDV module based on HW Version 0.7 and my experience so far.
[ezDV Build Process.pdf](https://github.com/tmiw/ezDV/files/12474881/ezDV.Build.Process.pdf)
I couldn't create a pull request to have it reviewed, possibly not authorised for this project
hope it is useful and review comments welcomed
I generated in Text Edit on the Mac and exported to PDF to add it here
Paul

tmiw, 2023-08-31:
Thanks for this! I'll take a closer look when I have a chance. There might be the possibility of having JLCPCB fully assemble the boards (so you'd only need to buy the battery separately) so the instructions will likely need modification when that happens.

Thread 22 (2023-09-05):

WiFi unable to disable

g0kao, 2023-09-05:
Testing the ezDV module using two radios, one IC-705 the other a Yaesu FTdx10, Wifi enabled for the 705 which seems to be working ok, but when trying to focus efforts on the dx10, am unable to disable the WiFi connectivity for the radio.
Whenever i untick the option for WiFi connectivity and try to save, it reverts back to previous settings without unticking the WiFi option.
Have to disable WiFi on the 705 to force connectivity to work with the dx10
Have updated to latest version of code just released via ota but no change in the WiFi issue

tmiw, 2023-09-05:
Do you see any red or green popup boxes on the page after you press Save? If you see a green "success" type message, keep in mind that Wi-Fi changes require a power cycle (or pushing the Reboot button in the web UI) to take effect.

g0kao, 2023-09-05:
I untick the wifi check box, the config clears, I click the Save button, the module resets itself
when it comes back online the wifi is still enabled.
I did an ota update with the new release but it didn.t change anything, should I try a fresh full reflash perhaps?

g0kao, 2023-09-05:
I reflashed the module as discussed, I haven't connected to the ic-705, i just enabled the wifi, reset the module, then when it came back I attempted to disable wifi to the radio and the same steps occurred as outlined above, wifi not disable to the radio. going to try something else like disabling wifi completely from the module as a complete reset of the wifi code and see what happens

g0kao, 2023-09-05:
Nope, cannot disable wifi either, very strange, if i click the reset button on the wifi radio page, it defaults to some preconfigured default info, the black circle continues circling with no other prompts, it appears that once configured it cannot be undone without a reflash for me anyway. I  have one last ditch idea, will let you know what happens

g0kao, 2023-09-05:
attached is a putty log, tried to disable radio wifi, didn't work, then tried to disable wifi as a service, that did not work either
[putty-ezDV-wifi-issue.txt](https://github.com/tmiw/ezDV/files/12525971/putty-ezDV-wifi-issue.txt)

tmiw, 2023-09-06:
Give tonight's release a shot and let me know how it goes: https://github.com/tmiw/ezDV/releases/tag/20230905

g0kao, 2023-09-06:
Thanks Mooneer, that has fixed the problem, I can disable wifi or the wifi radio connection and re-enable the radio connection as needed, thanks again

Closed 2023-09-06.

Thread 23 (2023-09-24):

revised enclosure top and buttons

g0kao, 2023-09-24:
Having had the enclosure built for me I discovered that when the module v0.7 was fitted, the top did not fit due to the headers fitted to the pcb, as a result I have adjusted the height of the top and the length of the buttons to cater for the new case height.
Attached are new scad files that I have created and successfully printed to fit this module.
enclosure-lid.scad
enclosure-button-v3.scad
[enclosure-new-files.zip](https://github.com/tmiw/ezDV/files/12709445/enclosure-new-files.zip)

tmiw, 2023-09-25:
Thanks for these. How are you routing the cables attached to the headers out? I didn't see any additional holes when I opened them in OpenSCAD.

g0kao, 2023-09-25:
On mine I haven't created any holes for leads to come out from headers, managed connectivity via audio TRRS sockets for DX10 and wifi for ic-705. When original case was made I drilled a hole in the lid directly above the dc connection for the battery and chopped the header pins down so the lid would fit enough with the help of electrical tape to hold it together :-)
Need to make a fix so that the 3d printed buttons don't fall out when the module is tipped over, I think some tiny rubber o-rings should do it if I can find some small enough :-)
Attached is pic of my completed module using the files uploaded on my 3d printer
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

tmiw, 2023-09-25:
Ah, okay. I actually intended the headers to be optional since most will either be using the 3.5mm jacks and/or Wi-Fi, but it won't hurt to update the main OpenSCAD files with an extra flag that can be set to print the bigger case.

Re: O-rings, that sounds like a pretty good idea. I was thinking post-processing by adding tiny dabs of glue to the bottoms of the buttons but that precludes removing them later :)

tmiw, 2023-09-26:
I integrated the changes you provided into the main `enclosure.scad` file. The taller enclosure can be requested by setting the below (near the top of the file) to true:

```
// Whether to print a taller enclosure to fit e.g. pin headers.
// Note: this weirdly has to be above the include line for some reason.
printTallerEnclosure = false;
```

and likewise for `enclosure-button.scad`:

```
// Whether to print a taller buttons (typically used when printing the taller enclosure).
printTallerButtons = false;
```

Let me know if that doesn't work for you and I can reopen and investigate further.

Closed 2023-09-26.

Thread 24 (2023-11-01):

System stuck if no MAX17048 is used

onemikedelta, 2023-11-01:
I planned to use this module without battery. Everything works however, if I try to connect web interface system reboots.
Library shouldn't try to read battery if ic is not found during boot process.
`
I (22945) ButtonArray: Button VolDown now 0
I (23925) SettingsTask: Committing pending settings to flash.
I (40405) wifi:new:<1,0>, old:<1,1>, ap:<1,1>, sta:<255,255>, prof:1
I (40405) wifi:station: 12:34:56:78:90:AB join, AID=1, bgn, 20
I (40405) WirelessTask: Wifi event: 14
I (40535) wifi:<ba-add>idx:2 (ifx:1, 12:75:8d:8e:1d:67), tid:0, ssn:0, winSize:64
I (40745) esp_netif_lwip: DHCP server assigned IP to a client, IP is: 192.168.4.2
I (40765) DVTask: Task FlexVitaTask started
I (57075) HttpServerTask: Sending file : /bootstrap.min.css.gz (27324 bytes)...
I (57195) HttpServerTask: File sending complete
I (57285) HttpServerTask: Sending file : /localstyle.css (3249 bytes)...
I (57295) HttpServerTask: File sending complete
I (57385) HttpServerTask: Sending file : /bootstrap.bundle.min.js.gz (23265 bytes)...
I (57485) HttpServerTask: File sending complete
I (57495) HttpServerTask: Sending file : /jquery-3.6.1.min.js.gz (30850 bytes)...
I (57625) HttpServerTask: File sending complete
I (57715) HttpServerTask: Sending file : /localscript.js (22156 bytes)...
I (57845) HttpServerTask: File sending complete
I (57885) HttpServerTask: Websocket connection opened
I (57885) HttpServerTask: Sending JSON message to socket 57
I (57885) HttpServerTask: Sending JSON message to socket 57
I (57885) HttpServerTask: Sending JSON message to socket 57
I (57895) HttpServerTask: Sending JSON message to socket 57
I (57895) HttpServerTask: Sending JSON message to socket 57
I (57895) HttpServerTask: Sending JSON message to socket 57
I (57905) HttpServerTask: Sending JSON message to socket 57

assert failed: void ezdv::driver::MAX17048::onRequestBatteryStateMessage_(ezdv::task::DVTask*, ezdv::driver::RequestBatteryStateMessage*) MAX17048.cpp:215 (success)

Backtrace: 0x40376016:0x3fca9000 0x40380f31:0x3fca9020 0x40388c26:0x3fca9040 0x42015eca:0x3fca9160 0x42127fca:0x3fca91e0 0x42016639:0x3fca9200 0x42016649:0x3fca9230 0x420162a9:0x3fca9250 0x420162bf:0x3fca9280 0x42022369:0x3fca92a0 0x420223d6:0x3fca92f0 0x42022415:0x3fca9310 0x4038459d:0x3fca9330

------------------
I (1202) MAX17048: Checking for device...
W (1302) MAX17048: Device not found; battery monitoring disabled.
I (1302) DVTask: Task MAX17048 started
I (1312) DVTask: Task LedArray started
I (1322) gpio: GPIO[4]| InputEn: 0| OutputEn: 0| OpenDrain: 0| Pullup: 1| Pulldown: 0| Intr:0
I (1322) gpio: GPIO[5]| InputEn: 0| OutputEn: 0| OpenDrain: 0| Pullup: 1| Pulldown: 0| Intr:0
I (1322) gpio: GPIO[6]| InputEn: 0| OutputEn: 0| OpenDrain: 0| Pullup: 1| Pulldown: 0| Intr:0
I (1322) gpio: GPIO[7]| InputEn: 0| OutputEn: 0| OpenDrain: 0| Pullup: 1| Pulldown: 0| Intr:0
I (1322) gpio: GPIO[0]| InputEn: 0| OutputEn: 0| OpenDrain: 0| Pullup: 1| Pulldown: 0| Intr:0
I (1322) DVTask: Task ButtonArray started
I (1332) TLV320Driver: reset TLV320
I (1332) TLV320Driver: configure clocks
I (1342) TLV320Driver: configure processing blocks
I (1342) TLV320Driver: configure LDOs
I (1342) TLV320Driver: configure routing for ADC
I (1352) TLV320Driver: configure routing for DAC
I (1602) ButtonArray: Button UsbPower now 1
I (3182) TLV320Driver: configuring interrupts
I (3182) gpio: GPIO[12]| InputEn: 0| OutputEn: 0| OpenDrain: 0| Pullup: 1| Pulldown: 0| Intr:0
I (3182) gpio: GPIO[14]| InputEn: 0| OutputEn: 0| OpenDrain: 0| Pullup: 1| Pulldown: 0| Intr:0
I (3182) TLV320Driver: all audio codec config complete
I (3182) DVTask: Task TLV320Driver started
W (3202) TLV320Driver: ADC overload! (Left/User = 1, Right/Radio = 0)
I (3292) DVTask: Task FreeDVTask started
I (3302) DVTask: Task AudioMixer started
I (3302) TLV320Driver: button state: 10
I (3312) DVTask: Task BeeperTask started
I (3322) VoiceKeyerTask: Starting VoiceKeyerTask
I (3322) DVTask: Task VoiceKeyerTask started
I (3332) UserInterfaceTask: Sending welcome message to beeper
I (3332) DVTask: Task UserInterfaceTask started
I (3332) BeeperTask: Got beeper message   ANA
I (3342) DVTask: Task WirelessTask started
I (3342) DVTask: Task MainApp started
I (3352) SettingsTask: Initializing NVS.
I (3352) SoftwareUpdateTask: Starting SoftwareUpdateTask
I (3352) DVTask: Task SoftwareUpdateTask started
I (3352) SettingsTask: Opening NVS handle.
I (3352) SettingsTask: leftChannelVolume: 10
I (3352) SettingsTask: rightChannelVolume: -35
I (3352) SettingsTask: wifiEnabled: 0
I (3352) SettingsTask: wifiMode: 0
I (3352) SettingsTask: wifiSecurity: 0
I (3352) SettingsTask: wifiChannel: 1
I (3352) SettingsTask: wifiSsid:
I (3362) TLV320Driver: Volume control: setting volume on register 65 to 10
I (3362) SettingsTask: wifiPassword: ********
I (3362) SettingsTask: radioEnabled: 0
I (3362) SettingsTask: headsetPtt: 0
I (3362) SettingsTask: timeOutTimer: 120
I (3362) SettingsTask: radioType: 0
I (3362) SettingsTask: radioHostname:
I (3362) SettingsTask: radioPort: 0
I (3362) SettingsTask: radioUsername:
I (3362) SettingsTask: radioPassword: ********
I (3362) UserInterfaceTask: Disallowing headset button from toggling PTT.
I (3362) SettingsTask: enableVoiceKeyer: 0
I (3362) SettingsTask: voiceKeyerNumberTimesToTransmit: 10
I (3362) SettingsTask: voiceKeyerSecondsToWaitAfterTransmit: 5
I (3362) SettingsTask: callsign:
I (3362) SettingsTask: gridSquare: UN00KN
I (3362) SettingsTask: ledDutyCycle: 8192
I (3362) SettingsTask: lastMode: 3
I (3362) DVTask: Task SettingsTask started
I (3362) FreeDV: Setting FreeDV mode to 3
I (3362) BeeperTask: Got beeper message   1600
I (3372) TLV320Driver: Volume control: setting volume on register 66 to -35

`

tmiw, 2023-11-01:
ezDV is intended for use with a battery. Did you simply not populate the chip when you built it, or did you make additional changes?

Regardless, there is logic in there to detect the presence of the MAX17048 but the result of that is apparently getting ignored. That should hopefully be a quick fix that I can get to tonight.

tmiw, 2023-11-02:
This should be fixed in 2f396cb. Please confirm and I can go ahead and close. Thanks for letting me know!

onemikedelta, 2023-11-02:
You are welcome, thank you for such a fast action. It works normal now. I didn't populated the chip on one pcb.
I tryed to solder on another pcb but it completely stopped booting.

`I (668) sleep: Configure to isolate all GPIO pins in sleep state
I (669) sleep: Enable automatic switching of GPIO sleep configuration
I (669) app_start: Starting scheduler on CPU0
I (669) app_start: Starting scheduler on CPU1
I (669) main_task: Started on CPU0
I (679) esp_psram: Reserving pool of 63K of internal memory for DMA/internal all                                     ocations
I (679) main_task: Calling app_main()
I (779) gpio: GPIO[1]| InputEn: 0| OutputEn: 0| OpenDrain: 0| Pullup: 1| Pulldow                                     n: 0| Intr:0
I (779) gpio: GPIO[2]| InputEn: 0| OutputEn: 0| OpenDrain: 0| Pullup: 1| Pulldow                                     n: 0| Intr:0
I (779) gpio: GPIO[15]| InputEn: 0| OutputEn: 0| OpenDrain: 0| Pullup: 1| Pulldo                                     wn: 0| Intr:0
I (779) gpio: GPIO[21]| InputEn: 0| OutputEn: 0| OpenDrain: 0| Pullup: 1| Pulldo                                     wn: 0| Intr:0
I (779) gpio: GPIO[16]| InputEn: 0| OutputEn: 0| OpenDrain: 0| Pullup: 1| Pulldo                                     wn: 0| Intr:0
I (779) app: Wakeup reason: 0
I (779) app: Power up mode: 2773393973
I (779) app: Woken up via ULP, booting...
I (779) main_task: Returned from app_main()
I (789) app: onTaskStart_
I (809) gpio: GPIO[3]| InputEn: 0| OutputEn: 0| OpenDrain: 0| Pullup: 1| Pulldow                                     n: 0| Intr:0
I (809) gpio: GPIO[9]| InputEn: 0| OutputEn: 0| OpenDrain: 0| Pullup: 1| Pulldow                                     n: 0| Intr:0
I (809) gpio: GPIO[10]| InputEn: 0| OutputEn: 0| OpenDrain: 0| Pullup: 1| Pulldo                                     wn: 0| Intr:0
I (809) gpio: GPIO[11]| InputEn: 0| OutputEn: 0| OpenDrain: 0| Pullup: 1| Pulldo                                     wn: 0| Intr:0
I (809) gpio: GPIO[12]| InputEn: 0| OutputEn: 0| OpenDrain: 0| Pullup: 1| Pulldo                                     wn: 0| Intr:0
I (809) gpio: GPIO[14]| InputEn: 0| OutputEn: 0| OpenDrain: 0| Pullup: 1| Pulldo                                     wn: 0| Intr:0
I (809) gpio: GPIO[13]| InputEn: 0| OutputEn: 0| OpenDrain: 0| Pullup: 1| Pulldo                                     wn: 0| Intr:0
I (809) gpio: GPIO[0]| InputEn: 0| OutputEn: 0| OpenDrain: 0| Pullup: 1| Pulldow                                     n: 0| Intr:0
I (819) gpio: GPIO[7]| InputEn: 0| OutputEn: 0| OpenDrain: 0| Pullup: 1| Pulldow                                     n: 0| Intr:0
I (819) gpio: GPIO[4]| InputEn: 0| OutputEn: 0| OpenDrain: 0| Pullup: 1| Pulldow                                     n: 0| Intr:0
I (829) MAX17048: Checking for device...
E (1829) DVTask: Was waiting for MAX17048 but timed out
W (1929) MAX17048: Device not found; battery monitoring disabled.
I (1929) DVTask: Task MAX17048 started

assert failed: void ezdv::task::DVTask::waitForOurs_(ezdv::task::DVTask*, TickTy                                     pe_t) [with ControlMessageType = ezdv::task::TaskControlCommon<3>; TickType_t =                                      long unsigned int] DVTask.h:346 (found)

Backtrace: 0x4037677a:0x3fcbca90 0x4038124d:0x3fcbcab0 0x40388faa:0x3fcbcad0 0x4                                     2021cdd:0x3fcbcbf0 0x42021d59:0x3fcbcc20 0x4200ac8c:0x3fcbcc60 0x42020e96:0x3fcb                                     cca0 0x42122b9d:0x3fcbccd0 0x42020559:0x3fcbcd00 0x4202111a:0x3fcbcd30 0x4202122                                     2:0x3fcbcd80 0x4202127d:0x3fcbcda0 0x40381c01:0x3fcbcdc0
`

tmiw, 2023-11-02:
I added a bit more timeout for the MAX17048 task based on my testing here with an earlier version that doesn't have the MAX17048. Hopefully that helps!

onemikedelta, 2023-11-02:
Now the battery part works perfect. Thank you again, 73

Closed 2023-11-02.

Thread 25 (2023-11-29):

Analog Bypass Feature

onemikedelta, 2023-11-29:
Analog Bypass
If we switch IN1_L and IN1_R in the future versions, it looks like we may have a low power analog bypass mode, which will reduce latency and we can put esp32 into sleep mode to save power.

We may add speaker amplifier to LOL line and internal mic to one of the available inputs, (preferably analog routable one). So, the device can be usable as an ordinary hand mike. I have added LM4871MX on my pcb and routed LOL to this pin, it works nice. We only need to implement some amplifier enable signal other than Sync output because this output flickers a lot and continuously turn amplifier on and off. I have tryed headphone detect interrupt to switch headphone/speaker channels however it is not working, probably allways connected radio channel is preventing that, not sure atm.

Just a few ideas, 73

tmiw, 2023-11-29:
I remember the TLV320 being pretty low power even without using its analog bypass mode. The ESP32-S3 (and the status LEDs to a smaller extent) by far use most of the power. That said, using the mixer amps may be possible for RX; see below from the Application Reference Guide:

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

(Basically, set HPL to MAR, which comes from IN1_R.)

However, on TX, the ESP32 would probably have to come back online to take back control of audio routing, which will take a second or two if coming from ULP sleep. Not sure users would be okay with that, to be honest.

onemikedelta, 2023-11-29:
The problem is we cannot route microphone to the radio in this configuration if I am not missing a path. MAL to HPR is not supported. For the PTT, we may introduce a simple diode from radio PTT to PTT button. Only thing that is not going to work is PTT LED. I haven't tryed to setup interrupt for button and use GPIO21 yet. Maybe we can achieve this ptt system without waking up mcu completely by using ULP.

tmiw, 2023-11-29:
I don't have the schematic in front of me but I think the PTT output pin is one that can be manipulated in ULP. Would just need hardware changes to enable the proper routing if you did want to be able to support low powered analog.

That said, switching from that mode would likely still take a few seconds, but that might still be okay. Let's put this on hold for now and consider for ezDV V2.

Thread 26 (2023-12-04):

Reporting page - add ability to report via reporter the current mode and frequency

g0kao, 2023-12-04:
A thought just came to me as I was using the module with my FTdx10 connected via rear port. The module doesn't report to FreeDV Reporter when being used as we have previously discussed when I was initially testing.
Could the module reporting page where Callsign and Locator are configured be updated to allow entry of Frequency and Mode currently being used?  most people will be using their computer maybe to change modes or just keep an eye on battery levels so would be a useful way of enabling reporting via reporter at the same time for those where the rigs cannot communicate to the module their settings.

tmiw, 2023-12-06:
Give https://github.com/tmiw/ezDV/releases/tag/20231206 a shot and let me know how it goes. If you have problems with that, I can go ahead and reopen this bug for further investigation.

Closed 2023-12-06.

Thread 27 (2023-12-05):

Analog Mode Rx not working after Tx

onemikedelta, 2023-12-05:
In analog mode audio routing is ok after device reset. Transmit is also ok. However, It is not routing back the radio audio to the user audio.
Used firmware: ezdv-20231122-full

tmiw, 2023-12-05:
I believe https://github.com/tmiw/ezDV/commit/89552ddb52b05465ed2de981ccec28808de11187 will fix this based on my testing with SmartSDR and the Flex 6300 here. The issue was that there was logic missing to return to RX mode when in analog; I suspect if you push the Mode button after letting go of PTT to switch to e.g. 700D (and then go back to analog), RX will start working fine again.

Anyway, feel free to update here if it's still not solved after the next FW update and I'll reopen and investigate further.

Closed 2023-12-05.

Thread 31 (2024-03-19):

ezDV does not unregister itself from SmartSDR

tmiw, 2024-03-19:
Currently there is logic in ezDV (in `FlexTcpTask.cpp`) that unregisters itself from Flex radios when shutting down, and could presumably be run as well after a brief disconnection. However, when running this logic, the radio itself crashes. Thus, in the current FW, this logic is disabled.

The crash is being tracked by FlexRadio as SMART-9473 and this issue will be open until confirmed to be fixed (and the logic can be reenabled).

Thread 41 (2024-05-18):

Add references to FlexRadio 8000 series

tmiw, 2024-05-18:
Current references in the web interface and user's guide mention the FlexRadio 6000 series, but these need to be updated due to [FlexRadio's announcement of the 8400/8600](https://www.flexradio.com/products/flex-8000-deposit/?sku=FLEX-8000-Deposit-FL) at the 2024 Dayton Hamvention. No breaking changes to their API are expected in the new lineup.

Closed 2024-05-24.

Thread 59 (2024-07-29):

ezDV firmware build issues

FreeRepositories, 2024-07-29:
Hi,
Trying to build the firmware,  (commit 7ee14a9 v1.1.0)  but it looks it cannot be built.
Seen that in Releases there is a pre-built firmware, I wonder what is happening.
Are the repo sources checked out, up to date ?

Tried this many times, with the same error results.

New environment, Ubuntu 24.04, fresh esp-idf v 5.3

In a nutshell, what is executed is

**git clone https://github.com/tmiw/ezDV.git**
**cd ezDV**
**git submodule update --init --checkout --recursive**
**cd firmware**
**idf.py build**

 and then it stops with

```
/home/user/esp/projects/ezDV/firmware/main/network/HttpServerTask.cpp:612:28: error: 'using ezdv::network::HttpServerTask::WebSocketList = class std::map<int, bool>' {aka 'class std::map<int, bool>'} has no member named 'contains'
  612 |     if (!activeWebSockets_.contains(message->fd))
      |                            ^~~~~~~~
/home/user/esp/projects/ezDV/firmware/main/network/HttpServerTask.cpp: In member function 'void ezdv::network::HttpServerTask::onHttpWebsocketDisconnectedMessage_(ezdv::task::DVTask*, HttpWebsocketDisconnectedMessage*)':
/home/user/esp/projects/ezDV/firmware/main/network/HttpServerTask.cpp:840:27: error: 'using ezdv::network::HttpServerTask::WebSocketList = class std::map<int, bool>' {aka 'class std::map<int, bool>'} has no member named 'contains'
  840 |     if (activeWebSockets_.contains(message->fd))
      |                           ^~~~~~~~
```

Here is the complete output from the clone and build process

```
user@user-VMware-Virtual-Platform:~/esp/projects$ git clone https://github.com/tmiw/ezDV.git
Cloning into 'ezDV'...
remote: Enumerating objects: 7373, done.
remote: Counting objects: 100% (625/625), done.
remote: Compressing objects: 100% (279/279), done.
remote: Total 7373 (delta 473), reused 468 (delta 346), pack-reused 6748
Receiving objects: 100% (7373/7373), 104.54 MiB | 6.18 MiB/s, done.
Resolving deltas: 100% (5528/5528), done.
user@user-VMware-Virtual-Platform:~/esp/projects$ cd ezDV
user@user-VMware-Virtual-Platform:~/esp/projects/ezDV$ git submodule update --init --checkout --recursive
Submodule 'enclosure/library/YAPP_Box' (https://github.com/mrWheel/YAPP_Box.git) registered for path 'enclosure/library/YAPP_Box'
Submodule 'firmware/externals/esp-dsp' (https://github.com/espressif/esp-dsp.git) registered for path 'firmware/externals/esp-dsp'
Submodule 'firmware/externals/tinyuntar' (https://github.com/tmiw/TinyUntar.git) registered for path 'firmware/externals/tinyuntar'
Submodule 'firmware/externals/uzlib' (https://github.com/tmiw/uzlib) registered for path 'firmware/externals/uzlib'
Cloning into '/home/user/esp/projects/ezDV/enclosure/library/YAPP_Box'...
Cloning into '/home/user/esp/projects/ezDV/firmware/externals/esp-dsp'...
Cloning into '/home/user/esp/projects/ezDV/firmware/externals/tinyuntar'...
Cloning into '/home/user/esp/projects/ezDV/firmware/externals/uzlib'...
Submodule path 'enclosure/library/YAPP_Box': checked out 'b18e996388dff5b3ce523cec2b26665ccb7059d4'
Submodule path 'firmware/externals/esp-dsp': checked out '71514173b58b960173b40c4ade9d15d372770a74'
Submodule path 'firmware/externals/tinyuntar': checked out 'bda54b1c12141c74f259b4893186556a72c0d052'
Submodule path 'firmware/externals/uzlib': checked out '6ffe173438baa8a41bb96e5ab658e9c254a4bcac'
user@user-VMware-Virtual-Platform:~/esp/projects/ezDV$ cd firmware
user@user-VMware-Virtual-Platform:~/esp/projects/ezDV/firmware$ idf.py build
Executing action: all (aliases: build)
Running cmake in directory /home/user/esp/projects/ezDV/firmware/build
Executing "cmake -G Ninja -DPYTHON_DEPS_CHECKED=1 -DPYTHON=/home/user/.espressif/python_env/idf5.3_py3.12_env/bin/python -DESP_PLATFORM=1 -DCCACHE_ENABLE=0 /home/user/esp/projects/ezDV/firmware"...
-- IDF_TARGET is not set, guessed 'esp32s3' from sdkconfig '/home/user/esp/projects/ezDV/firmware/sdkconfig'
-- Found Git: /usr/bin/git (found version "2.43.0")
-- The C compiler identification is GNU 13.2.0
-- The CXX compiler identification is GNU 13.2.0
-- The ASM compiler identification is GNU
-- Found assembler: /home/user/.espressif/tools/xtensa-esp-elf/esp-13.2.0_20240530/xtensa-esp-elf/bin/xtensa-esp32s3-elf-gcc
-- Detecting C compiler ABI info
-- Detecting C compiler ABI info - done
-- Check for working C compiler: /home/user/.espressif/tools/xtensa-esp-elf/esp-13.2.0_20240530/xtensa-esp-elf/bin/xtensa-esp32s3-elf-gcc - skipped
-- Detecting C compile features
-- Detecting C compile features - done
-- Detecting CXX compiler ABI info
-- Detecting CXX compiler ABI info - done
-- Check for working CXX compiler: /home/user/.espressif/tools/xtensa-esp-elf/esp-13.2.0_20240530/xtensa-esp-elf/bin/xtensa-esp32s3-elf-g++ - skipped
-- Detecting CXX compile features
-- Detecting CXX compile features - done
-- Building ESP-IDF components for target esp32s3
Dependencies lock doesn't exist, solving dependencies.
......Updating lock file at /home/user/esp/projects/ezDV/firmware/dependencies.lock
Processing 3 dependencies:
[1/3] espressif/esp_websocket_client (1.2.3)
[2/3] espressif/libsodium (1.0.20~1)
[3/3] idf (5.3.0)
-- Project sdkconfig file /home/user/esp/projects/ezDV/firmware/sdkconfig
-- Compiler supported targets: xtensa-esp-elf
-- Found Python3: /home/user/.espressif/python_env/idf5.3_py3.12_env/bin/python (found version "3.12.3") found components: Interpreter
-- Performing Test CMAKE_HAVE_LIBC_PTHREAD
-- Performing Test CMAKE_HAVE_LIBC_PTHREAD - Success
-- Found Threads: TRUE
-- Performing Test C_COMPILER_SUPPORTS_WFORMAT_SIGNEDNESS
-- Performing Test C_COMPILER_SUPPORTS_WFORMAT_SIGNEDNESS - Success
-- App "ezdv" version: 1.1.0
-- Adding linker script /home/user/esp/projects/ezDV/firmware/build/esp-idf/esp_system/ld/memory.ld
-- Adding linker script /home/user/esp/projects/ezDV/firmware/build/esp-idf/esp_system/ld/sections.ld.in
-- Adding linker script /home/user/esp/esp-idf/components/esp_rom/esp32s3/ld/esp32s3.rom.ld
-- Adding linker script /home/user/esp/esp-idf/components/esp_rom/esp32s3/ld/esp32s3.rom.api.ld
-- Adding linker script /home/user/esp/esp-idf/components/esp_rom/esp32s3/ld/esp32s3.rom.libgcc.ld
-- Adding linker script /home/user/esp/esp-idf/components/esp_rom/esp32s3/ld/esp32s3.rom.wdt.ld
-- Adding linker script /home/user/esp/esp-idf/components/esp_rom/esp32s3/ld/esp32s3.rom.version.ld
-- Adding linker script /home/user/esp/esp-idf/components/esp_rom/esp32s3/ld/esp32s3.rom.newlib.ld
-- Adding linker script /home/user/esp/esp-idf/components/soc/esp32s3/ld/esp32s3.peripherals.ld
Setting up Codec2...
-- Performing Test COMPILER_SUPPORTS_GNU11
-- Performing Test COMPILER_SUPPORTS_GNU11 - Success
-- Performing Test COMPILER_SUPPORTS_GNU99
-- Performing Test COMPILER_SUPPORTS_GNU99 - Success
-- Looking for include file stdlib.h
-- Looking for include file stdlib.h - found
-- Looking for include file string.h
-- Looking for include file string.h - found
-- Looking for __GNU_LIBRARY__
-- Looking for __GNU_LIBRARY__ - not found
-- Looking for _GNU_SOURCE
-- Looking for _GNU_SOURCE - not found
-- Looking for floor
-- Looking for floor - not found
-- Looking for ceil
-- Looking for ceil - not found
-- Looking for pow
-- Looking for pow - not found
-- Looking for sqrt
-- Looking for sqrt - not found
-- Looking for sin
-- Looking for sin - not found
-- Looking for cos
-- Looking for cos - not found
-- Looking for atan2
-- Looking for atan2 - not found
-- Looking for log10
-- Looking for log10 - not found
-- Looking for round
-- Looking for round - not found
-- Looking for getopt
-- Looking for getopt - found
-- codec2 version: 1.2.0
-- Build type is: Debug
-- Compiler Flags: -mlongcalls  -fno-builtin-memcpy -fno-builtin-memset -fno-builtin-bzero -fno-builtin-stpcpy -fno-builtin-strncpy -Wall -Wno-strict-overflow -std=gnu11-g -O2 -DDUMP
-- Libraries linked:
-- Compilation date = XX2024-07-29XX
-- Adding linker script /home/user/esp/projects/ezDV/firmware/build/esp-idf/main/ulp_main/ulp_main.ld
-- Components: app_trace app_update bootloader bootloader_support bt cmock console cxx driver efuse esp-dsp esp-tls esp_adc esp_app_format esp_bootloader_format esp_coex esp_common esp_driver_ana_cmpr esp_driver_cam esp_driver_dac esp_driver_gpio esp_driver_gptimer esp_driver_i2c esp_driver_i2s esp_driver_isp esp_driver_jpeg esp_driver_ledc esp_driver_mcpwm esp_driver_parlio esp_driver_pcnt esp_driver_ppa esp_driver_rmt esp_driver_sdio esp_driver_sdm esp_driver_sdmmc esp_driver_sdspi esp_driver_spi esp_driver_tsens esp_driver_uart esp_driver_usb_serial_jtag esp_eth esp_event esp_gdbstub esp_hid esp_http_client esp_http_server esp_https_ota esp_https_server esp_hw_support esp_lcd esp_local_ctrl esp_mm esp_netif esp_netif_stack esp_partition esp_phy esp_pm esp_psram esp_ringbuf esp_rom esp_system esp_timer esp_vfs_console esp_wifi espcoredump espressif__esp_websocket_client espressif__libsodium esptool_py fatfs freertos hal heap http_parser idf_test ieee802154 json log lwip main mbedtls mqtt newlib nvs_flash nvs_sec_provider openthread partition_table perfmon protobuf-c protocomm pthread sdmmc soc spi_flash spiffs tcp_transport touch_element ulp unity usb vfs wear_levelling wifi_provisioning wpa_supplicant xtensa
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

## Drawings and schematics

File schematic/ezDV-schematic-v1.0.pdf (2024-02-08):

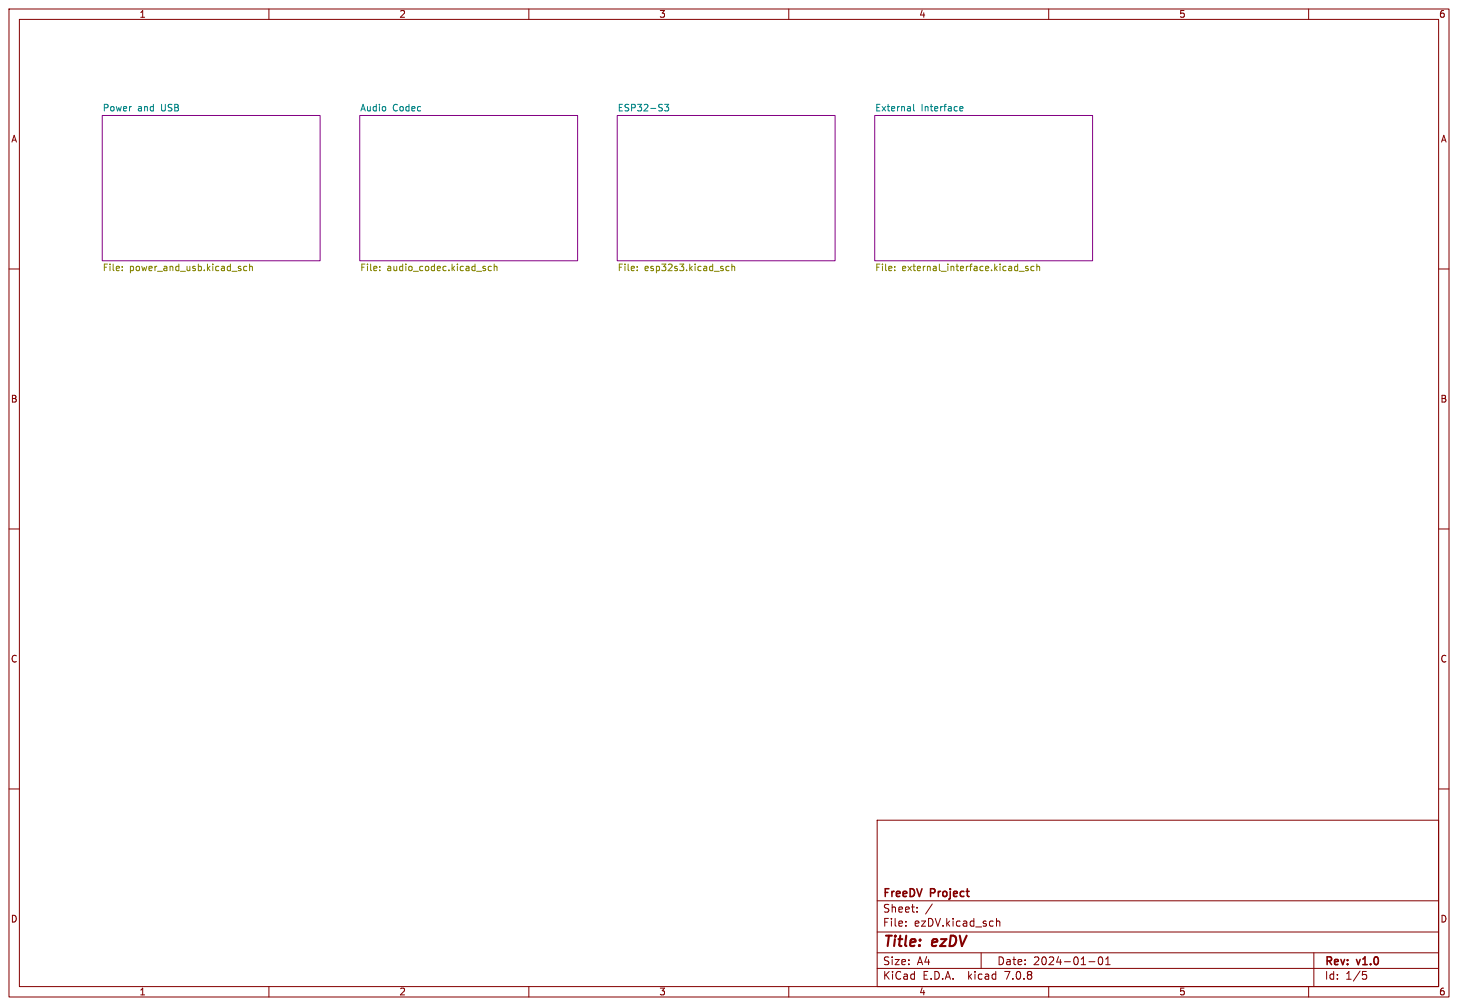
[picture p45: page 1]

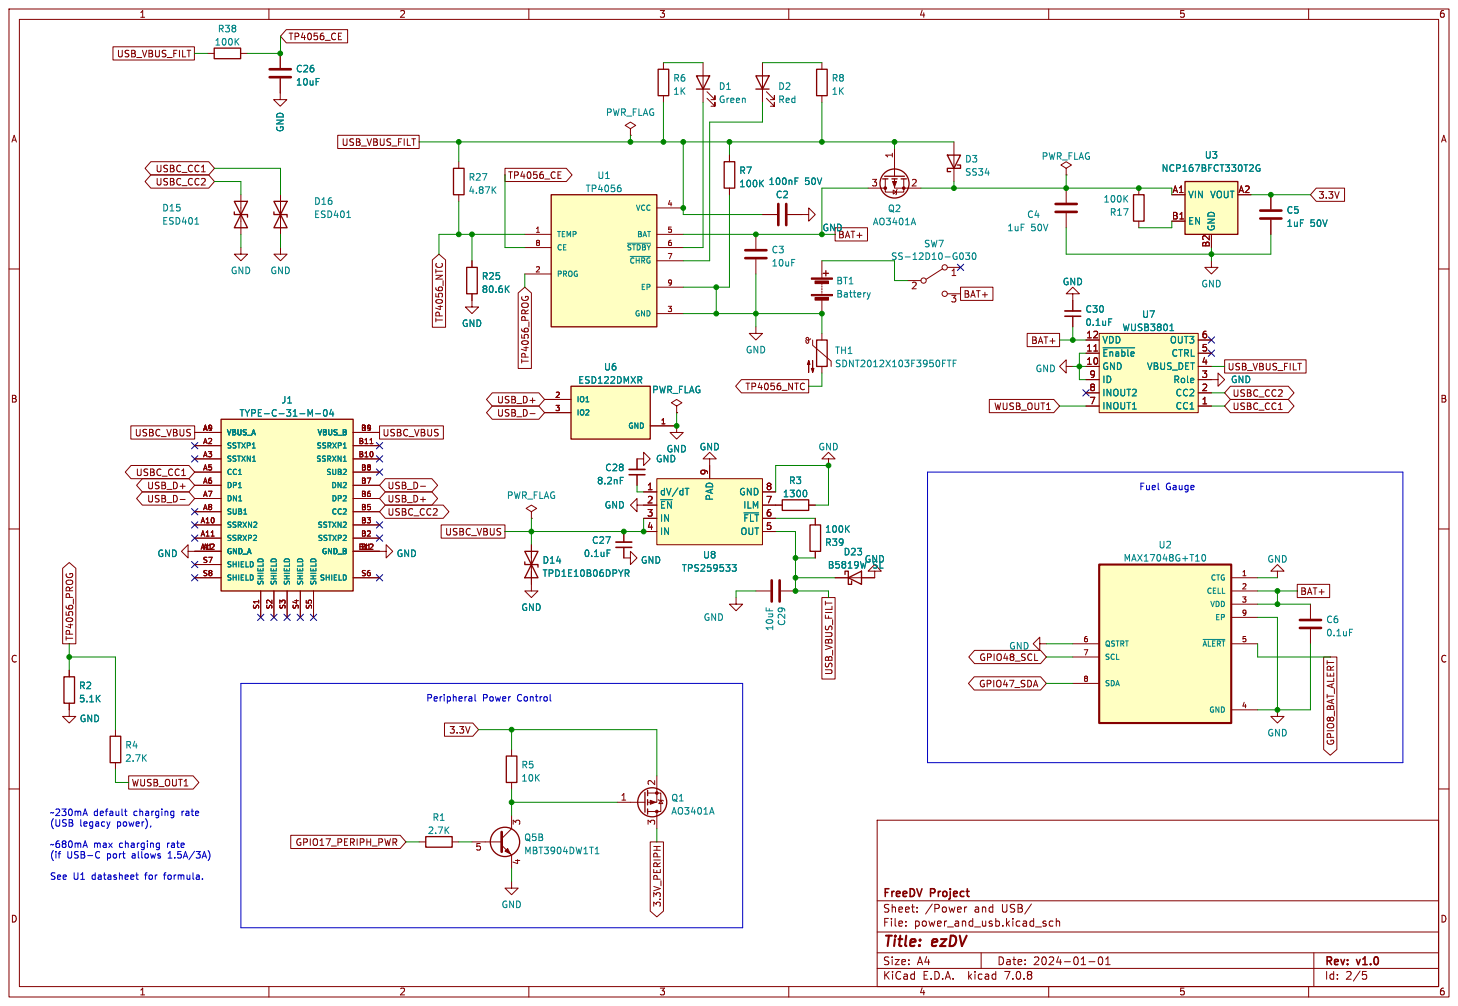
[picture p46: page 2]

9 U8 TPS259533 GND GND GND GND

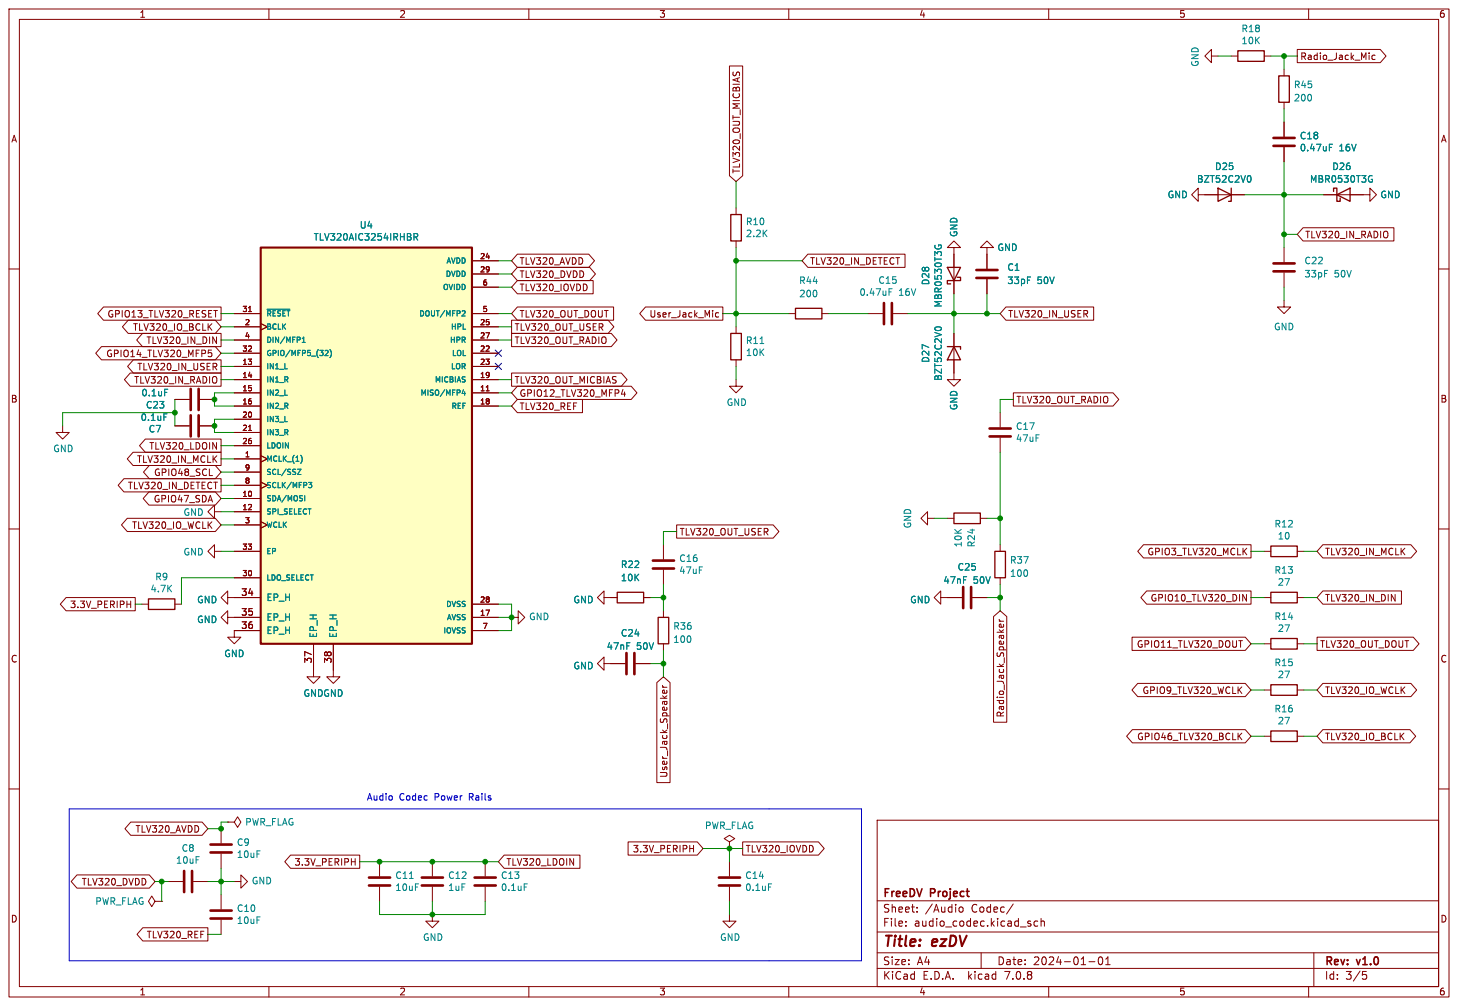
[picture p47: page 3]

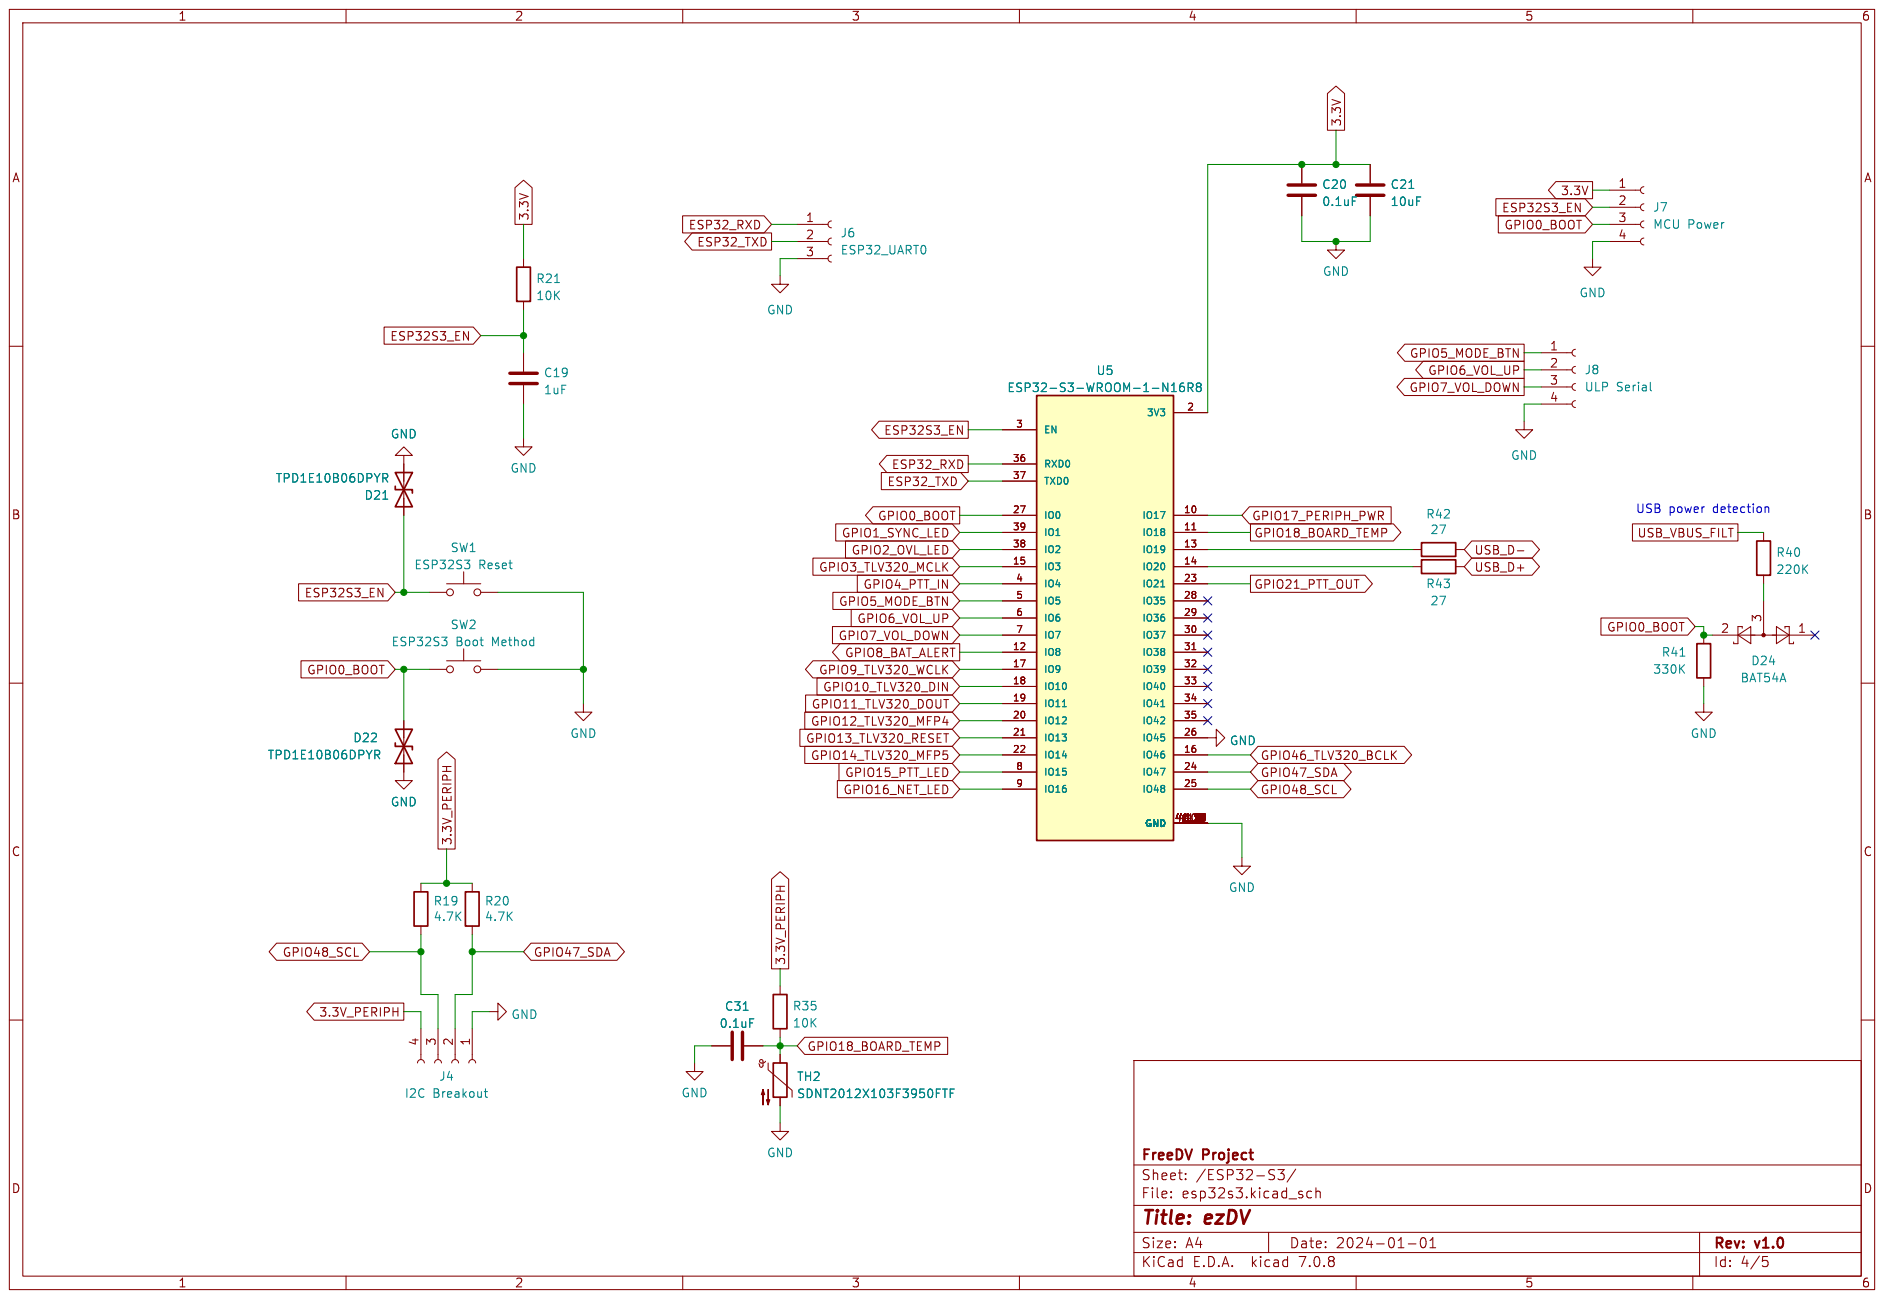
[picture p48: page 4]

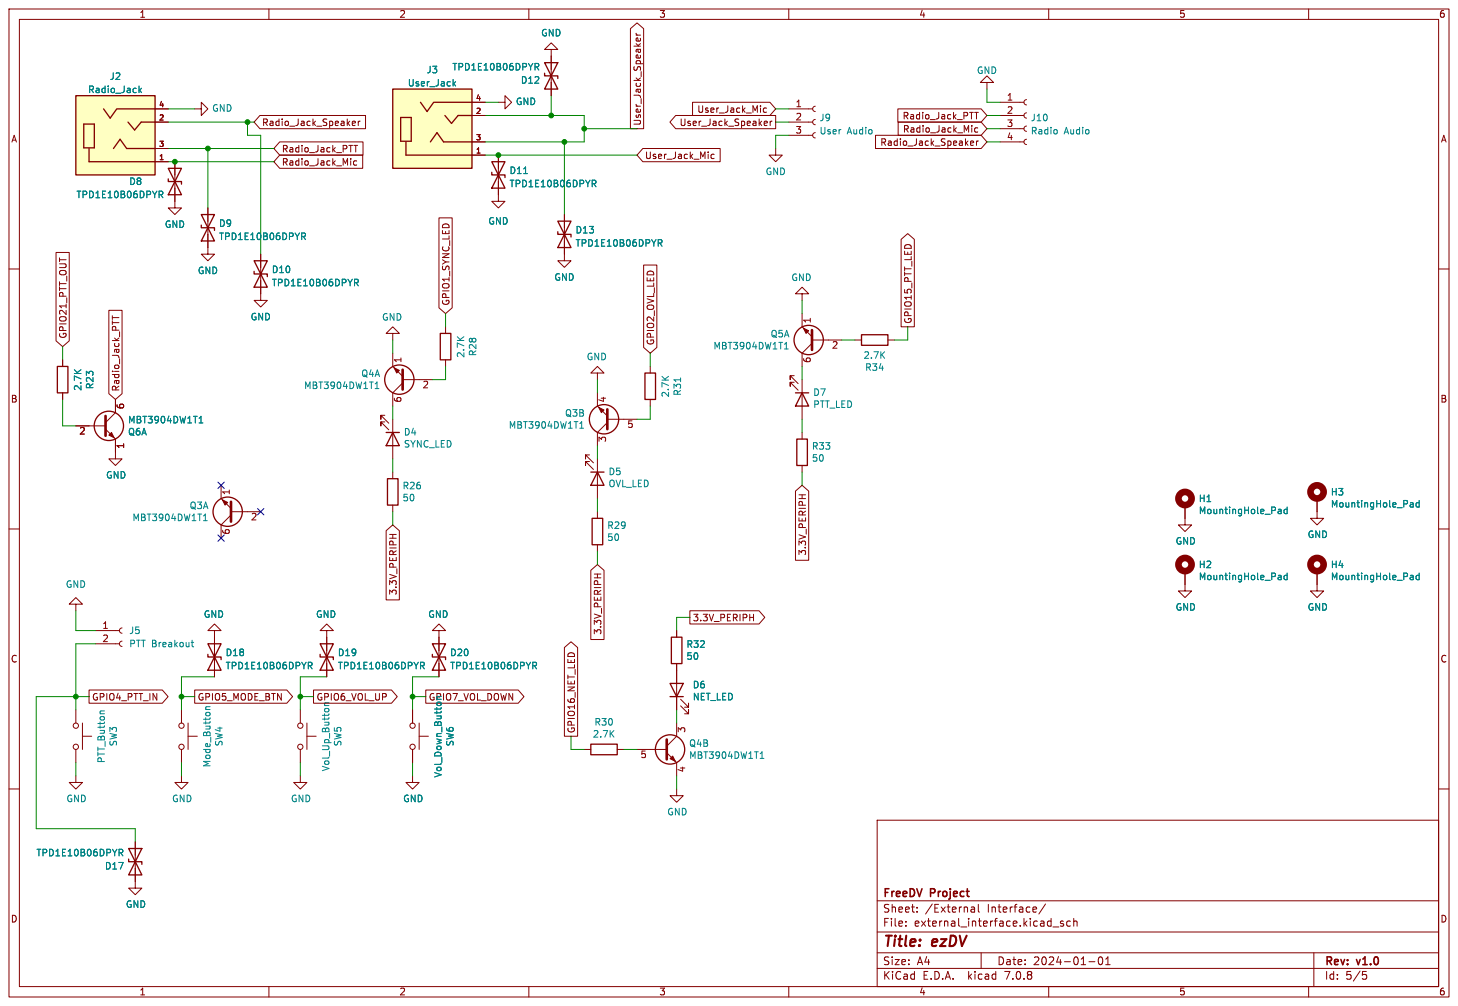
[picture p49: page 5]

J10 Radio Audio GND GND

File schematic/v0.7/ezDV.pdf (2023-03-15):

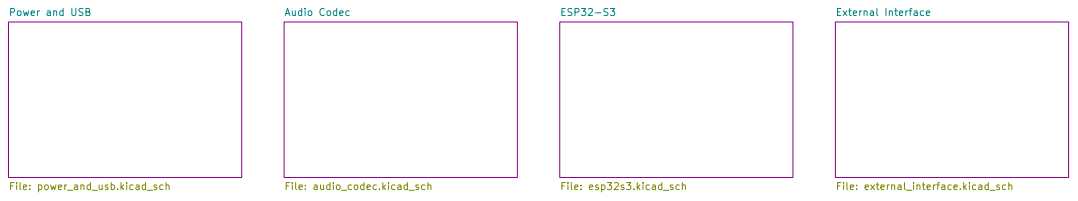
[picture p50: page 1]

File: ezDV.kicad_sch Sheet: / FreeDV Project

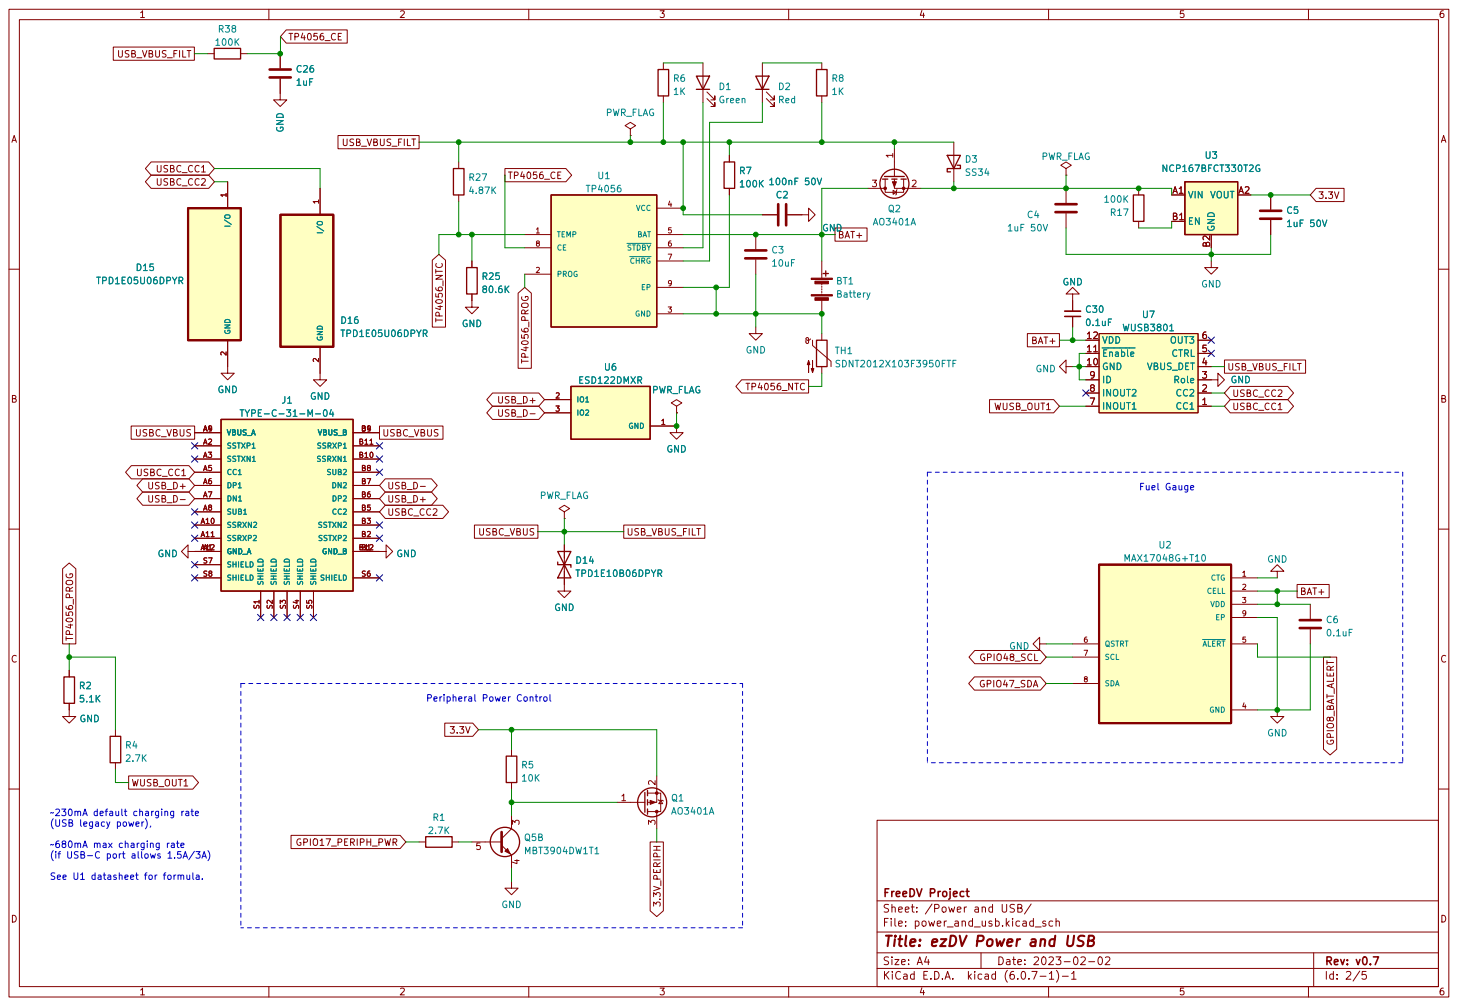
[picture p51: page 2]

File: power_and_usb.kicad_sch Sheet: /Power and USB/ FreeDV Project

Id: 2/5 Title: ezDV Power and USB

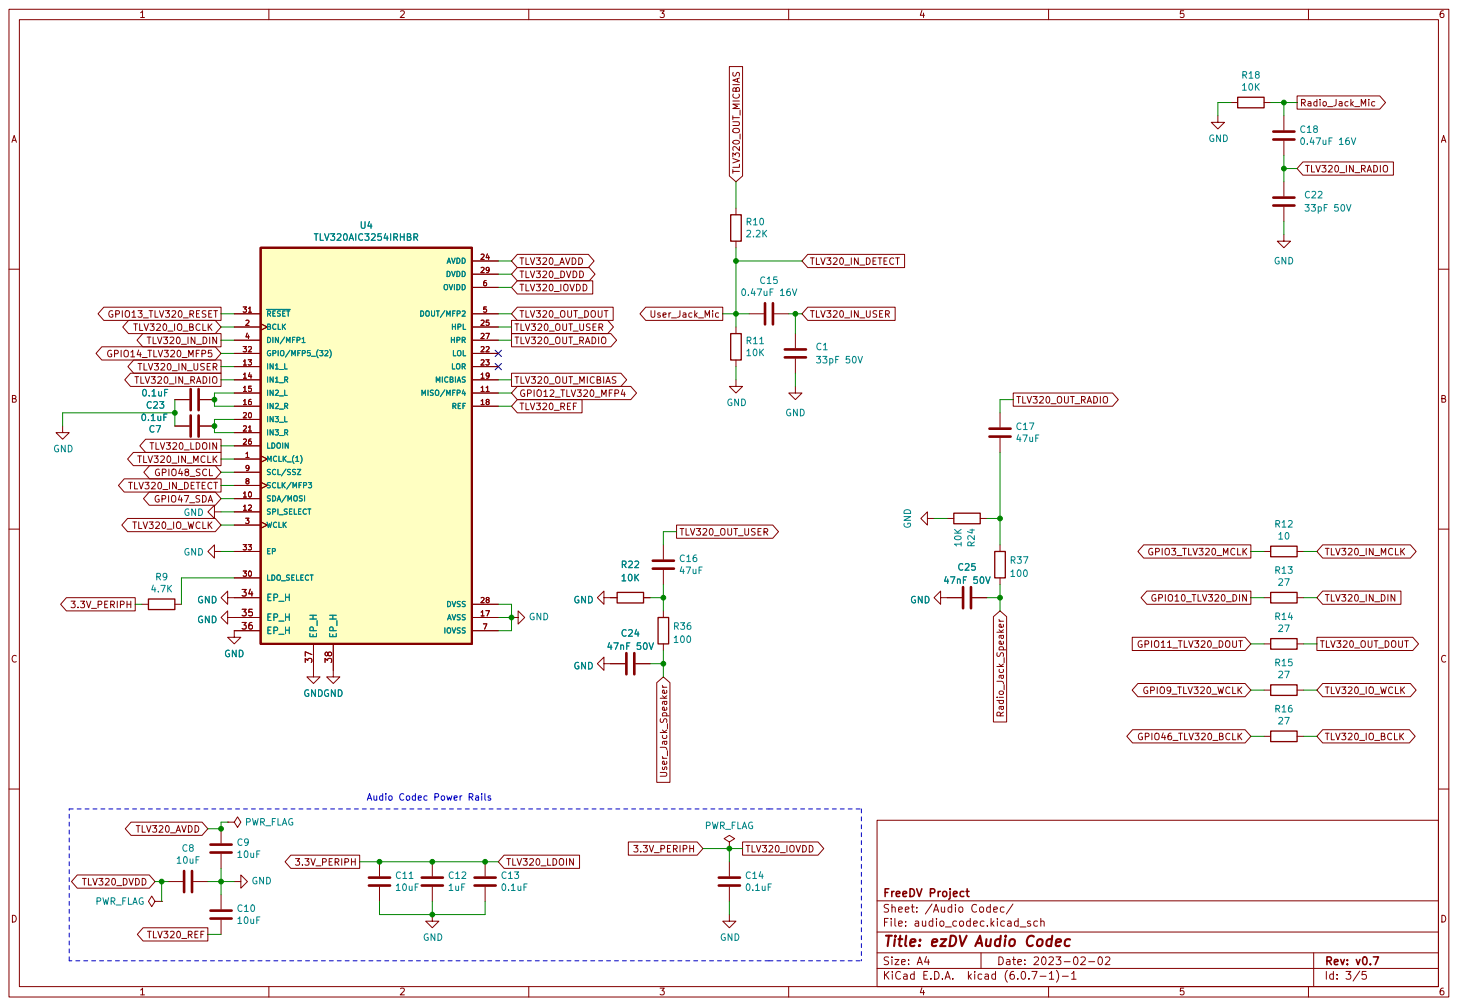
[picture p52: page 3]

Audio Codec Power Rails C7

File: audio_codec.kicad_sch Sheet: /Audio Codec/ FreeDV Project

Id: 3/5 Title: ezDV Audio Codec

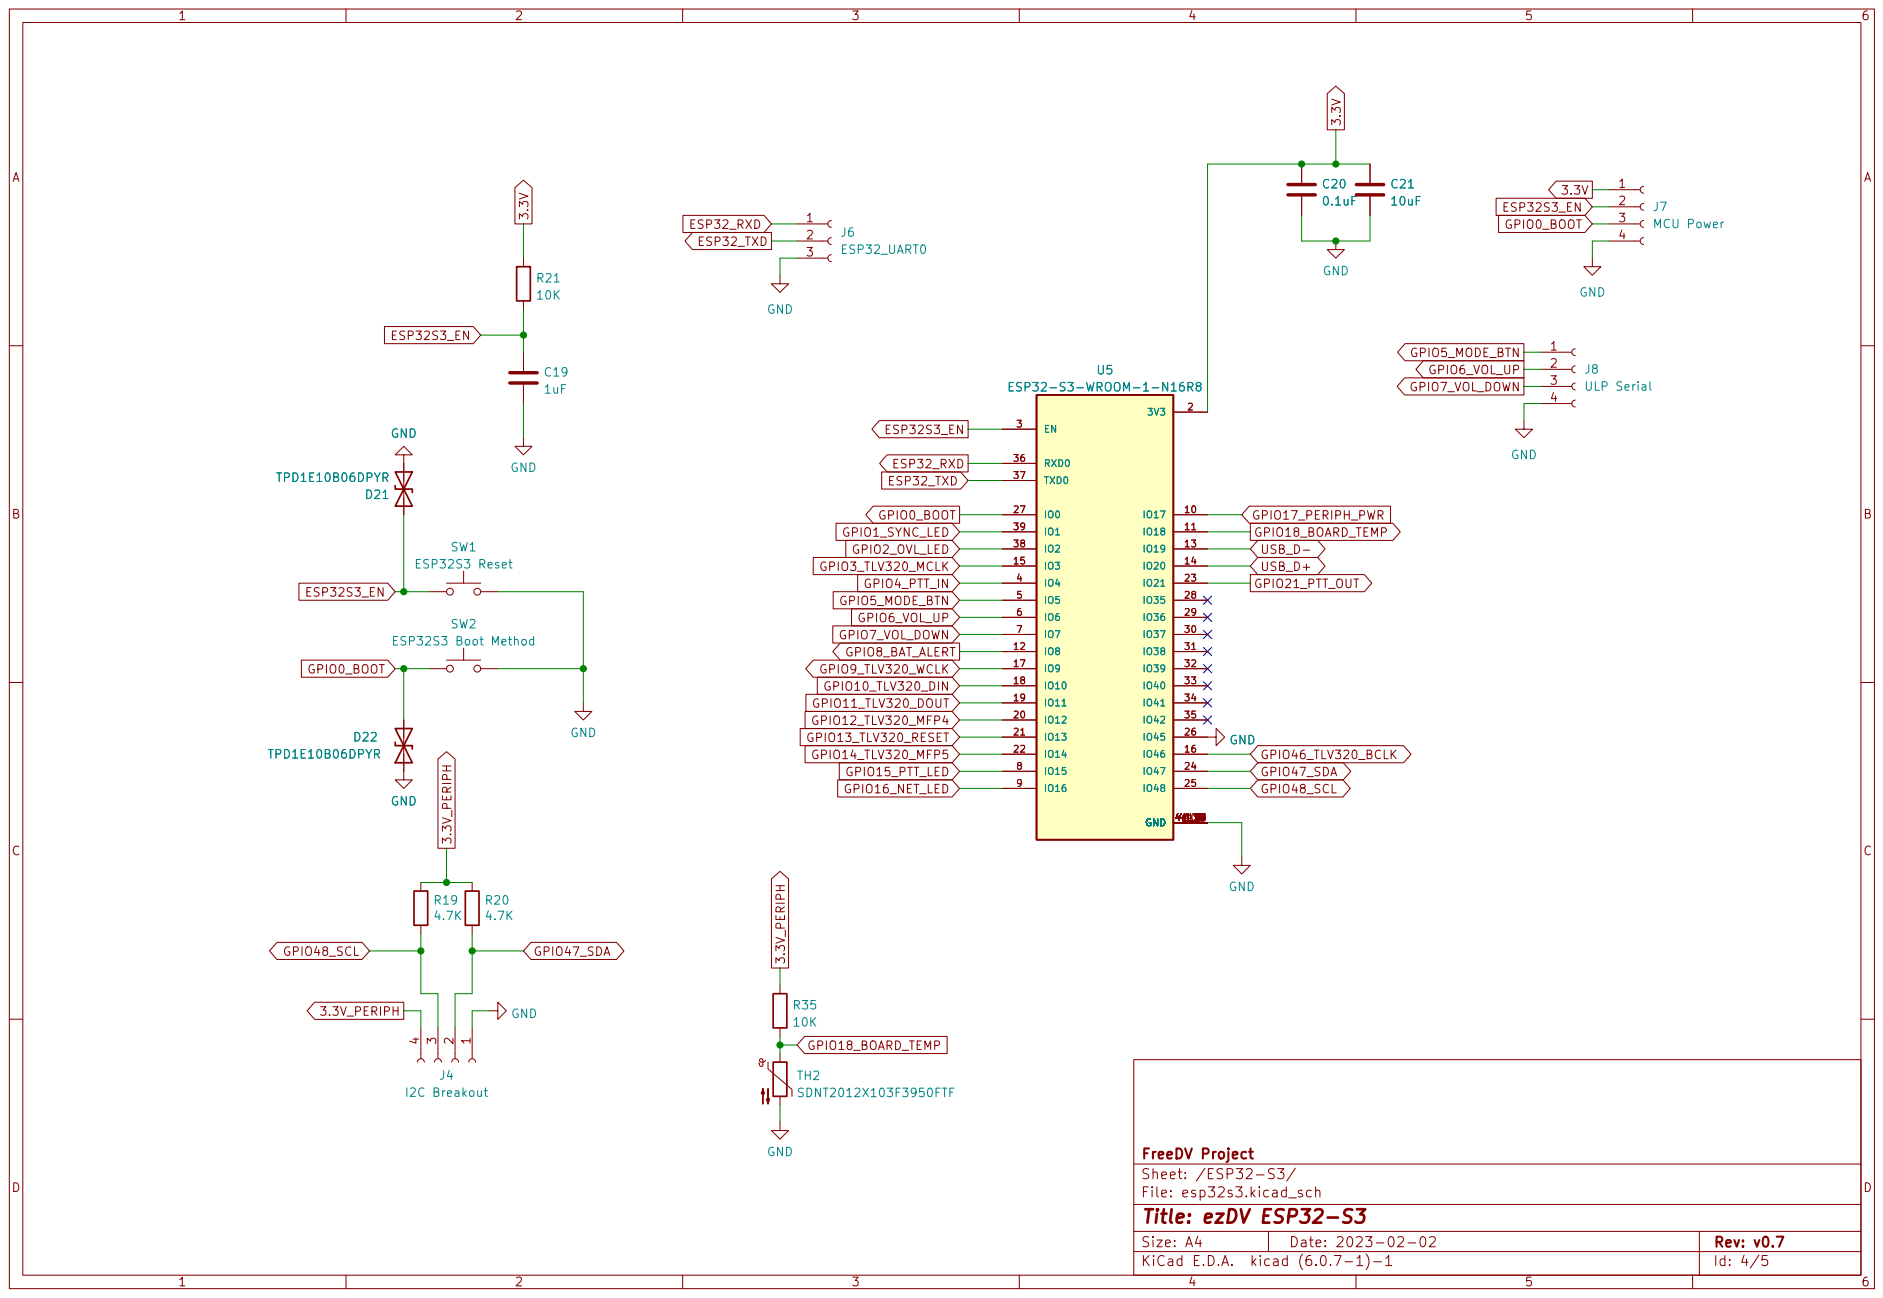
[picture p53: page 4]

SW1 ESP32S3 Reset SW2 ESP32S3 Boot Method D22 TPD1E10B06DPYR GND

File: esp32s3.kicad_sch Sheet: /ESP32-S3/ FreeDV Project 4

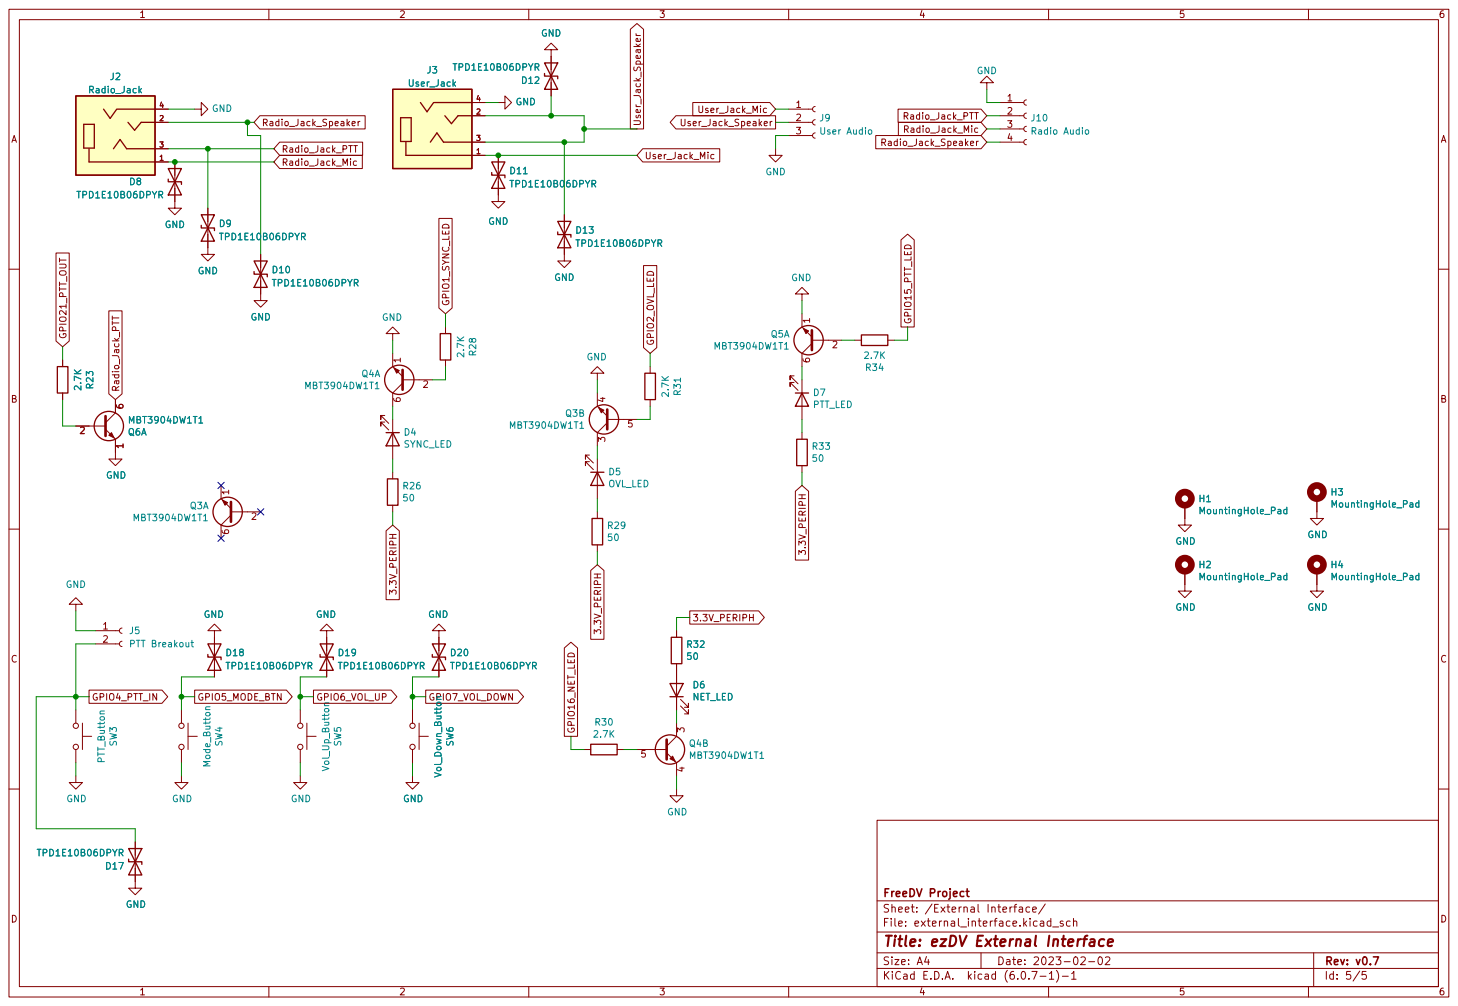
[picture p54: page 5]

6 Q3A MBT3904DW1T1 D18 TPD1E10B06DPYR GND GND GND SW3 PTT_Button GND

File: external_interface.kicad_sch Sheet: /External Interface/ FreeDV Project GND

Id: 5/5 Title: ezDV External Interface

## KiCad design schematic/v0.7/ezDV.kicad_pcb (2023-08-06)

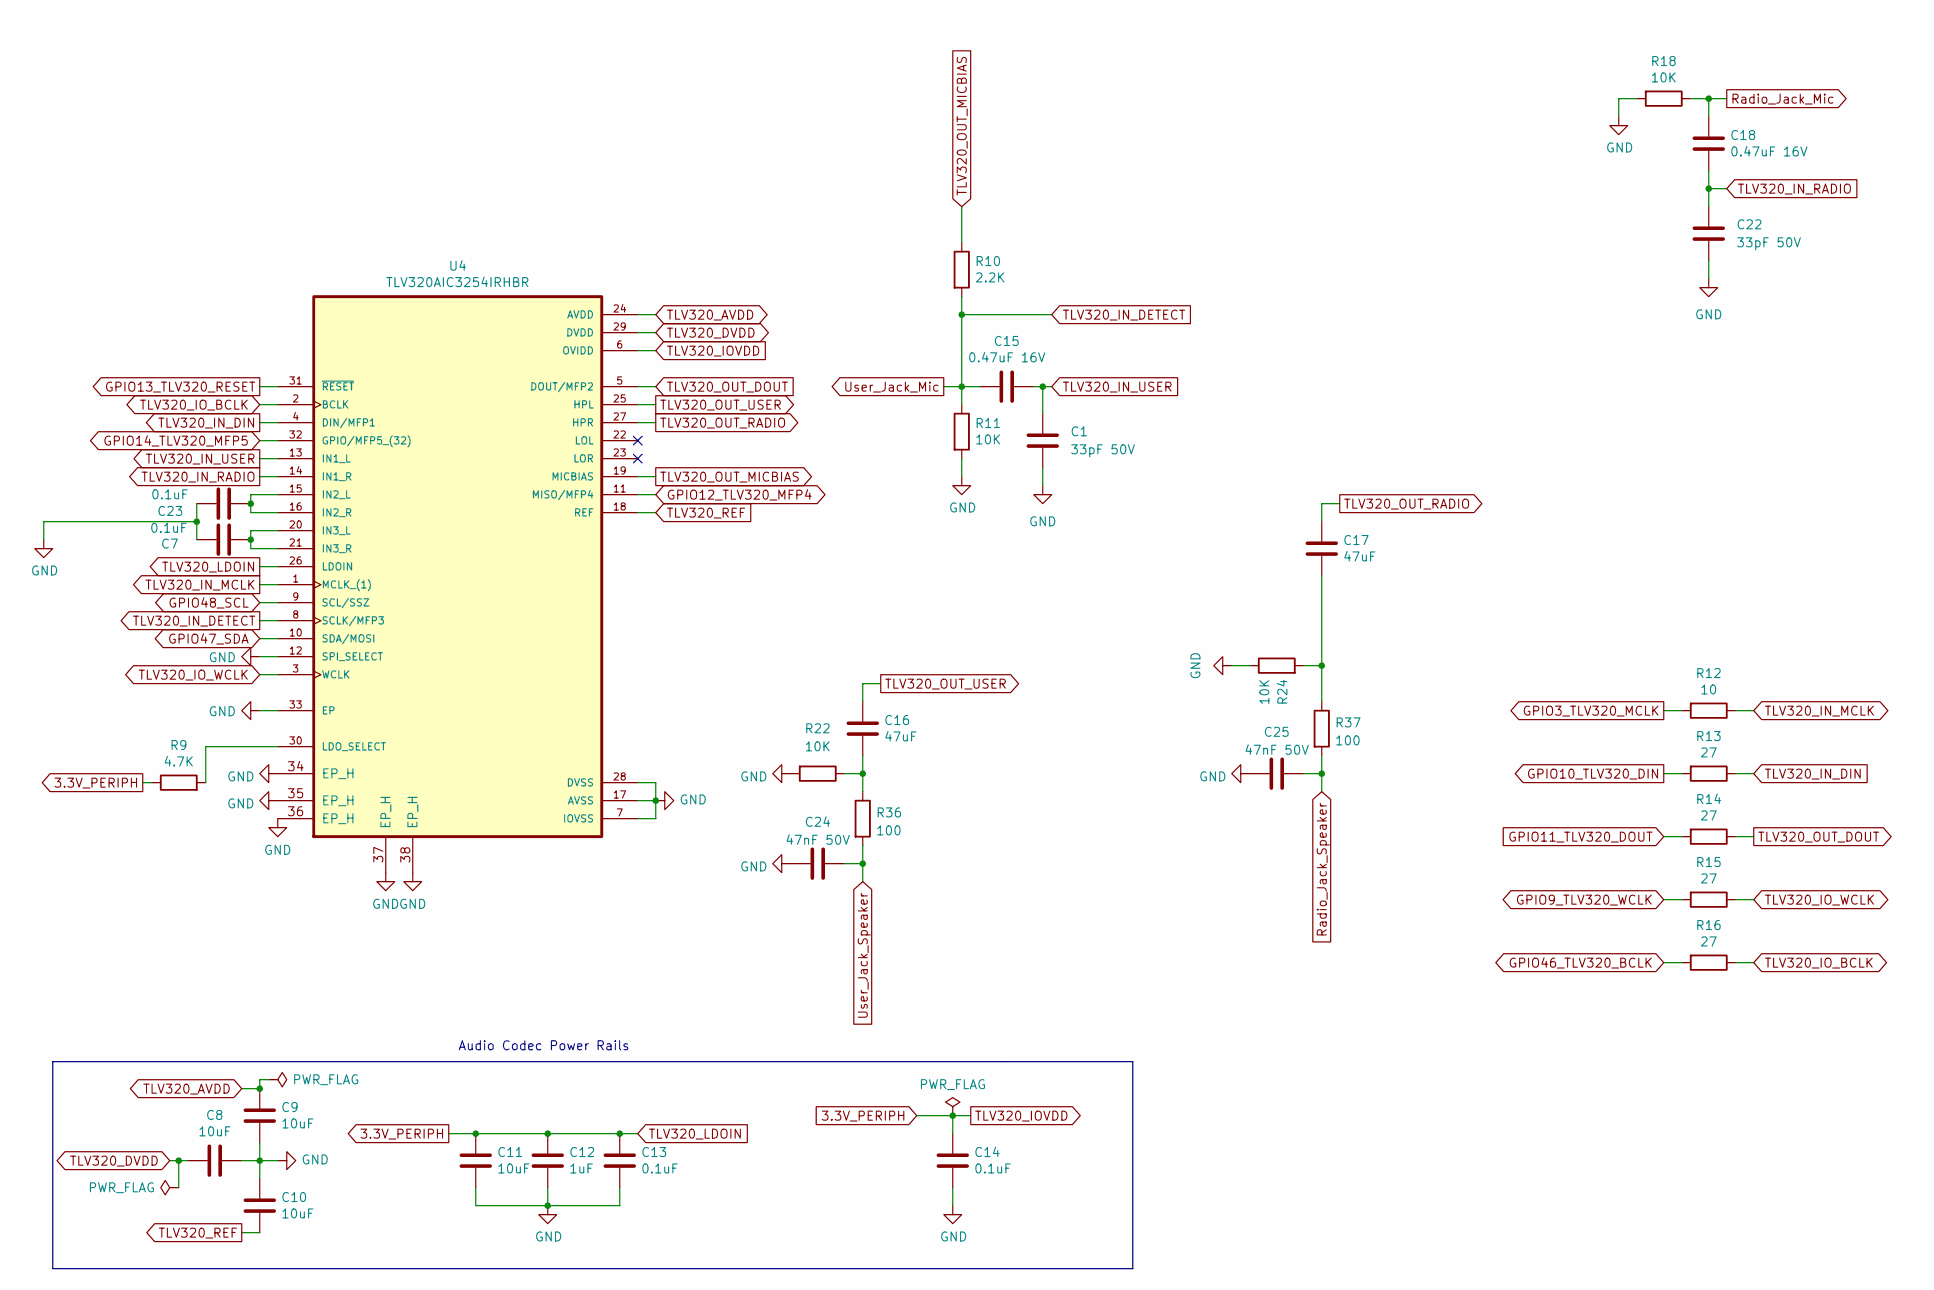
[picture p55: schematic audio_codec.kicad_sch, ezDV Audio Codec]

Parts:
C1, C22: 33pF 50V; C_0402_1005Metric; LCSC C1562
C7, C13, C14, C23: 0.1uF; C_0402_1005Metric; LCSC C1525
C8, C9, C10, C11: 10uF; C_0402_1005Metric; LCSC C315248
C12: 1uF; C_0402_1005Metric; LCSC C14445
C15, C18: 0.47uF 16V; C_0402_1005Metric; LCSC C575468
C16, C17: 47uF; C_0603_1608Metric; LCSC C140782
C24, C25: 47nF 50V; C_0402_1005Metric; LCSC C697422
R9: 4.7K; R_0402_1005Metric; LCSC C25900
R10: 2.2K; R_0402_1005Metric; LCSC C114762
R11, R18, R22, R24: 10K; R_0402_1005Metric; LCSC C25744
R12: 10; R_0402_1005Metric; LCSC C25077
R13, R14, R15, R16: 27; R_0402_1005Metric; LCSC C31439
R36, R37: 100; R_0402_1005Metric; LCSC C25076
U4: TLV320AIC3254IRHBR; IC_ADS125H01IRHBT; LCSC C9925

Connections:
3.3V_PERIPH: C11.1, C12.1, C13.1, C14.1, R9.1, U4.6 (OVIDD), U4.26 (LDOIN); also elsewhere on the board
GND: C1.2, C7.2, C8.1, C9.2, C10.1, C11.2, C12.2, C13.2, C14.2, C22.2, C23.2, C24.1, C25.1, R11.2, R18.2, R22.2, R24.1, U4.7 (IOVSS), U4.12 (SPI_SELECT), U4.17 (AVSS), U4.28 (DVSS), U4.33 (EP), U4.34 (EP_H), U4.35 (EP_H), U4.36 (EP_H), U4.37 (EP_H), U4.38 (EP_H); also elsewhere on the board
GPIO3_TLV320_MCLK: R12.2; also elsewhere on the board
GPIO9_TLV320_WCLK: R15.2; also elsewhere on the board
GPIO10_TLV320_DIN: R13.2; also elsewhere on the board
GPIO11_TLV320_DOUT: R14.2; also elsewhere on the board
GPIO12_TLV320_MFP4: U4.11 (MISO/MFP4); also elsewhere on the board
GPIO13_TLV320_RESET: U4.31 (~RESET); also elsewhere on the board
GPIO14_TLV320_MFP5: U4.32 (GPIO/MFP5_(32)); also elsewhere on the board
GPIO46_TLV320_BCLK: R16.2; also elsewhere on the board
GPIO47_SDA: U4.10 (SDA/MOSI); also elsewhere on the board
GPIO48_SCL: U4.9 (SCL/SSZ); also elsewhere on the board
unnamed: C7.1, U4.15 (IN2_L), U4.16 (IN2_R)
unnamed: C16.2, R22.1, R36.1
unnamed: C17.2, R24.2, R37.1
unnamed: C23.1, U4.20 (IN3_L), U4.21 (IN3_R)
unnamed: R9.2, U4.30 (LDO_SELECT)
Radio_Jack_Mic: C18.1, R18.1; also elsewhere on the board
Radio_Jack_Speaker: C25.2, R37.2; also elsewhere on the board
TLV320_AVDD: C9.1, U4.24 (AVDD)
TLV320_DVDD: C8.2, U4.29 (DVDD)
TLV320_IN_DETECT: C15.1, R10.2, R11.1, U4.8 (SCLK/MFP3); also elsewhere on the board
TLV320_IN_DIN: R13.1, U4.4 (DIN/MFP1)
TLV320_IN_MCLK: R12.1, U4.1 (MCLK_(1))
TLV320_IN_RADIO: C18.2, C22.1, U4.14 (IN1_R)
TLV320_IN_USER: C1.1, C15.2, U4.13 (IN1_L)
TLV320_IO_BCLK: R16.1, U4.2 (BCLK)
TLV320_IO_WCLK: R15.1, U4.3 (WCLK)
TLV320_OUT_DOUT: R14.1, U4.5 (DOUT/MFP2)
TLV320_OUT_MICBIAS: R10.1, U4.19 (MICBIAS)
TLV320_OUT_RADIO: C17.1, U4.27 (HPR)
TLV320_OUT_USER: C16.1, U4.25 (HPL)
TLV320_REF: C10.2, U4.18 (REF)
User_Jack_Speaker: C24.2, R36.2; also elsewhere on the board

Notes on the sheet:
Audio Codec Power Rails

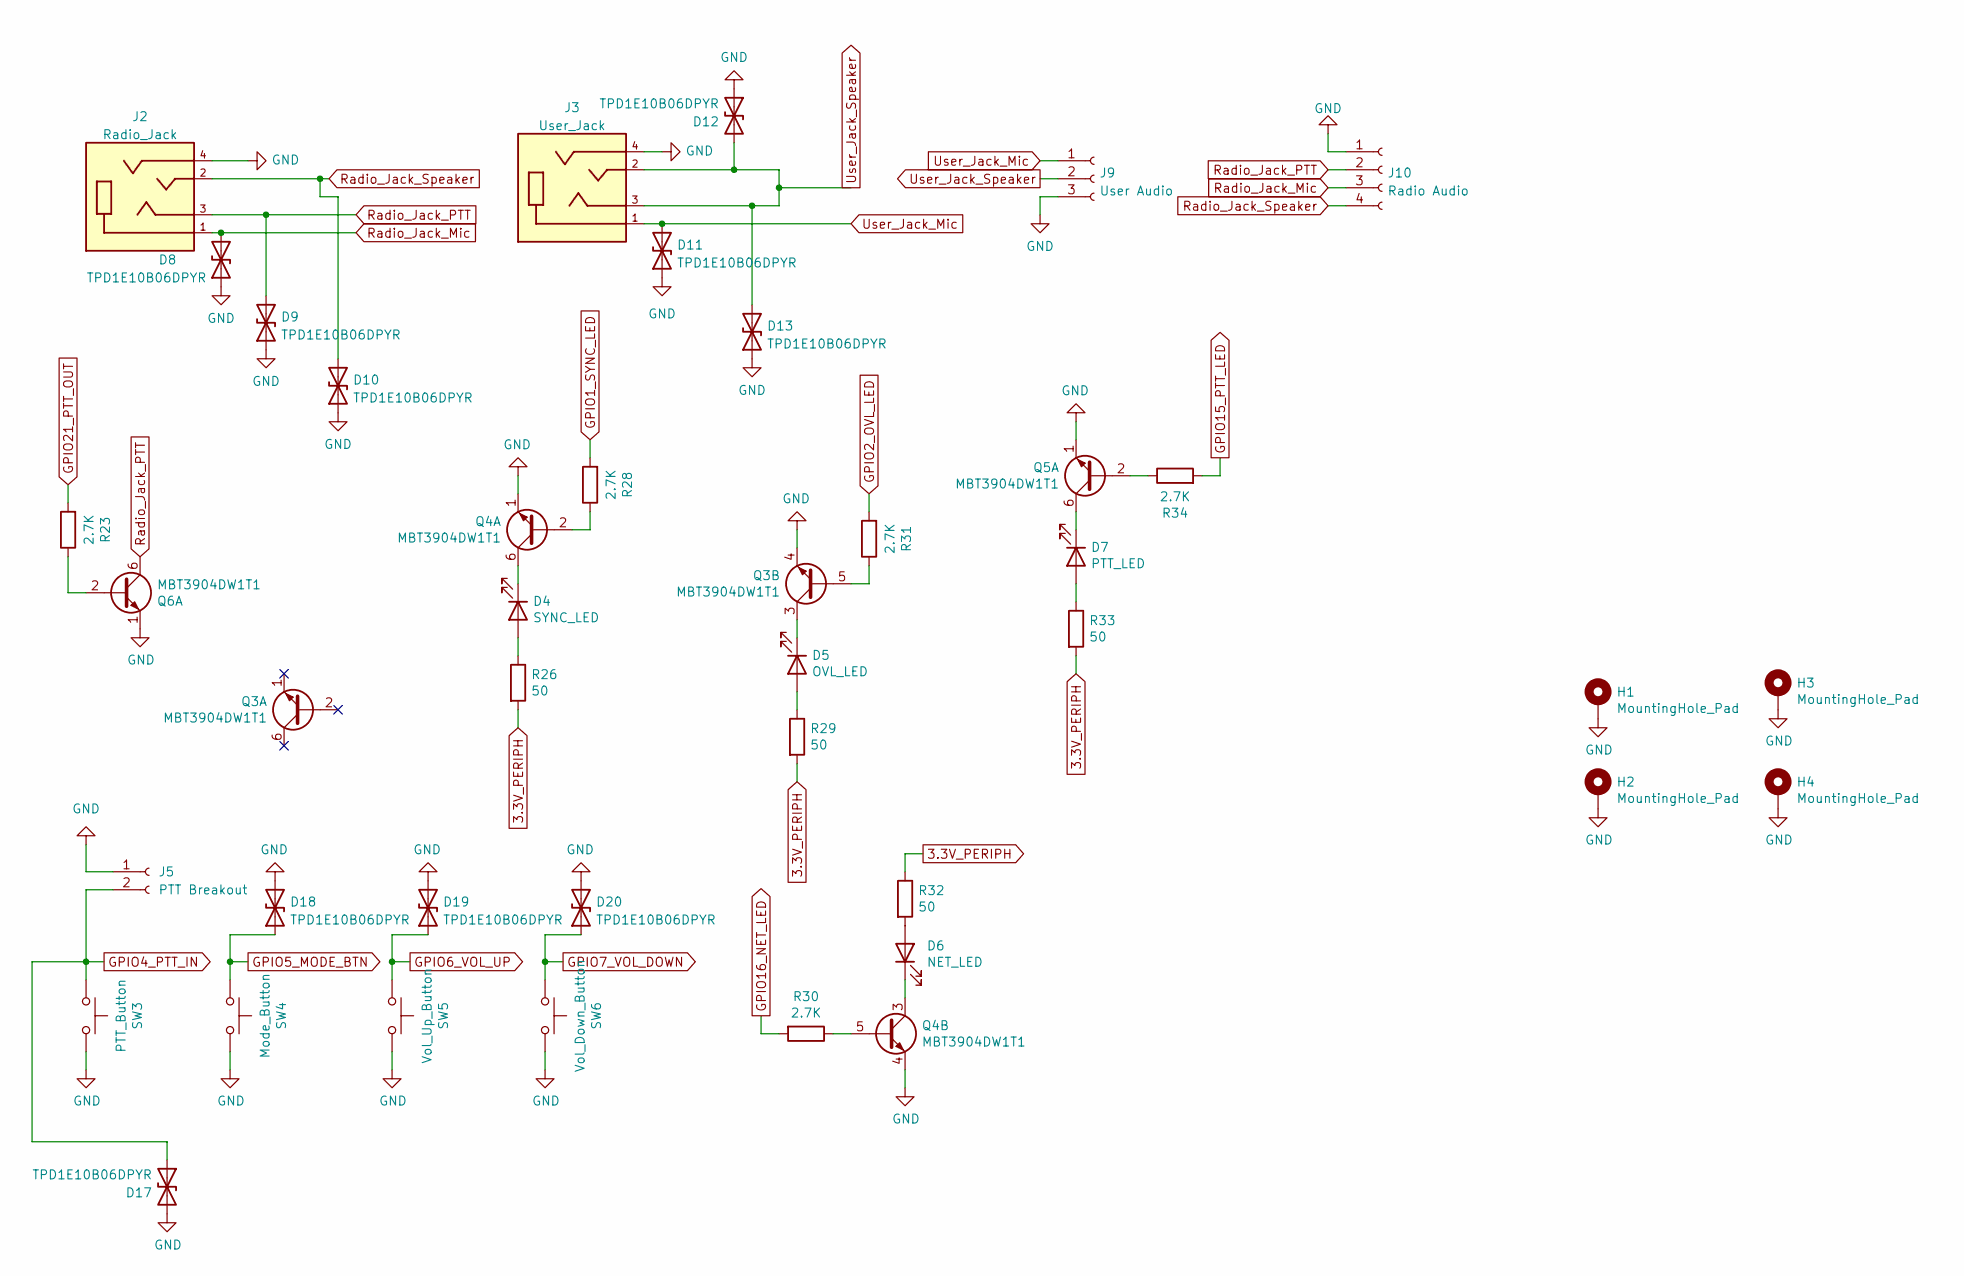
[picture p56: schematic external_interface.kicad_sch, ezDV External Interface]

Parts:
D4: SYNC_LED; D_0603_1608Metric; LCSC C434423
D5: OVL_LED; D_0603_1608Metric; LCSC C2286
D6: NET_LED; D_0603_1608Metric; LCSC C72041
D7: PTT_LED; D_0603_1608Metric; LCSC C2286
D8, D9, D10, D11, D12, D13, D17, D18, D19, D20: TPD1E10B06DPYR; DIO_TPD1E05U06DPYR; LCSC C48260
H1, H2, H3, H4: MountingHole_Pad; MountingHole_3.2mm_M3_Pad
J2: Radio_Jack; CUI_SJ-43514; PART_REV 1.04
J3: User_Jack; CUI_SJ-43514; PART_REV 1.04
J5: PTT Breakout; PinHeader_1x02_P2.54mm_Vertical
J9: User Audio; PinSocket_1x03_P2.54mm_Vertical
J10: Radio Audio; PinHeader_1x04_P2.54mm_Vertical
Q3, Q4, Q5, Q6: MBT3904DW1T1; SOT-363_SC-70-6; LCSC C110150
R23, R28, R30, R31, R34: 2.7K; R_0603_1608Metric; LCSC C13167
R26, R29, R32, R33: 50; R_0603_1608Metric; LCSC C22808
SW3: PTT_Button; SW_SPST_TL3305C; LCSC C2886904
SW4: Mode_Button; SW_SPST_TL3305C; LCSC C2886904
SW5: Vol_Up_Button; SW_SPST_TL3305C; LCSC C2886904
SW6: Vol_Down_Button; SW_SPST_TL3305C; LCSC C2886904

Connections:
3.3V_PERIPH: R26.2, R29.2, R32.1, R33.2; also elsewhere on the board
GND: D8.1 (A1), D9.1 (A1), D10.1 (A1), D11.1 (A1), D12.1 (A1), D13.1 (A1), D17.2 (A2), D18.2 (A2), D19.2 (A2), D20.2 (A2), H1.1, H2.1, H3.1, H4.1, J2.4, J3.4, J5.1, J9.3, J10.1, Q3.4 (E2), Q4.1 (E1), Q4.4 (E2), Q5.1 (E1), Q6.1 (E1), SW3.2, SW4.2, SW5.2, SW6.2; also elsewhere on the board
GPIO1_SYNC_LED: R28.2; also elsewhere on the board
GPIO2_OVL_LED: R31.2; also elsewhere on the board
GPIO4_PTT_IN: D17.1 (A1), J5.2, SW3.1; also elsewhere on the board
GPIO5_MODE_BTN: D18.1 (A1), SW4.1; also elsewhere on the board
GPIO6_VOL_UP: D19.1 (A1), SW5.1; also elsewhere on the board
GPIO7_VOL_DOWN: D20.1 (A1), SW6.1; also elsewhere on the board
GPIO15_PTT_LED: R34.2; also elsewhere on the board
GPIO16_NET_LED: R30.2; also elsewhere on the board
GPIO21_PTT_OUT: R23.2; also elsewhere on the board
unnamed: D4.1 (K), Q4.6 (C1)
unnamed: D4.2 (A), R26.1
unnamed: D5.1 (K), Q3.3 (C2)
unnamed: D5.2 (A), R29.1
unnamed: D6.1 (K), Q4.3 (C2)
unnamed: D6.2 (A), R32.2
unnamed: D7.1 (K), Q5.6 (C1)
unnamed: D7.2 (A), R33.1
unnamed: Q3.5 (B2), R31.1
unnamed: Q4.2 (B1), R28.1
unnamed: Q4.5 (B2), R30.1
unnamed: Q5.2 (B1), R34.1
unnamed: Q6.2 (B1), R23.1
Radio_Jack_Mic: D8.2 (A2), J2.1, J10.3; also elsewhere on the board
Radio_Jack_PTT: D9.2 (A2), J2.3, J10.2, Q6.6 (C1)
Radio_Jack_Speaker: D10.2 (A2), J2.2, J10.4; also elsewhere on the board
TLV320_IN_DETECT: D11.2 (A2), J3.1, J9.1; also elsewhere on the board
User_Jack_Speaker: D12.2 (A2), D13.2 (A2), J3.2, J3.3, J9.2; also elsewhere on the board

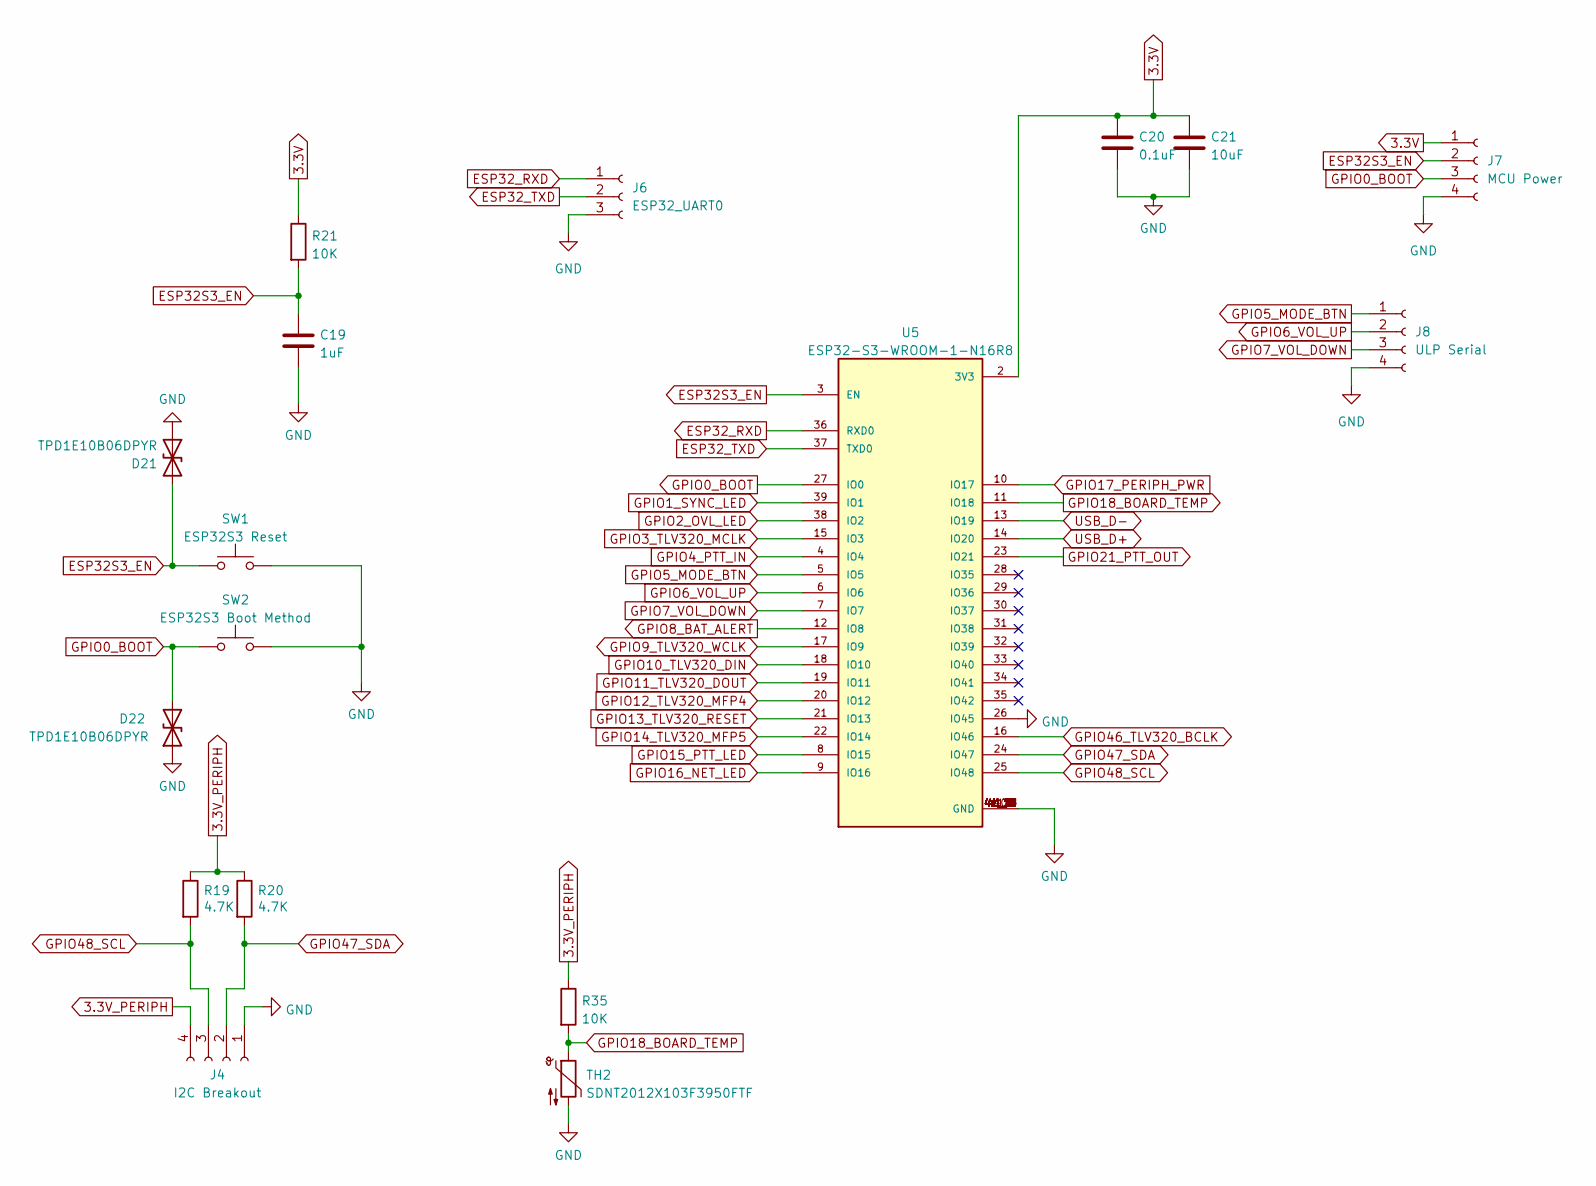
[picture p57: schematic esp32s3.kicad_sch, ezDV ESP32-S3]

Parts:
C19: 1uF; C_0402_1005Metric; LCSC C14445
C20: 0.1uF; C_0402_1005Metric; LCSC C1525
C21: 10uF; C_0402_1005Metric; LCSC C315248
D21, D22: TPD1E10B06DPYR; DIO_TPD1E05U06DPYR; LCSC C48260
J4: I2C Breakout; PinHeader_1x04_P2.54mm_Vertical
J6: ESP32_UART0; PinHeader_1x03_P2.54mm_Vertical
J7: MCU Power; PinHeader_1x04_P2.54mm_Vertical
J8: ULP Serial; PinHeader_2x02_P2.54mm_Vertical
R19, R20: 4.7K; R_0603_1608Metric; LCSC C99782
R21, R35: 10K; R_0402_1005Metric; LCSC C25744
SW1: ESP32S3 Reset; SW_SPST_TL3342; LCSC C2886898
SW2: ESP32S3 Boot Method; SW_SPST_TL3342; LCSC C2886898
TH2: SDNT2012X103F3950FTF; R_0805_2012Metric; LCSC C95968
U5: ESP32-S3-WROOM-1-N16R8; XCVR_ESP32S3WROOM1N8R8; LCSC C2913202

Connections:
3.3V: C20.1, C21.1, J7.1, R21.1, U5.2 (3V3); also elsewhere on the board
3.3V_PERIPH: J4.4, R19.1, R20.1, R35.1; also elsewhere on the board
ESP32S3_EN: C19.1, D21.2 (A2), J7.2, R21.2, SW1.1, U5.3 (EN)
ESP32_RXD: J6.1, U5.36 (RXD0)
ESP32_TXD: J6.2, U5.37 (TXD0)
GND: C19.2, C20.2, C21.2, D21.1 (A1), D22.1 (A1), J4.1, J6.3, J7.4, J8.4, SW1.2, SW2.2, TH2.2, U5.1 (GND), U5.26 (IO45), U5.40 (GND), U5.41_1 (GND), U5.41_2 (GND), U5.41_3 (GND), U5.41_4 (GND), U5.41_5 (GND), U5.41_6 (GND), U5.41_7 (GND), U5.41_8 (GND), U5.41_9 (GND), U5.41_10 (GND), U5.41_11 (GND), U5.41_12 (GND), U5.41_13 (GND), U5.41_14 (GND), U5.41_15 (GND), U5.41_16 (GND), U5.41_17 (GND), U5.41_18 (GND), U5.41_19 (GND), U5.41_20 (GND), U5.41_21 (GND); also elsewhere on the board
GPIO0_BOOT: D22.2 (A2), J7.3, SW2.1, U5.27 (IO0)
GPIO1_SYNC_LED: U5.39 (IO1); also elsewhere on the board
GPIO2_OVL_LED: U5.38 (IO2); also elsewhere on the board
GPIO3_TLV320_MCLK: U5.15 (IO3); also elsewhere on the board
GPIO4_PTT_IN: U5.4 (IO4); also elsewhere on the board
GPIO5_MODE_BTN: J8.1, U5.5 (IO5); also elsewhere on the board
GPIO6_VOL_UP: J8.2, U5.6 (IO6); also elsewhere on the board
GPIO7_VOL_DOWN: J8.3, U5.7 (IO7); also elsewhere on the board
GPIO8_BAT_ALERT: U5.12 (IO8); also elsewhere on the board
GPIO9_TLV320_WCLK: U5.17 (IO9); also elsewhere on the board
GPIO10_TLV320_DIN: U5.18 (IO10); also elsewhere on the board
GPIO11_TLV320_DOUT: U5.19 (IO11); also elsewhere on the board
GPIO12_TLV320_MFP4: U5.20 (IO12); also elsewhere on the board
GPIO13_TLV320_RESET: U5.21 (IO13); also elsewhere on the board
GPIO14_TLV320_MFP5: U5.22 (IO14); also elsewhere on the board
GPIO15_PTT_LED: U5.8 (IO15); also elsewhere on the board
GPIO16_NET_LED: U5.9 (IO16); also elsewhere on the board
GPIO17_PERIPH_PWR: U5.10 (IO17); also elsewhere on the board
GPIO18_BOARD_TEMP: R35.2, TH2.1, U5.11 (IO18)
GPIO21_PTT_OUT: U5.23 (IO21); also elsewhere on the board
GPIO46_TLV320_BCLK: U5.16 (IO46); also elsewhere on the board
GPIO47_SDA: J4.2, R20.2, U5.24 (IO47); also elsewhere on the board
GPIO48_SCL: J4.3, R19.2, U5.25 (IO48); also elsewhere on the board
USB_D+: U5.14 (IO20); also elsewhere on the board
USB_D-: U5.13 (IO19); also elsewhere on the board

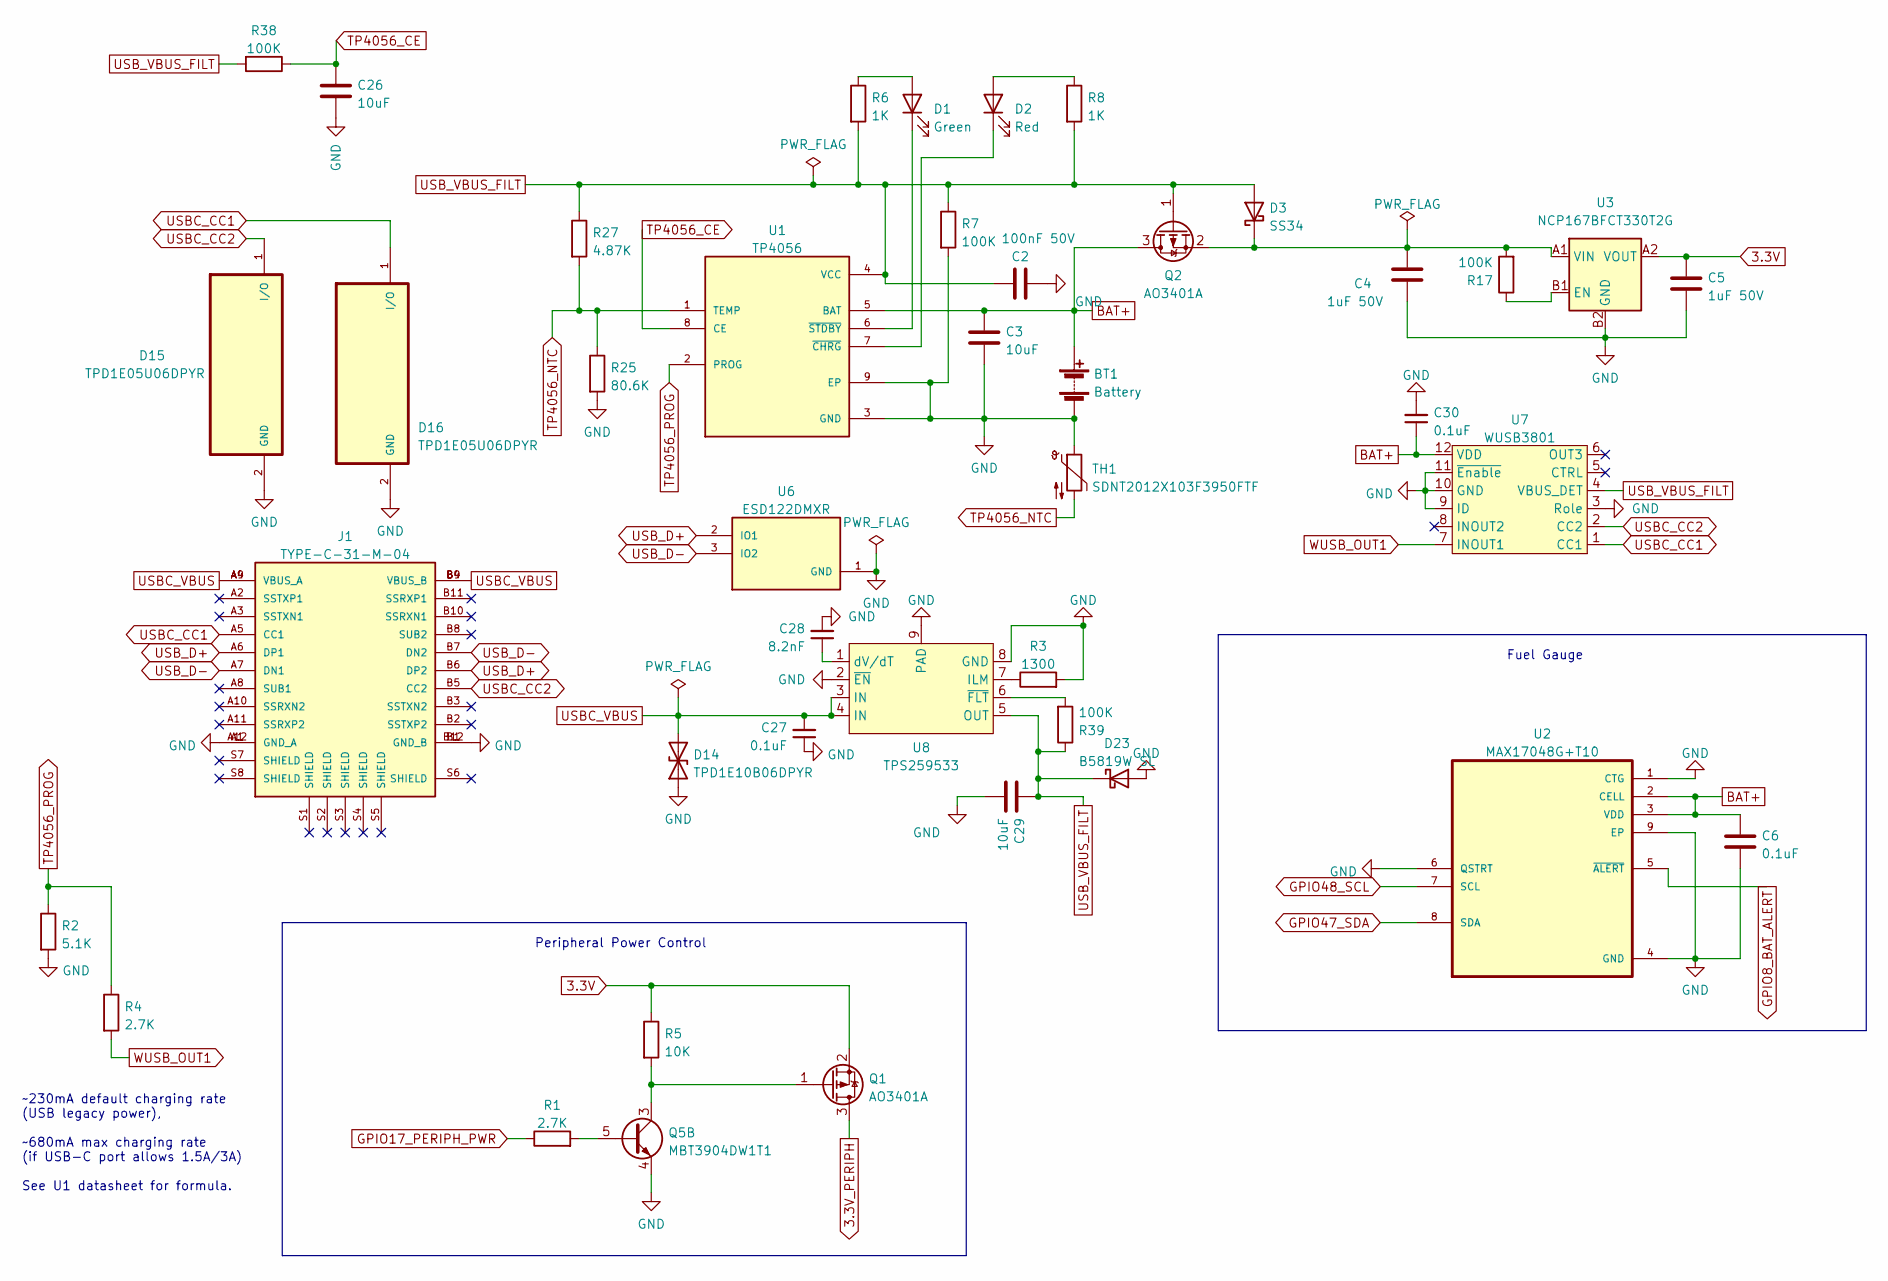
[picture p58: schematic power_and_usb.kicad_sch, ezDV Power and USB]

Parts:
BT1: Battery; PinSocket_1x02_P2.54mm_Vertical
C2: 100nF 50V; C_0402_1005Metric; LCSC C307331
C3, C29: 10uF; C_0402_1005Metric; LCSC C315248
C4, C5: 1uF 50V; C_0805_2012Metric; LCSC C28323
C6, C27, C30: 0.1uF; C_0402_1005Metric; LCSC C1525
C26: 10uF; C_0402_1005Metric; LCSC C307415
C28: 8.2nF; C_0402_1005Metric; LCSC C309459
D1: Green; D_0603_1608Metric; LCSC C434423
D2: Red; D_0603_1608Metric; LCSC C2286
D3: SS34; D_SMA; LCSC C8678
D14: TPD1E10B06DPYR; DIO_TPD1E05U06DPYR; LCSC C48260
D15, D16: TPD1E05U06DPYR; DIO_TPD1E05U06DPYR; LCSC C436349
D23: B5819W SL; D_SOD-123; LCSC C8598
J1: TYPE-C-31-M-04; HRO_TYPE-C-31-M-04; PARTREV A; LCSC C129018
Q1, Q2: AO3401A; SOT-23; LCSC C15127
Q5: MBT3904DW1T1; SOT-363_SC-70-6; LCSC C110150
R1: 2.7K; R_0603_1608Metric; LCSC C13167
R2: 5.1K; R_0402_1005Metric; LCSC C25905
R3: 1300; R_0402_1005Metric; LCSC C2974006
R4: 2.7K; R_0402_1005Metric; LCSC C138017
R5: 10K; R_0402_1005Metric; LCSC C25744
R6, R8: 1K; R_0402_1005Metric; LCSC C85373
R7, R17, R38, R39: 100K; R_0402_1005Metric; LCSC C25741
R25: 80.6K; R_0603_1608Metric; LCSC C403361
R27: 4.87K; R_0805_2012Metric; LCSC C218605
TH1: SDNT2012X103F3950FTF; R_0805_2012Metric; LCSC C95968
U1: TP4056; SOP127P600X175-9N; LCSC C16581
U2: MAX17048G+T10; SON50P200X200X80-9N; LCSC C2682616
U3: NCP167BFCT330T2G; BGA4N35P2X2_64X64X33N; LCSC C603663
U6: ESD122DMXR; IC_ESD122DMXR; PARTREV A; LCSC C544474
U7: WUSB3801; QFN1616-12L; LCSC C2931342
U8: TPS259533; WSON-8-1EP_2x2mm_P0.5mm_EP0.9x1.6mm_ThermalVias; LCSC C2155777

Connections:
3.3V: C5.1, Q1.2 (S), R5.1, U3.A2 (VOUT); also elsewhere on the board
3.3V_PERIPH: Q1.3 (D); also elsewhere on the board
BAT+: BT1.1 (+), C3.1, C6.1, C30.1, Q2.3 (D), U1.5 (BAT), U2.2 (CELL), U2.3 (VDD), U7.12 (VDD)
GND: BT1.2 (-), C2.1, C3.2, C4.2, C5.2, C6.2, C26.1, C27.1, C28.2, C29.2, C30.2, D14.1 (A1), D15.2 (GND), D16.2 (GND), D23.2 (A), J1.A1 (GND_A), J1.A12 (GND_A), J1.B1 (GND_B), J1.B12 (GND_B), Q5.4 (E2), R2.2, R3.2, R7.2, R25.2, TH1.1, U1.3 (GND), U1.9 (EP), U2.1 (CTG), U2.4 (GND), U2.6 (QSTRT), U2.9 (EP), U3.B2 (GND), U6.1 (GND), U7.3 (Role), U7.9 (ID), U7.10 (GND), U7.11 (~Enable), U8.2 (~EN), U8.8 (GND), U8.9 (PAD); also elsewhere on the board
GPIO8_BAT_ALERT: U2.5 (~ALERT); also elsewhere on the board
GPIO17_PERIPH_PWR: R1.1; also elsewhere on the board
GPIO47_SDA: U2.8 (SDA); also elsewhere on the board
GPIO48_SCL: U2.7 (SCL); also elsewhere on the board
unnamed: C4.1, D3.1 (K), Q2.2 (S), R17.2, U3.A1 (VIN)
unnamed: C28.1, U8.1 (dV/dT)
unnamed: D1.1 (K), U1.6 (~STDBY)
unnamed: D1.2 (A), R6.1
unnamed: D2.1 (K), U1.7 (~CHRG)
unnamed: D2.2 (A), R8.1
unnamed: Q1.1 (G), Q5.3 (C2), R5.2
unnamed: Q5.5 (B2), R1.2
unnamed: R3.1, U8.7 (ILM)
unnamed: R17.1, U3.B1 (EN)
unnamed: R39.2, U8.6 (~FLT)
TP4056_CE: C26.2, R38.1, U1.8 (CE)
TP4056_NTC: R25.1, R27.2, TH1.2, U1.1 (TEMP)
TP4056_PROG: R2.1, R4.1, U1.2 (PROG)
USBC_CC1: D16.1 (I/O), J1.A5 (CC1), U7.1 (CC1)
USBC_CC2: D15.1 (I/O), J1.B5 (CC2), U7.2 (CC2)
USBC_VBUS: C27.2, D14.2 (A2), J1.A4 (VBUS_A), J1.A9 (VBUS_A), J1.B4 (VBUS_B), J1.B9 (VBUS_B), U8.3 (IN), U8.4 (IN)
USB_D+: J1.A6 (DP1), J1.B6 (DP2), U6.2 (IO1); also elsewhere on the board
USB_D-: J1.A7 (DN1), J1.B7 (DN2), U6.3 (IO2); also elsewhere on the board
USB_VBUS_FILT: C2.2, C29.1, D3.2 (A), D23.1 (K), Q2.1 (G), R6.2, R7.1, R8.2, R27.1, R38.2, R39.1, U1.4 (VCC), U7.4 (VBUS_DET), U8.5 (OUT)
WUSB_OUT1: R4.2, U7.7 (INOUT1)

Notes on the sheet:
Fuel Gauge
Peripheral Power Control
~230mA default charging rate (USB legacy power), ~680mA max charging rate (if USB-C port allows 1.5A/3A) See U1 datasheet for formula.

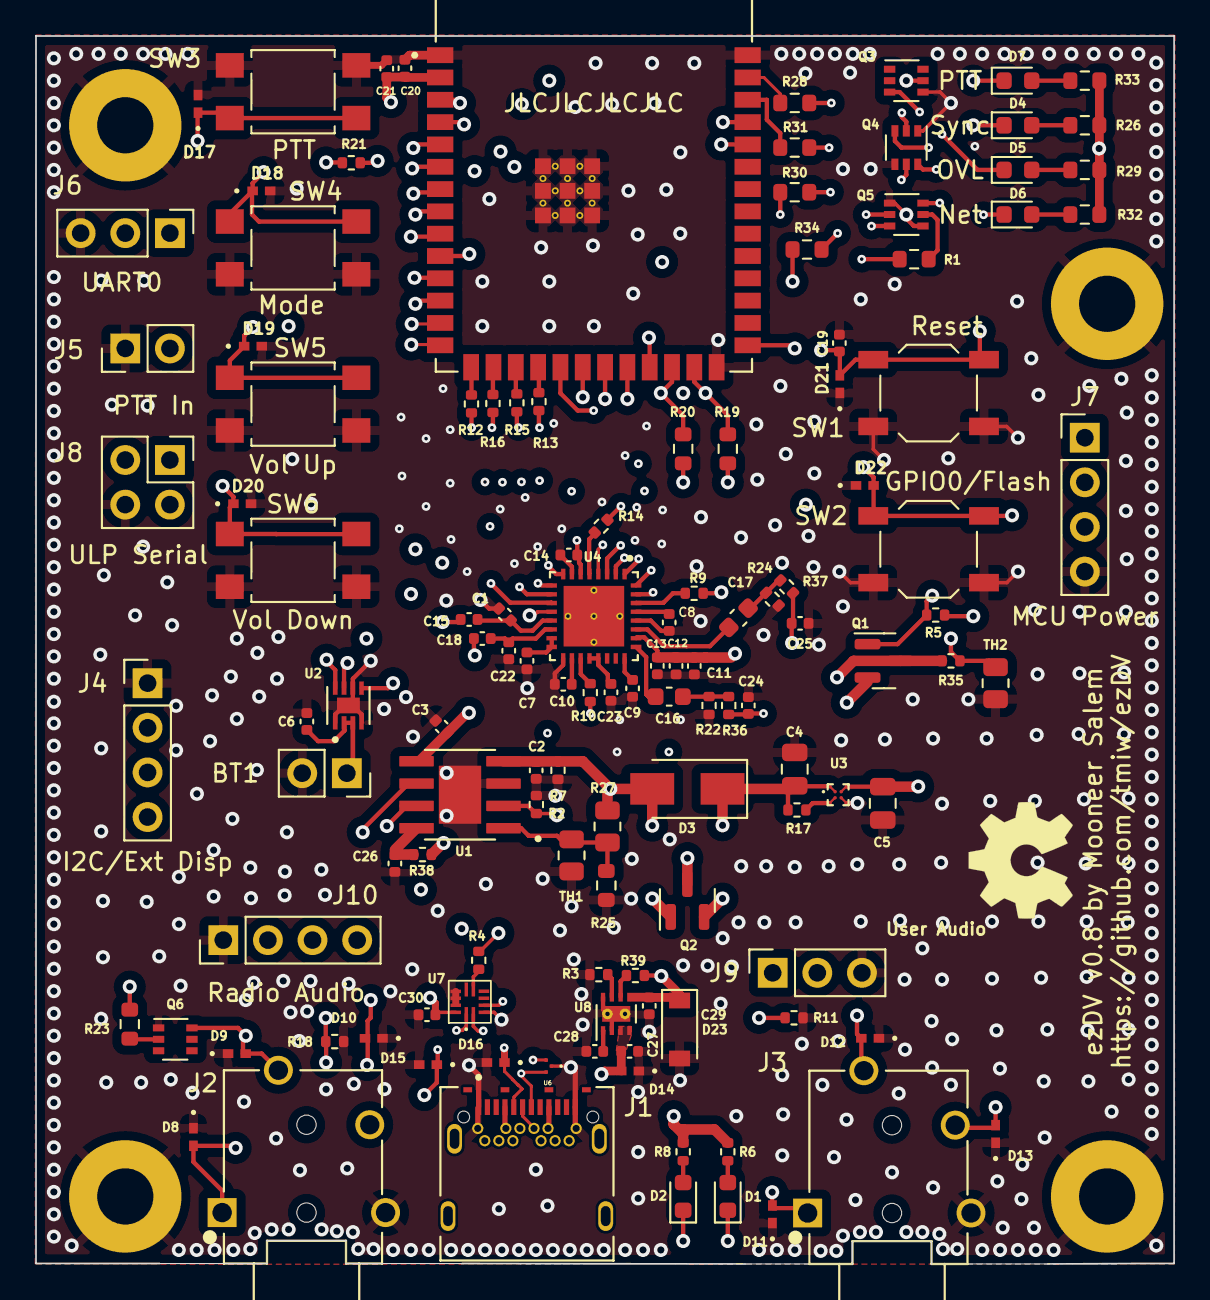
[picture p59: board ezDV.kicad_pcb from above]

Board: 6 copper layers, 64.8 x 69.9 mm, 129 parts (0 on the bottom side), 87 nets.

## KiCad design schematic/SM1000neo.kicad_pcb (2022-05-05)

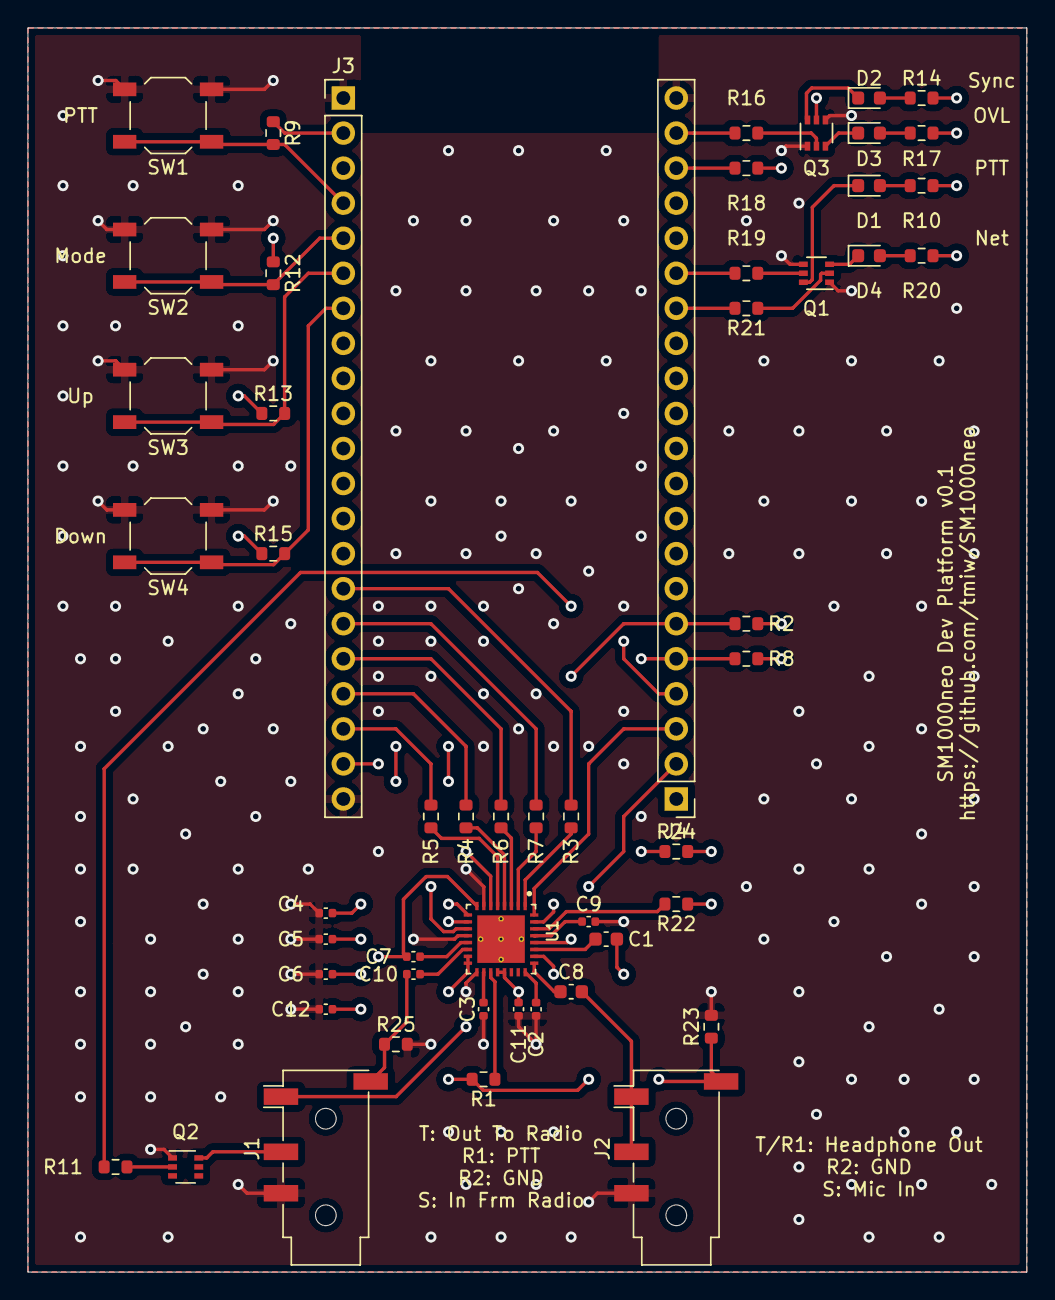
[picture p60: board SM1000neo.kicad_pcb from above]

Board: 4 copper layers, 72.4 x 90.2 mm, 53 parts (0 on the bottom side), 54 nets.

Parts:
C1, C2, C3, C4: 10uF; C_0402_1005Metric
C5: 1uF; C_0402_1005Metric
C6, C7, C10, C11, C12: 0.1uF; C_0402_1005Metric
C8, C9: 47uF; C_0603_1608Metric
D1: PTT_LED; D_0603_1608Metric
D2: SYNC_LED; D_0603_1608Metric
D3: OVL_LED; D_0603_1608Metric
D4: NET_LED; D_0603_1608Metric
J1: Radio_Jack; Jack_3.5mm_PJ320D_Horizontal
J2: User_Jack; Jack_3.5mm_PJ320D_Horizontal
J3: nanoESP32-S3-Left; PinHeader_1x21_P2.54mm_Vertical
J4: nanoESP32-S3-Right; PinHeader_1x21_P2.54mm_Vertical
Q1, Q2, Q3: MBT3904DW1T1; SOT-363_SC-70-6
R1, R11, R16, R18, R19, R21: 2.7K; R_0603_1608Metric
R2, R8, R22, R24: 4.7K; R_0603_1608Metric
R3: 10; R_0603_1608Metric
R4, R5, R6, R7: 27; R_0603_1608Metric
R9, R12, R13, R15: 3.3K; R_0603_1608Metric
R10, R17: 100; R_0603_1608Metric
R14, R20: 50; R_0603_1608Metric
R23, R25: 1M; R_0603_1608Metric
SW1: PTT_Button; SW_SPST_TL3342
SW2: Mode_Button; SW_SPST_TL3342
SW3: Vol_Up_Button; SW_SPST_TL3342
SW4: Vol_Down_Button; SW_SPST_TL3342
U1: TLV320AIC3254IRHBR; IC_ADS125H01IRHBT

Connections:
3.3V: C4.1, C5.1, C6.1, C12.1, J3.2, R2.1, R8.1, R9.1, R10.2, R12.1, R13.1, R14.2, R15.1, R17.2, R20.1, R22.1, R24.2, U1.6, U1.26
GND: C1.1, C2.2, C3.1, C4.2, C5.2, C6.2, C11.2, C12.2, J1.R2, J2.R2, J3.1, J3.21, J4.21, Q1.1, Q1.4, Q2.1, Q3.1, Q3.4, R23.2, R25.2, SW1.2, SW2.2, SW3.2, SW4.2, U1.7, U1.12, U1.17, U1.28, U1.33, U1.34, U1.35, U1.36, U1.37, U1.38
GPIO1_SYNC_LED: J4.20, R16.2
GPIO2_OVL_LED: J4.19, R18.2
GPIO3_TLV320_MCLK: J3.15, R3.2
GPIO4_PTT_IN: J3.4, R9.2, SW1.1
GPIO5_MODE_BTN: J3.5, R12.2, SW2.1
GPIO6_VOL_UP: J3.6, R13.2, SW3.1
GPIO7_VOL_DOWN: J3.7, R15.2, SW4.1
GPIO9_TLV320_WCLK: J3.17, R6.2
GPIO10_TLV320_DIN: J3.18, R4.2
GPIO11_TLV320_DOUT: J3.19, R5.2
GPIO12_TLV320_RESET: J3.20, R24.1, U1.31
GPIO13_TLV320_MFP4: J4.2, U1.11
GPIO14_TLV320_MFP5: J4.3, U1.32
GPIO21_PTT_OUT: J4.4, R11.2
GPIO41_PTT_LED: J4.15, R21.2
GPIO42_NET_LED: J4.16, R19.2
GPIO46_TLV320_BCLK: J3.16, R7.2
GPIO47_TLV320_SDA: J4.5, R8.2, U1.10
GPIO48_TLV320_SCL: J4.6, R2.2, U1.9
unnamed: C11.1, U1.15, U1.16, U1.20, U1.21
unnamed: D1.1, Q1.6
unnamed: D1.2, R10.1
unnamed: D2.1, Q3.6
unnamed: D2.2, R14.1
unnamed: D3.1, Q3.3
unnamed: D3.2, R17.1
unnamed: D4.1, Q1.3
unnamed: D4.2, R20.2
unnamed: Q1.2, R21.1
unnamed: Q1.5, R19.1
unnamed: Q2.2, R11.1
unnamed: Q3.2, R16.1
unnamed: Q3.5, R18.1
unnamed: R22.2, U1.30
Radio_Jack_Mic: C10.1, J1.S, R25.1
Radio_Jack_PTT: J1.R1, Q2.6
Radio_Jack_Speaker: C9.2, J1.T
TLV320_AVDD: C2.1, U1.24
TLV320_DVDD: C1.2, U1.29
TLV320_IN_DETECT: C7.1, J2.S, R1.2, R23.1, U1.8
TLV320_IN_DIN: R4.1, U1.4
TLV320_IN_MCLK: R3.1, U1.1
TLV320_IN_RADIO: C10.2, U1.14
TLV320_IN_USER: C7.2, U1.13
TLV320_IO_BCLK: R7.1, U1.2
TLV320_IO_WCLK: R6.1, U1.3
TLV320_OUT_DOUT: R5.1, U1.5
TLV320_OUT_MICBIAS: R1.1, U1.19
TLV320_OUT_RADIO: C9.1, U1.27
TLV320_OUT_USER: C8.1, U1.25
TLV320_REF: C3.2, U1.18
User_Jack_Speaker: C8.2, J2.R1, J2.T

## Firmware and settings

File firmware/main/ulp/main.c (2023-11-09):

// Simple ULP RISC-V application to monitor the GPIO corresponding to the
// Mode button. If it's pressed for >= 1 second, we trigger a wakeup of 
// the main processor.

#include <stdio.h>
#include <stdint.h>
#include <stdbool.h>
#include "ulp_riscv.h"
#include "ulp_riscv_utils.h"
#include "ulp_riscv_gpio.h"

volatile int num_cycles_with_gpio_on = 0;
volatile int num_cycles_with_usb_gpio_on = 0;

// Power-up modes:
// 0: normal bootup
// 1: temperature check bootup
// 2: fuel gauge mode
volatile int power_up_mode = 0;

volatile int num_cycles_between_temp_checks = 0;

#define TURN_ON_GPIO_NUM GPIO_NUM_5
#define MIN_NUM_CYCLES_BOOTUP (10) /* based on wakeup period (100ms), 10 cycles should result in 1s required for wakeup. */
#define MIN_NUM_CYCLES_TEMP_CHECK (36000) /* Set to 60min (36000 cycles) */

// Settings to allow detection of charging before booting
// to fuel gauge mode.
#define FUEL_GAUGE_INTERRUPT_GPIO_NUM 0

int main (void)
{
    ulp_riscv_gpio_init(TURN_ON_GPIO_NUM);
    ulp_riscv_gpio_input_enable(TURN_ON_GPIO_NUM);
    ulp_riscv_gpio_output_disable(TURN_ON_GPIO_NUM);
    ulp_riscv_gpio_pullup(TURN_ON_GPIO_NUM);
    ulp_riscv_gpio_pulldown_disable(TURN_ON_GPIO_NUM);

    ulp_riscv_gpio_init(FUEL_GAUGE_INTERRUPT_GPIO_NUM);
    ulp_riscv_gpio_input_enable(FUEL_GAUGE_INTERRUPT_GPIO_NUM);
    ulp_riscv_gpio_output_disable(FUEL_GAUGE_INTERRUPT_GPIO_NUM);
    ulp_riscv_gpio_pullup_disable(FUEL_GAUGE_INTERRUPT_GPIO_NUM);
    ulp_riscv_gpio_pulldown_disable(FUEL_GAUGE_INTERRUPT_GPIO_NUM);

    if (!ulp_riscv_gpio_get_level(TURN_ON_GPIO_NUM))
    {
        num_cycles_with_gpio_on++;
        if (num_cycles_with_gpio_on >= MIN_NUM_CYCLES_BOOTUP)
        {
            power_up_mode = 0;
            num_cycles_between_temp_checks = 0;
            ulp_riscv_wakeup_main_processor();
            return 0;
        }
    }
    else
    {
        num_cycles_with_gpio_on = 0;
    }

    // GPIO0 has a resistor divider on the 5V rail intended to help us determine
    // whether USB power exists. If this becomes 1 for more than 300ms (debounce),
    // we should boot into battery gauge mode.
    if (ulp_riscv_gpio_get_level(FUEL_GAUGE_INTERRUPT_GPIO_NUM))
    {
        num_cycles_with_usb_gpio_on++;
        if (num_cycles_with_usb_gpio_on >= 3)
        {
            power_up_mode = 2;
            num_cycles_between_temp_checks = 0;
            num_cycles_with_usb_gpio_on = 0;
            ulp_riscv_wakeup_main_processor();
            return 0;
        }
    }
    else
    {
        num_cycles_with_usb_gpio_on = 0;
        power_up_mode = 0;
    }

#if 0
    /* 
        Normally, temperature checks occur every minute to ensure accurate
        battery fuel gauge calculations. However, to minimize power
        consumption, the thermistor only has power when ezDV is fully
        on. Thus, we have a separate check here to allow ezDV to briefly
        turn on every 60 minutes to save the current temperature to the
        fuel gauge chip. This forced power-up occurs infrequently enough
        (and ezDV powered up for short enough) that there should be little 
        impact on self-drain.
    */
    num_cycles_between_temp_checks++;
    if (num_cycles_between_temp_checks >= MIN_NUM_CYCLES_TEMP_CHECK)
    {
        num_cycles_between_temp_checks = 0;
        num_cycles_with_usb_gpio_on = 0;
        num_cycles_with_gpio_on = 0;
        power_up_mode = 1;
        ulp_riscv_wakeup_main_processor();
    }
#endif // 0

    // Reinit GPIO0 to default settings to avoid high power consumption while in ULP.
    ulp_riscv_gpio_init(FUEL_GAUGE_INTERRUPT_GPIO_NUM);
    
    /* ulp_riscv_halt() is called automatically when main exits */
    return 0;
}

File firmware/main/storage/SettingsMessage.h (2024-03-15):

/* 
 * This file is part of the ezDV project (https://github.com/tmiw/ezDV).
 * Copyright (c) 2022 Mooneer Salem
 * 
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
 * You should have received a copy of the GNU General Public License 
 * along with this program. If not, see <http://www.gnu.org/licenses/>.
 */

#ifndef SETTINGS_MESSAGE_H
#define SETTINGS_MESSAGE_H

#include <cstring>

#include "task/DVTaskMessage.h"

extern "C"
{
    DV_EVENT_DECLARE_BASE(SETTINGS_MESSAGE);
}

namespace ezdv
{

namespace storage
{

using namespace ezdv::task;

enum SettingsMessageTypes
{
    LEFT_CHANNEL_VOLUME = 1,
    RIGHT_CHANNEL_VOLUME = 2,
    SET_LEFT_CHANNEL_VOLUME = 3,
    SET_RIGHT_CHANNEL_VOLUME = 4,
    
    WIFI_SETTINGS = 5,
    SET_WIFI_SETTINGS = 6,
    REQUEST_WIFI_SETTINGS = 7,
    WIFI_SETTINGS_SAVED = 8,
    
    RADIO_SETTINGS = 9,
    SET_RADIO_SETTINGS = 10,
    REQUEST_RADIO_SETTINGS = 11,
    RADIO_SETTINGS_SAVED = 12,

    VOICE_KEYER_SETTINGS = 13,
    SET_VOICE_KEYER_SETTINGS = 14,
    REQUEST_VOICE_KEYER_SETTINGS = 15,
    VOICE_KEYER_SETTINGS_SAVED = 16,

    REPORTING_SETTINGS = 17,
    SET_REPORTING_SETTINGS = 18,
    REQUEST_REPORTING_SETTINGS = 19,
    REPORTING_SETTINGS_SAVED = 20,
    
    LED_BRIGHTNESS_SETTINGS = 21,
    SET_LED_BRIGHTNESS_SETTINGS = 22,
    REQUEST_LED_BRIGHTNESS_SETTINGS = 23,
    LED_BRIGHTNESS_SETTINGS_SAVED = 24,
    
    REQUEST_VOLUME_SETTINGS = 25,
};

template<uint32_t TYPE_ID>
class VolumeMessageCommon : public DVTaskMessageBase<TYPE_ID, VolumeMessageCommon<TYPE_ID>>
{
public:
    VolumeMessageCommon(int8_t volProvided = 0)
        : DVTaskMessageBase<TYPE_ID, VolumeMessageCommon<TYPE_ID>>(SETTINGS_MESSAGE) 
        , volume(volProvided) { }
    virtual ~VolumeMessageCommon() = default;

    int8_t volume;
};

enum WifiMode { ACCESS_POINT, CLIENT };
enum WifiSecurityMode { NONE, WEP, WPA, WPA2, WPA_AND_WPA2, /*WPA3, WPA2_AND_WPA3*/ };

template<uint32_t TYPE_ID>
class WifiSettingsMessageCommon : public DVTaskMessageBase<TYPE_ID, WifiSettingsMessageCommon<TYPE_ID>>
{
public:
    enum { MAX_STR_SIZE = 32 };
    
    WifiSettingsMessageCommon(
        bool enabledProvided = false, 
        WifiMode modeProvided = ACCESS_POINT, 
        WifiSecurityMode securityProvided = NONE, 
        int channelProvided = 0, 
        const char* ssidProvided = "", 
        const char* passwordProvided = "",
        const char* hostnameProvided = "")
        : DVTaskMessageBase<TYPE_ID, WifiSettingsMessageCommon<TYPE_ID>>(SETTINGS_MESSAGE) 
        , enabled(enabledProvided)
        , mode(modeProvided)
        , security(securityProvided)
        , channel(channelProvided)
    { 
        memset(ssid, 0, MAX_STR_SIZE);
        memset(password, 0, MAX_STR_SIZE);
        memset(hostname, 0, MAX_STR_SIZE);
        
        if (ssidProvided != nullptr)
        {
            strncpy(ssid, ssidProvided, MAX_STR_SIZE - 1);
        }
        if (passwordProvided != nullptr)
        {
            strncpy(password, passwordProvided, MAX_STR_SIZE - 1);
        }
        if (hostnameProvided != nullptr)
        {
            strncpy(hostname, hostnameProvided, MAX_STR_SIZE - 1);
        }
    }
    
    virtual ~WifiSettingsMessageCommon() = default;

    bool enabled;
    WifiMode mode;
    WifiSecurityMode security; // ignored if not access point
    int channel; // ignored if not access point
    char ssid[MAX_STR_SIZE];
    char password[MAX_STR_SIZE];
    char hostname[MAX_STR_SIZE];
};

template<uint32_t TYPE_ID>
class RadioSettingsMessageCommon : public DVTaskMessageBase<TYPE_ID, RadioSettingsMessageCommon<TYPE_ID>>
{
public:
    enum { MAX_STR_SIZE = 32 };
    
    RadioSettingsMessageCommon(
        bool headsetPttProvided = false, 
        int timeOutTimerProvided = 0, 
        bool enabledProvided = false, 
        int typeProvided = 0, 
        const char* hostProvided = "", 
        int portProvided = 0, 
        const char* usernameProvided = "", 
        const char* passwordProvided = "")
        : DVTaskMessageBase<TYPE_ID, RadioSettingsMessageCommon<TYPE_ID>>(SETTINGS_MESSAGE) 
        , headsetPtt(headsetPttProvided)
        , timeOutTimer(timeOutTimerProvided)
        , enabled(enabledProvided)
        , type(typeProvided)
        , port(portProvided)
    { 
        memset(host, 0, MAX_STR_SIZE);
        memset(username, 0, MAX_STR_SIZE);
        memset(password, 0, MAX_STR_SIZE);

        if (hostProvided != nullptr)
        {
            strncpy(host, hostProvided, MAX_STR_SIZE - 1);
        }
        if (usernameProvided != nullptr)
        {
            strncpy(username, usernameProvided, MAX_STR_SIZE - 1);
        }
        if (passwordProvided != nullptr)
        {
            strncpy(password, passwordProvided, MAX_STR_SIZE - 1);
        }
    }
    
    virtual ~RadioSettingsMessageCommon() = default;

    bool headsetPtt;
    int timeOutTimer;
    bool enabled;
    int type;
    int port;
    char host[MAX_STR_SIZE];
    char username[MAX_STR_SIZE];
    char password[MAX_STR_SIZE];
};
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

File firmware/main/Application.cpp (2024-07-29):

/* 
 * This file is part of the ezDV project (https://github.com/tmiw/ezDV).
 * Copyright (c) 2024 Mooneer Salem
 * 
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
 * You should have received a copy of the GNU General Public License 
 * along with this program. If not, see <http://www.gnu.org/licenses/>.
 */

#include "Application.h"

#include "driver/rtc_io.h"
#include "driver/gpio.h"
#include "ulp_riscv.h"
#include "ulp_main.h"
#include "esp_sleep.h"
#include "esp_log.h"

#if CONFIG_EZDV_PRINT_HEAP_USAGE
#include "esp_heap_task_info.h"
#endif // CONFIG_EZDV_PRINT_HEAP_USAGE

#if CONFIG_EZDV_ENABLE_TICK_OUTPUT
#define MAIN_APP_TASK_TICK_INTERVAL (pdMS_TO_TICKS(CONFIG_EZDV_TICK_OUTPUT_INTERVAL))
#else
#define MAIN_APP_TASK_TICK_INTERVAL (portMAX_DELAY)
#endif // CONFIG_EZDV_ENABLE_TICK_OUTPUT

#if CONFIG_EZDV_ENABLE_TX_RX_AUTOMATED_TEST
#include "driver/ButtonMessage.h"
#include "audio/FreeDVMessage.h"
#endif // CONFIG_EZDV_ENABLE_TX_RX_AUTOMATED_TEST

#define CURRENT_LOG_TAG ("app")

#define BOOTUP_VOL_DOWN_GPIO (GPIO_NUM_7)
#define BOOTUP_PTT_GPIO (GPIO_NUM_4)
#define TLV320_RESET_GPIO (GPIO_NUM_13)

#if CONFIG_EZDV_OUTPUT_TASK_LIST
#define ARRAY_SIZE_OFFSET   5   //Increase this if print_real_time_stats returns ESP_ERR_INVALID_SIZE
#endif // CONFIG_EZDV_OUTPUT_TASK_LIST

extern "C"
{
    // Power off handler application
    extern const uint8_t ulp_main_bin_start[] asm("_binary_ulp_main_bin_start");
    extern const uint8_t ulp_main_bin_end[]   asm("_binary_ulp_main_bin_end");
    
    bool rebootDevice = false;
}

void* operator new  ( std::size_t count )
{
    return heap_caps_malloc(count, MALLOC_CAP_SPIRAM | MALLOC_CAP_32BIT);
}

void operator delete  ( void* ptr ) noexcept
{
    return heap_caps_free(ptr);
}

void operator delete(void* ptr, std::size_t)
{
    return heap_caps_free(ptr);
}

namespace ezdv
{
    
App::App()
    : ezdv::task::DVTask("MainApp", 1, 4096, tskNO_AFFINITY, 10, MAIN_APP_TASK_TICK_INTERVAL)
    , audioMixer_(nullptr)
    , beeperTask_(nullptr)
    , freedvTask_(nullptr)
    , max17048_(&i2cMaster_)
    , tlv320Device_(nullptr)
    , networkTask_(nullptr)
    , settingsTask_(nullptr)
    , softwareUpdateTask_(nullptr)
    , uiTask_(nullptr)
    , rfComplianceTask_(nullptr)
    , fuelGaugeTask_(nullptr)
    , voiceKeyerTask_(nullptr)
    , rfComplianceEnabled_(false)
    , wifiOverrideEnabled_(false)
{
    // empty
}

void App::checkOverrides_()
{
    // Check to see if Vol Down is being held on startup. 
    // If so, force use of default Wi-Fi setup. Note that 
    // we have to duplicate the initial pin setup here 
    // since waiting until the UI is fully up may be too
    // late for Wi-Fi.
    ESP_ERROR_CHECK(gpio_reset_pin(BOOTUP_VOL_DOWN_GPIO));
    ESP_ERROR_CHECK(gpio_set_direction(BOOTUP_VOL_DOWN_GPIO, GPIO_MODE_INPUT));
    ESP_ERROR_CHECK(gpio_set_pull_mode(BOOTUP_VOL_DOWN_GPIO, GPIO_PULLUP_ONLY));
    ESP_ERROR_CHECK(gpio_pullup_en(BOOTUP_VOL_DOWN_GPIO));

    if (gpio_get_level(BOOTUP_VOL_DOWN_GPIO) == 0)
    {
        wifiOverrideEnabled_ = true;
    }
    
    // Check to see if PTT is beind held on startup.
    // This triggers the RF compliance test system.
    ESP_ERROR_CHECK(gpio_reset_pin(BOOTUP_PTT_GPIO));
    ESP_ERROR_CHECK(gpio_set_direction(BOOTUP_PTT_GPIO, GPIO_MODE_INPUT));
    ESP_ERROR_CHECK(gpio_set_pull_mode(BOOTUP_PTT_GPIO, GPIO_PULLUP_ONLY));
    ESP_ERROR_CHECK(gpio_pullup_en(BOOTUP_PTT_GPIO));
    
    if (gpio_get_level(BOOTUP_PTT_GPIO) == 0)
    {
        rfComplianceEnabled_ = true;
    }
}

void App::enablePeripheralPower_()
{
    // Reset GPIO0 to prevent glitches
    rtc_gpio_init(GPIO_NUM_0);
    rtc_gpio_set_direction(GPIO_NUM_0, RTC_GPIO_MODE_INPUT_ONLY);
    rtc_gpio_set_direction_in_sleep(GPIO_NUM_0, RTC_GPIO_MODE_INPUT_ONLY);
    rtc_gpio_pulldown_dis(GPIO_NUM_0);
    rtc_gpio_pullup_dis(GPIO_NUM_0);
    rtc_gpio_hold_en(GPIO_NUM_0);
    
    // TLV320 related GPIOs need to be isolated prior to enabling
    // peripheral power. If we don't do this, the following happens
    // the first time after waking up from deep sleep:
    //
    // 1. Network (and potentially other LEDs) stop working, and
    // 2. Audio glitches occur on startup.
    std::vector<gpio_num_t> tlv320Gpios { 
        GPIO_NUM_3, GPIO_NUM_9, GPIO_NUM_10, GPIO_NUM_11,
        GPIO_NUM_12, GPIO_NUM_14, TLV320_RESET_GPIO };
    for (auto& gpio : tlv320Gpios)
    {
        rtc_gpio_init(gpio);
        rtc_gpio_set_direction(gpio, RTC_GPIO_MODE_INPUT_ONLY);
        rtc_gpio_set_direction_in_sleep(gpio, RTC_GPIO_MODE_INPUT_ONLY);
        rtc_gpio_pulldown_en(gpio);
        rtc_gpio_pullup_dis(gpio);
        rtc_gpio_hold_en(gpio);
    }
    
    // Sleep for above changes to take effect.
    vTaskDelay(pdMS_TO_TICKS(10));

    // Enable peripheral power (required for v0.4+). This will automatically
    // power down once we switch to the ULP processor on shutdown, reducing
    // "off" current considerably.
    rtc_gpio_init(GPIO_NUM_17);
    rtc_gpio_hold_dis(GPIO_NUM_17);
    rtc_gpio_set_direction(GPIO_NUM_17, RTC_GPIO_MODE_OUTPUT_ONLY);
    rtc_gpio_set_level(GPIO_NUM_17, true);
    rtc_gpio_hold_en(GPIO_NUM_17);
    
    // Sleep until peripheral power activates.
    vTaskDelay(pdMS_TO_TICKS(10));

    // Now we can re-attach TLV320 related GPIOs and get
    // ready to configure it.
    for (auto& gpio : tlv320Gpios)
    {
        rtc_gpio_hold_dis(gpio);
        rtc_gpio_deinit(gpio);
        gpio_reset_pin(gpio);
    }
    
    rtc_gpio_hold_dis(GPIO_NUM_0);
    rtc_gpio_deinit(GPIO_NUM_0);
    gpio_reset_pin(GPIO_NUM_0);
    
    // Sleep for GPIO reattach to take effect.
    vTaskDelay(pdMS_TO_TICKS(10));
}
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

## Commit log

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2022-05-05 BOM for D2 has the wrong sized LED, updated to fix.
    [ExternalConnections.sch, SM1000neo.csv]
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2022-05-09 ESP32-S3 doesn't support APLL, so we need to enable PLL on the TLV320.
    [TLV320.cpp]
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2022-05-12 Resolved issues preventing radio from sending responses back.
    [Application.cpp]
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2022-05-15 Fixed issues preventing ADC from functioning properly.
    [TLV320.cpp]
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2022-05-16 Non-working basic CIV control.
    TODO:
    1. Figure out why the CIV open packet doesn't seem to be getting sent.
    2. Need one of the ESP32S3 models with PSRAM as we may be heap limited.
    [Application.cpp]
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2022-05-28 Move I2C SCL to GPIO 45 to resolve #9.
    [ExternalConnections.sch]
2022-05-28 Decrease R1 to increase mic bias current (#8).
    [AudioCodec.sch]
2022-05-28 Increase C7 and C10 to 0.47uF to match TLV320 EVM (partial solution for #10).
    [AudioCodec.sch]
2022-05-28 Adjust R10 and R17 to match 20mA output current of other status LEDs. (#6)
    [ExternalConnections.sch]
2022-05-29 Recreated dev platform PCB from scratch;
    1. Swapped MFP4 and Reset for TLV320 for ease of routing. (#10)
    2. Added vias around outside edge of board. (#1)
    3. Added mounting holes for the dev board. (#5)
    4. Moved silkscreen labels to improve readability. (#7)
    5. Routed sensitive audio traces in inner layer and surrounded by ground vias/planes. (#10)
    6. Set mic input capacitor values to same as used on TLV320 EVM to help with noise. (#10)
    7. Replaced some parts with 0402 equivalents to help with positioning closer to TLV320. (#10)
    [AudioCodec.sch, ExternalConnections.sch, ezDV.kicad_pcb]
2022-05-29 Minor tweak to get JLCPCB's PCB assembly service to detect U1.
    [ezDV.csv, ezDV.kicad_pcb]
2022-06-07 Switch reset GPIO per v0.2 schematic.
    [TLV320.cpp]
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2022-06-09 Minor TLV320 init tweaks to fix ADC.
    [TLV320.cpp]
2022-06-10 Partial fix for TLV320 audio input issue.
    [TLV320.cpp]
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2022-07-28 Increase size of cutouts to allow buttons to go in and out.
    [enclosure.scad]
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2022-08-28 Remove legacy footprints and symbols from user schematic.
    [AudioCodec.sch, ExternalConnections.sch, TLV320AIC3254IRHBR.step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]
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2022-08-29 TBD: shutdown via UI task working but ULP won't come back up.
    [Application.cpp]
2022-08-31 Resolve problem preventing proper repeated resume from deep sleep.
    [Application.cpp]
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2022-09-04 Resolve memory leak in publish from last commit.
    [Application.cpp]
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2022-09-04 Strip out esp_event from codebase since we're no longer using it.
    [Application.cpp]
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2022-09-04 Fix deadlock in publish.
    [Application.cpp]
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2022-09-05 Fix LED_NPN typos.
2022-09-05 Prevent dropouts while decoding RX audio.
    [TLV320.cpp]
2022-09-06 Create SPIFFS partition to serve config interface from.
    [partitions.csv]
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2022-09-08 Fuel gauge driver fixes now that we have hardware.
    [Application.cpp, MAX17048.cpp]
2022-09-08 v0.3 isn't properly reporting reset cause for some reason, so we disable auto-sleep on startup.
    [Application.cpp]
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2022-09-11 Fix bugs preventing connection of the ESP32 with the radio.
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2022-09-17 Debug code for tracking possible memory leaks.
    [Application.cpp]
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2022-09-20 Switch Codec2 back to devel branch to test allocation wrapper.
    [enclosure-top.stl, enclosure.scad]
2022-09-22 Fix high CPU usage when scaling TX samples.
2022-09-26 Add backend logic for voice keying minus saving new .wav files.
    [partitions.csv]
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2022-09-29 v0.4 board: add MOSFET power control for TLV320 and other peripherals
    [audio_codec.kicad_sch, esp32s3.kicad_sch, ezDV.kicad_pcb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]
2022-09-29 v0.4 board: substitute JLCPCB basic parts where possible ($3/component savings).
    [audio_codec.kicad_sch, external_interface.kicad_sch, power_and_usb.kicad_sch]
2022-09-29 v0.4 board: rm unnecesary pullups, update button/LED labeling
    [external_interface.kicad_sch, ezDV.kicad_pcb, ezDV.kicad_sch]
2022-09-30 v0.4 board: increase power trace width, reposition decoupling caps, add missing depop resistors
    [audio_codec.kicad_sch, ezDV.kicad_pcb, ezDV.kicad_sch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]
2022-09-30 v0.4 board: Add override to eliminate some spurious errors.
    [ezDV.kicad_pcb]
2022-09-30 v0.4 board: more tweaks to circuit traces and new components
    [audio_codec.kicad_sch, ezDV.kicad_pcb, ezDV.kicad_sch]
2022-09-30 v0.4 board: adjust pulldown resistors for audio I/O.
    [audio_codec.kicad_sch, ezDV.kicad_pcb, ezDV.kicad_sch]
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2022-10-02 Add missed initialization to make headset button presses reliable.
    [TLV320.cpp]
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2022-10-13 Use pyramid at the end of each button to prevent them from falling out.
    [enclosure.scad]
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2022-10-21 Add a bit more space to the factory partition.
    [partitions.csv]
2022-10-23 v0.5 board: reroute headset detect trace to avoid noise pickup.
    [ezDV.kicad_pcb]
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2022-11-28 v0.5 board: reroute temp sensor ADC to GPIO 18.
    [esp32s3.kicad_sch, ezDV.kicad_pcb]
2022-11-28 v0.5 board: add I2C breakout header for potential future OLED screen integration.
    [esp32s3.kicad_sch, ezDV.kicad_pcb, ezDV.kicad_sch]
2022-12-04 v0.5 board: move PERIPH_PWR GPIO to RTC to make sure it stays off when sleeping.
    [esp32s3.kicad_sch, external_interface.kicad_sch, ezDV.kicad_pcb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]
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2022-12-05 v0.5 board: move PTT and NET GPIOs to RTC domain.
    [esp32s3.kicad_sch, external_interface.kicad_sch, ezDV.kicad_pcb]
2022-12-05 v0.5 board: move SCL to GPIO 48 as 45 is a ESP32 strapping pin.
    [audio_codec.kicad_sch, esp32s3.kicad_sch, ezDV.kicad_pcb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]
2022-12-05 v0.5 board: use taller buttons to hopefully avoid need to build buttons into enclosure.
    [external_interface.kicad_sch, ezDV.kicad_pcb, ezDV.kicad_sch]
2022-12-05 v0.5 board: Switch to through hole part for radio/user jacks.
    [external_interface.kicad_sch, ezDV.kicad_pcb, ezDV.kicad_sch]
2022-12-05 v0.5 board: fix DRC errors and warnings.
    [ezDV.kicad_pcb]
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2022-12-06 v0.6 board: adjust via locations for SMT assembly.
    [ezDV.kicad_pcb]
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2022-12-20 Forgot to set enable to false on shutdown, causing reboot on sleep due to unexpected console output.
    [MAX17048.cpp]
2022-12-20 Headset button can be reenabled without causing noise in the headset as of v0.5.
    [TLV320.cpp]
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2022-12-22 v0.6 board: remove unneeded pullup for TLV320 reset pin (~370 uA->~50 uA deep sleep current savings).
    [audio_codec.kicad_sch, ezDV.kicad_pcb, ezDV.kicad_sch]
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2022-12-30 v0.6 board: add UART0 header to assist with ESP RF Test Tool.
    [esp32s3.kicad_sch, external_interface.kicad_sch, ezDV.kicad_pcb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]
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2022-12-30 Prevent bootup if voltage is too low and shut down once SOC gets too low.
    [Application.cpp, MAX17048.cpp]
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2023-01-01 Reenable ADC HPF to prevent AGC from amplifying board noise.
    [TLV320.cpp]
2023-01-01 v0.6 board: fix orientation of C3 label.
    [ezDV.kicad_pcb]
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2023-01-02 v0.6 board: add J7 so that the board can be powered directly from 3.3V and GPIO/reset externally controlled.
    [esp32s3.kicad_sch, ezDV.kicad_pcb, ezDV.kicad_sch]
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2023-01-02 v0.6 board: add output-only ULP Serial header for future ULP code debugging + regulatory use.
    [esp32s3.kicad_sch, ezDV.kicad_pcb, ezDV.kicad_sch]
2023-01-02 v0.6 board: replace LDO with NCP167 for lower noise and Iq.
    [ezDV.kicad_pcb, ezDV.kicad_sch, power_and_usb.kicad_sch]
2023-01-02 v0.6 board: Increase mic bias resistor to 2.7K to match TLV320 datasheet.
    [audio_codec.kicad_sch, ezDV.kicad_sch]
2023-01-02 Fixes to make voice keyer settings updates more reliable.
    [Application.cpp]
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2023-01-03 v0.6 board: more tweaking of radio mic line to ensure it's inside of a Faraday cage.
    [ezDV.kicad_pcb]
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2023-01-03 v0.6 board: Reroute headers on LHS to allow access to all buttons.
    [esp32s3.kicad_sch, ezDV.kicad_pcb, ezDV.kicad_sch]
2023-01-03 v0.6 board: readd OSHW logo because it apparently goes away every time the PCB is synced with the schematic.
    [ezDV.kicad_pcb]
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2023-01-07 v0.6 board: fix DRC errors.
    [ezDV.kicad_pcb]
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2023-01-13 Fix intermittent crash on shutdown.
    [Application.cpp]
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2023-01-14 v0.7 board: fix DRC violations that slipped through the cracks.
    [ezDV.kicad_pcb]
2023-01-18 Fix startup watchdog timeout due to v0.6 board changes.
    [Application.cpp]
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2023-01-20 v0.7 board: test 2 as the previous commit seemed to make it worse when simulated.
    [ezDV.kicad_pcb]
2023-01-21 Revert "v0.7 board: test 2 as the previous commit seemed to make it worse when simulated."
    This reverts commit d57c7f3da8b80e4dcbd5fb61af7fea4553e0207a.
    [ezDV.kicad_pcb]
2023-01-21 Revert "v0.7 board: reduce coupling between user and radio speaker traces."
    This reverts commit bbea4266da072f996158c25fd9f1a3046b2b5d1d.
    [ezDV.kicad_pcb]
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2023-01-21 v0.7 board: move top traces to the left of the ESP32 under the ground layer.
    [ezDV.kicad_pcb]
2023-01-21 v0.7 board: reroute top traces for TLV320 to ensure ground pour extends all the way around.
    [ezDV.kicad_pcb]
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2023-01-23 v0.7 board: fix USB traces not being fully over GND.
    [ezDV.kicad_pcb]
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2023-01-25 Reduce noise level slightly by using a different TLV320 clock config that avoids the PLL.
    [TLV320.cpp]
2023-01-25 v0.7 board: add LPF on DAC outputs to avoid aliasing noise.
    [audio_codec.kicad_sch, ezDV.kicad_pcb, ezDV.kicad_sch]
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2023-01-27 Set DOSR to 512 to improve DAC noise floor.
    [TLV320.cpp]
2023-01-27 Re-enable PLL and set DOSR to 768 (TI recommended for 8 KHz sample rate).
    Noise level dropped ~1 dB using external LPF vs DOSR = 512 and PLL off.
    Source: https://e2e.ti.com/support/audio-group/audio/f/audio-forum/773062/faq-tlv320aic-codecs-high-dac-output-noise-when-running-at-low-sampling-rates
    [TLV320.cpp]
2023-01-29 TLV320 now uses 48K sample rate to get the DAC noise as far from the passband as possible.
    [TLV320.cpp]
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2023-01-31 v0.7 board: move NPN for PTT out to ensure low impedance path to GND when activated.
    [external_interface.kicad_sch, ezDV.kicad_pcb, ezDV.kicad_sch]
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2023-02-02 v0.7 board: remove filter components as we may not actually need them.
    [audio_codec.kicad_sch, external_interface.kicad_sch, ezDV.kicad_pcb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]
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2023-02-19 Revert "TLV320 now uses 48K sample rate to get the DAC noise as far from the passband as possible."
    This reverts commit b7a40ae95485403b6c7156855583c943a26eb2a9.
    [TLV320.cpp]
2023-02-19 Revert "Got IC-705 support working again post-transition to 48K internal sample rate."
    This reverts commit 776f5c1035f503d13bb17c1a8d8d9541d6157ac3.
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2023-02-26 v0.7 board: clarify/improve cap ratings to account for TVS diode clamp voltage.
    [audio_codec.kicad_sch, ezDV.kicad_sch, power_and_usb.kicad_sch]
2023-02-26 v0.7 board: add time delay for TP4056 to avoid violating USB inrush spec.
    [ezDV.kicad_pcb, ezDV.kicad_sch, power_and_usb.kicad_sch]
2023-02-26 v0.7 board: add pi filter for USBC_VBUS to reduce noise coupling into rest of system.
    [audio_codec.kicad_sch, ezDV.kicad_pcb, ezDV.kicad_sch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]
2023-02-26 v0.7 board: resolve all ERC errors in schematic.
    [audio_codec.kicad_sch, ezDV.kicad_pcb, ezDV.kicad_sch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]
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2023-02-26 v0.7 board: add TVS protection for GPIO0/reset.
    [esp32s3.kicad_sch, ezDV.kicad_pcb, ezDV.kicad_sch]
2023-03-06 v0.7 board: add WUSB3801 and reduce TP4056 max current if USB port doesn't support >=1.5A current.
    [external_interface.kicad_sch, ezDV.kicad_pcb, ezDV.kicad_sch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]
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2023-03-11 v0.7 board:
    1. Undo addition of USB filter as LDO is able to block noise/ripple from it.
    2. Tweak LDO footprint and traces leading from it based on https://www.onsemi.jp/pub/Collateral/AN-5075.PDF (to improve yield).
    [ezDV.kicad_pcb, ezDV.kicad_sch, power_and_usb.kicad_sch]
2023-03-11 v0.7 board: USB and peripheral power should be planes and not traces due to high current consumption.
    [ezDV.kicad_pcb, power_and_usb.kicad_sch]
2023-03-11 v0.7 board: limit charging to ~700mA in high power mode to avoid exceeding 1.5A USB limit.
    [ezDV.kicad_sch, power_and_usb.kicad_sch]
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2023-03-19 Ensure correct slot is used for HTTP files.
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2023-03-25 Gradually fade PTT output between 0 and high impedance.
    This is in order to reduce audible noise coupling from the PTT line
    into the transmitted audio due to a potential schematic/PCB layout
    issue with v0.7. With this change, thumping noises are no longer
    audible on the right channel of the radio jack when in HW test mode
    (especially when in a mode that silences the radio jack).
    Note that this should *really* be fixed in hardware as the extra
    noise can still be recorded by programs like Audacity using a good
    enough sound device. This also reduces the effective PWM resolution,
    although it's very difficult for a human to notice a difference
    in LED brightness at the former resolution. TBD for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
    [LedArray.cpp, OutputGPIO.cpp]
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2023-03-31 Minimum required for ezDV to perform initial connection to Flex radios.
    [SettingsMessage.h]
2023-04-01 Add VITA thread and audio pipe linkage for Flex connectivity.
    [Application.cpp]
2023-04-01 Support the voice keyer when using Flex radios.
    [Application.cpp]
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2023-04-04 v0.8 board: Increase TP4056 CE capacitor value from 1uF to 10uF.
    This is due to the USB inrush test failing (TP4056 turns on after 15ms, not >100ms as required).
    While 1uF should have been sufficient combined with a 100K resistor in theory, DC bias properties
    for SMD X5R/X7R capacitors resulted in losing ~75% of the rated capacitance on 0402 sized parts.
    This calculates to an actual RC time constant of ~0.023s instead of >= 0.1s.
    (Note: in limited testing, I do not seem to be seeing any overcurrent errors or other weirdness
    when plugging ezDV into USB hosts/power supplies. This may not be a huge issue in practice, but
    should still be fixed in the interest of ensuring a good user experience.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
    [audio_codec.kicad_sch, esp32s3.kicad_sch, external_interface.kicad_sch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]
2023-04-04 v0.8 board: add a bit more spacing between audio out traces/vias to knock out any remaining crosstalk.
    [ezDV.kicad_pcb]
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2023-04-04 Avoid going into TX if the user is just using the TUNE button to trigger it.
2023-04-06 Fix issue preventing NET LED from flashing after losing connection to a Flex radio.
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2023-04-07 Flex support: Initial code for dynamically adjusting filters on mode changes.
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2023-04-16 X/Y positions of buttons were wrong in the last enclosure edit.
    [enclosure-bottom.stl, enclosure-top.stl, enclosure.scad]
2023-04-18 Refactor DVTask wake/sleep messaging to avoid issues with missed replies.
    [Application.cpp]
2023-04-18 Add button to allow users to reboot ezDV.
    [Application.cpp]
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2023-04-20 Enable Wi-Fi QoS on Flex VITA socket to reduce drops.
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2023-05-10 Flex support: fix bug preventing PTT from releasing when using microphone attached to radio.
2023-05-20 Improve connection issues discovered during Dayton.
    [enclosure-top.stl]
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2023-07-15 Fix bug preventing shutdown when Wi-Fi is not enabled.
    [MAX17048.cpp]
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2023-08-05 When sending Flex message, call event handler on socket failure to ensure that cleanup occurs.
2023-08-06 v0.8 board: add TPS259533 eFuse to prevent stupid hookup mistakes :)
    [ezDV.kicad_pcb, ezDV.kicad_sch, power_and_usb.kicad_sch]
2023-08-20 Flex: fix bug preventing FreeDV Reporter from listing ezDV unless current slice is also the TX slice.
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2023-08-31 Flex: fix issue where old audio is sent to SmartSDR as soon as the user switches to FDVU/FDVL.
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2023-09-05 More changes to prevent words from cutting off at the end of transmissions:
    1. Add one frame of silence at the end of each transmission if a FreeDV mode is active.
    2. For IC-705, defer sending the CI-V command to release PTT until its own TX buffer is empty.
2023-09-06 Settings related bugfixes:
    1. Radio tab: hide FlexRadio specific fields when disabling radio control.
    2. Wi-Fi/Radio tabs:
    * Fix bug preventing Save button from re-appearing on error.
    * Wi-Fi tab: prevent invalid pointer access when disabling Wi-Fi.
    Additionally, handler registration has been cleaned up slightly in DVTask.
    [SettingsMessage.h]
2023-09-08 Fix issue preventing filters from being set properly on initial SmartSDR startup.
2023-09-10 Use GPIO0 to detect USB power and display the charge percentage while off.
    This change requires a resistor divider on GPIO0 (suggested values: 220K/320Kohm)
    and ideally a Schottky diode to prevent current from flowing backwards towards
    USB VBUS. However, this change has no impact on previous board revisions, so
    existing ezDV boards do not need to be modded at this time.
    [Application.cpp, ButtonArray.h, main.c]
2023-09-10 Avoid duplicate wakeups from ULP.
    [main.c]
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2023-09-17 Disable fuel gauge update wakeup to prevent battery drain.
    [main.c]
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2023-09-26 Integrate changes proposed in issue #23.
    [enclosure.scad]
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2023-10-20 Fix bug peventing early sleep if battery is near dead.
    [Application.cpp, MAX17048.cpp]
2023-10-20 Slightly widen the button holes in the enclosure to allow buttons to fit.
    [enclosure-button.stl, enclosure-top.stl, enclosure.scad]
2023-11-02 Add missed check for MAX17048 enablement when processing request messages.
    [MAX17048.cpp]
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2023-11-09 Reinit GPIO0 to avoid high power consumption while sleeping.
    [main.c]
2024-02-06 Lower AGC target to prevent OVL rave party with the FT-8x7.
    [TLV320.cpp]
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2024-02-06 Refactor USB power detection so that it's more resilient to missed interrupts.
    [ButtonArray.h, MAX17048.cpp]
2024-02-08 Move v0.7 KiCAD project to avoid confusion.
    [BGA4N35P2X2_64X64X33N.step, ESD122DMXR.step, TP4056.step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]
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2024-02-10 Add glitch filter to GPIOs to prevent buttons from reading as being forced down on boot.
2024-02-10 Copy updated UDP retry logic to Flex driver.
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2024-02-10 Fix bug preventing Wi-Fi scan from actually stopping when user switches away from Wi-Fi tab on web UI.
2024-02-11 Reset PTT state on reconnection in case the user releases PTT before the latter.
2024-02-20 Prevent change of WirelessTask state from tasks other than its own.
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2024-02-20 Building as a C++ file causes problems with the sample rate conversion for some reason.
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2024-03-08 Revert "Experiment: different AGC config for user channel."
    This reverts commit 13cbe9b70afcf6ea32716463f14fc4f2b07dbc3e.
    [TLV320.cpp]
2024-03-16 Increase priority of audio chain to prevent dropouts.
    [TLV320.cpp]
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2024-03-17 Fix trace messages in async static file handler.
2024-03-17 Increase maximum number of open sockets in HTTP server to avoid intermittent loading errors while accessing the web interface.
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2024-03-24 Free up a bit more memory so that we don't get heap full crashes while handling Wi-Fi management frames.
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2024-03-24 Bump up stack and queue sizes based on crashes encountered.
    [MAX17048.cpp]
2024-03-24 Improve algorithm to determine the number of packets to send.
    The Flex code now keeps a running total of how much extra time is required
    in between timer ticks. It then calculates the number of extra VITA packets
    required to be sent based on how many us we're behind what the radio expects,
    ensuring that the radio receives on average the correct number of packets
    in a given time interval.
2024-03-25 Screw it, transmit packets to the Flex as quickly as it can handle them.
2024-03-25 Broadcast sync state every time through the loop (preventing stuck 'sync' LED issue).
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2024-03-30 Lower priority of FreeDV Reporter reporting to reduce jitter.
2024-03-30 Timers should be handled ASAP (another jitter reduction tactic).
2024-03-30 Place upper bound on FlexRadio VITA-49 jitter to reduce dropouts.
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2024-04-05 Reduce internal heap consumption when configured for Flex.
    [Application.cpp]
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2024-05-31 Flex: fix issue where changing to FDVL does not properly update filter.
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2024-07-14 Fix bug causing crash when network interface loses connection.
    [NetworkTask.cpp]
2024-07-23 Fix crash issue on shutdown.
    [NetworkTask.cpp]
2024-07-24 Flex: fix issue preventing reconnection if there's a sudden power cut to the radio.
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2026-11-05 Add RADE V2 and run the TLV320 at 16 kHz.
    RADE V2 replaces FreeDV 700D, 700E and 1600 (modes are now analog and
    RADE V2). The receiver and transmitter run on both cores with int8
    weights on the ESP32-S3's PIE unit and a quarter-width FARGAN.
    - components/rade_v2, components/opus_dnn: RADE V2 (from rade_c) and the
    parts of Opus's DNN code it needs, with ezDV's changes kept here (see
    each README).
    - tools/rade_models: generates the int8 weights
    (firmware/models/q8_models.bin, flashed to a new "models" partition)
    and their layer tables.
    - The TLV320 runs at 16 kHz for mic and speaker; the radio side stays at
    8 kHz, resampled in the driver (new audio/Resampler). SmartSDR's 24 kHz
    he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

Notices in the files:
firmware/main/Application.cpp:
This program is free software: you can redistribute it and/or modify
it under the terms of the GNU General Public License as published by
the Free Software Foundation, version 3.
